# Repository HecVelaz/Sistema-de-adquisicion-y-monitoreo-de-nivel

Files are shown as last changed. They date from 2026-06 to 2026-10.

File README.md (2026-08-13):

````markdown
# Sistema de adquisición y monitoreo de nivel de agua

## Estación de medición de nivel — Arroyo Mburicao

---

## Descripción

Sistema de adquisición y monitoreo de nivel de agua desarrollado para medir el nivel de un arroyo mediante un sensor de nivel con comunicación RS485.

El sistema utiliza una PCB propia basada en ESP32-S3, almacenamiento local en tarjeta microSD, reloj de tiempo real DS3231M y transmisión de datos mediante un módem DTU GPRS hacia un servidor remoto.

Cada medición es registrada con un `timestamp` generado a partir del RTC y se guarda localmente en la tarjeta microSD. Luego, el dato es enviado al servidor con la trama:

```
d=timestamp,nivel
````

Además, el sistema implementa un mecanismo **Store and Forward**, que permite conservar los datos no enviados en caso de falla de comunicación y reenviarlos automáticamente cuando la conexión se restablece.

---
## Datos obtenidos con el sensor 
Seguimiento de los valores obtenidos por el prototipo durante aproximadamente 9 meses de seguido, datos obtenidos en la cuenca del arroyo mburicao Colegio San Ignacio de Loyolas.

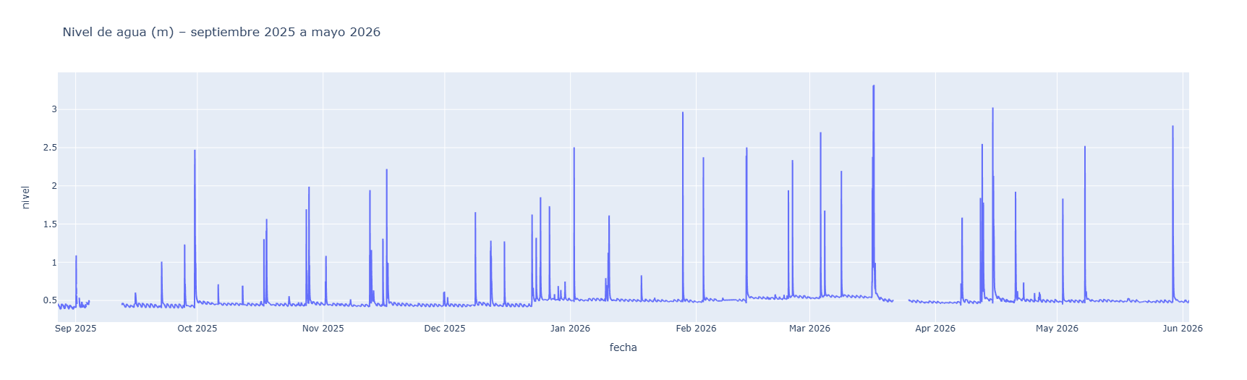
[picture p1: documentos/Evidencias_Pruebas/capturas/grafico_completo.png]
Imagen grafana

## Imágenes del hardware

| Render 3D / PCB | PCB diseñada | Placa montada |
| --- | --- | --- |
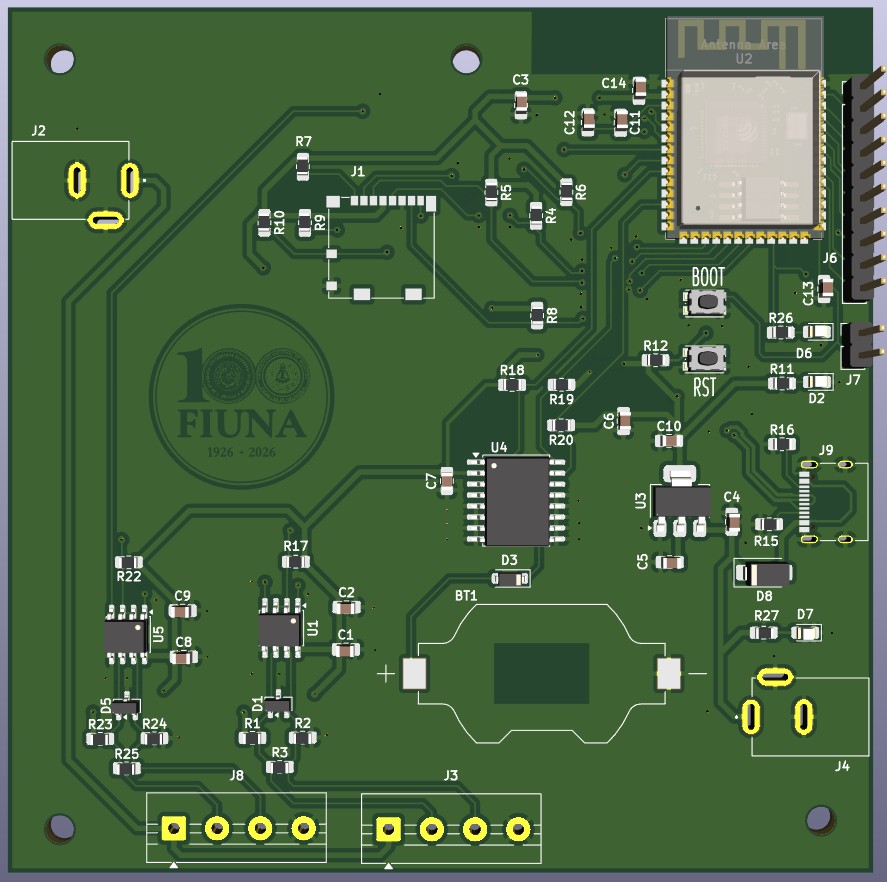
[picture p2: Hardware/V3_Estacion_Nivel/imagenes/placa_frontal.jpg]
Render 3D
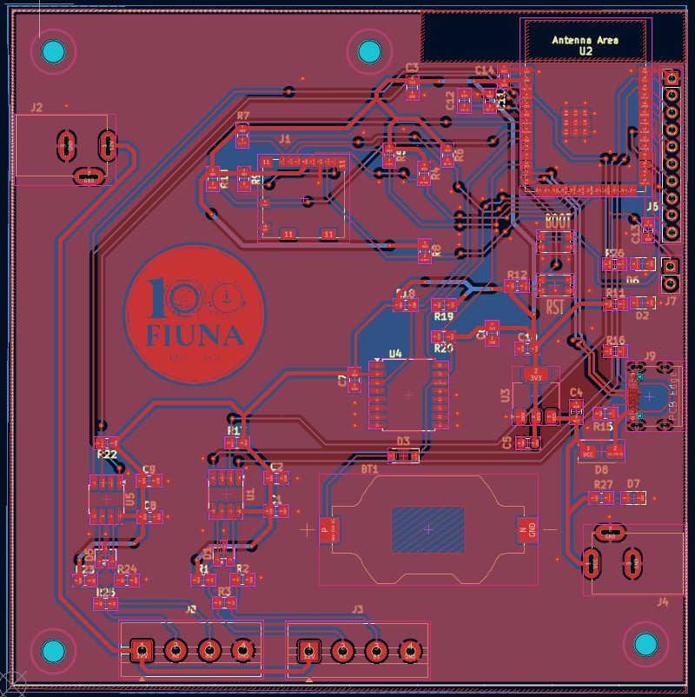
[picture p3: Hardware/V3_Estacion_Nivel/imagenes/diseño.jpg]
PCB diseñada
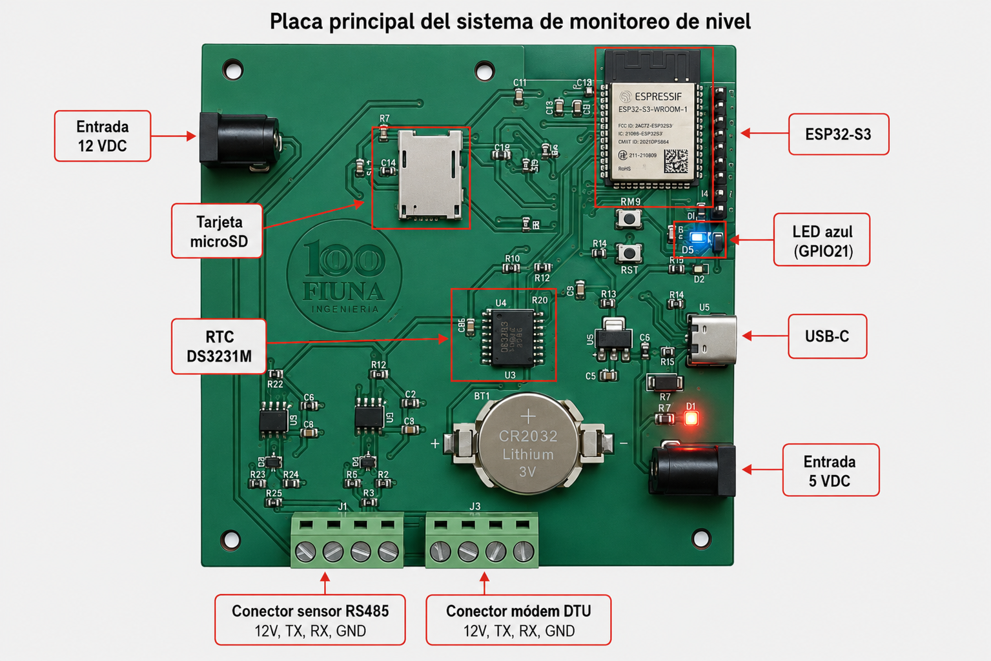
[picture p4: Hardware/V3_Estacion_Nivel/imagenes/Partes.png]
Placa montada
|  |  |  |

---

## Características principales

* Microcontrolador **ESP32-S3** con firmware desarrollado en **ESP-IDF**.
* Sensor de nivel de agua con comunicación **RS485 / Modbus RTU**.
* Transmisión de datos mediante **módem DTU GPRS RS485**.
* Almacenamiento local en tarjeta **microSD**.
* Registro histórico en archivo `datalog.csv`.
* Cola de datos pendientes en archivo `temp.csv`.
* Reloj de tiempo real **DS3231M** para generación de timestamps.
* Alimentación mediante **mini UPS**.
* Salida de **12 V** para sensor de nivel y módem DTU.
* Alimentación de **5 V** para el ESP32-S3.
* Regulación interna de **3.3 V** para periféricos.
* Indicadores LED de alimentación y funcionamiento.
* LED azul conectado al **GPIO21** como indicador de lectura válida.
* Mecanismo **Store and Forward** para evitar pérdida de datos.
* Reenvío automático de datos pendientes.
* Repositorio organizado en documentación, hardware, software y evidencias.

---

## Estructura del repositorio

```text
Sistema de adquisicion y monitoreo de nivel/
│
├── documentos/
│   │
│   ├── Evidencias_Pruebas/
│   │   │
│   │   ├── capturas/
│   │   │   ├── Placa.jpg
│   │   │   ├── Partes.png
│   │   │   ├── store_forward.png
│   │   │   ├── datalog_csv.png
│   │   │   └── ...
│   │   │
│   │   └── videos/
│   │       ├── prueba_sensor.mp4
│   │       ├── prueba_sdcard.mp4
│   │       ├── prueba_modem.mp4
│   │       ├── prueba_integrada.mp4
│   │       └── ...
│   │
│   └── reportes/
│       ├── informe_parcial/
│       ├── informe_final/
│       └── ...
│
├── Hardware/
│   │
│   ├── V3_Estacion_Nivel/
│   │   │
│   │   ├── imagenes/
│   │   │   ├── placa_frontal.jpg
│   │   │   ├── placa_posterior.jpg
│   │   │   ├── diseño.jpg
│   │   │   ├── Partes.png
│   │   │   └── ...
│   │   │
│   │   ├── planos/
│   │   ├── step/
│   │   ├── Librerias Kicad/
│   │   └── fabrication_files_G10/
│   │
│   └── Estacion_Nivel_V3.csv
│
├── Software/
│   │
│   ├── Firmware_Final/
│   │   │
│   │   ├── components/
│   │   │   │
│   │   │   ├── led/
│   │   │   │   ├── led_blink.c
│   │   │   │   └── led_blink.h
│   │   │   │
│   │   │   ├── modem_dtu/
│   │   │   │   ├── modem_dtu.c
│   │   │   │   └── modem_dtu.h
│   │   │   │
│   │   │   ├── reloj/
│   │   │   │   ├── reloj.c
│   │   │   │   └── reloj.h
│   │   │   │
│   │   │   ├── sdcard/
│   │   │   │   ├── sdcard.c
│   │   │   │   └── sdcard.h
│   │   │   │
│   │   │   └── sensor_rs485/
│   │   │       ├── sensor_rs485.c
│   │   │       └── sensor_rs485.h
│   │   │
│   │   ├── src/
│   │   │   └── main.c
│   │   │
│   │   ├── CMakeLists.txt
│   │   ├── platformio.ini
│   │   └── sdkconfig.freenove_esp32_s3_wroom
│   │
│   └── Firmware_Pruebas/
│       │
│       ├── components/
│       │   │
│       │   ├── led/
│       │   │   ├── led_blink.c
│       │   │   └── led_blink.h
│       │   │
│       │   ├── modem_dtu/
│       │   │   ├── dtu.c
│       │   │   └── dtu.h
│       │   │
│       │   ├── reloj/
│       │   │   ├── reloj.c
│       │   │   └── reloj.h
│       │   │
│       │   ├── sdcard/
│       │   │   ├── sdcard.c
│       │   │   └── include/
│       │   │       └── sdcard.h
│       │   │
│       │   └── sensor_rs485/
│       │       └── sensor_rs485.c
│       │
│       ├── src/
│       │   └── main.c
│       │
│       ├── CMakeLists.txt
│       ├── platformio.ini
│       └── sdkconfig.freenove_esp32_s3_wroom
│
├── .gitattributes
├── LICENSE
└── README.md
```

---

## Hardware

### Diagrama de bloques

```text
                    Mini UPS
             ┌────────┼────────┐
             │        │        │
            12 V     12 V      5 V
             │        │        │
             ▼        ▼        ▼
     Sensor de     Módem     ESP32-S3
     nivel RS485   DTU       Control principal
             │        │        │
             │        │        ├── RTC DS3231M   ── I2C
             │        │        ├── microSD       ── SPI
             │        │        ├── LED indicador ── GPIO21
             │        │        ├── Sensor nivel  ── RS485 / UART1
             │        │        └── Módem DTU     ── RS485 / UART2
             │        │
             │        └────── Internet / GPRS
             │                 │
             ▼                 ▼
        Medición de nivel   Servidor remoto
```

---

## Alimentación

| Módulo | Tensión | Descripción |
| --- | ---: | --- |
| Sensor de nivel RS485 | 12 V | Alimentación del sensor de medición de nivel |
| Módem DTU GPRS | 12 V | Alimentación del módulo de comunicación remota |
| ESP32-S3 | 5 V | Alimentación mediante jack o USB-C |
| RTC DS3231M | 3.3 V | Alimentación desde regulación interna |
| microSD | 3.3 V | Alimentación desde regulación interna |
| LED indicador | 3.3 V | Indicador visual de funcionamiento |

---

## Pinout principal

| Módulo | Señal | GPIO ESP32-S3 | Interfaz | Función |
| --- | --- | ---: | --- | --- |
| Sensor nivel RS485 | TX / DI | GPIO1 | UART1 TX | Envío de comando Modbus |
| Sensor nivel RS485 | RX / RO | GPIO2 | UART1 RX | Recepción de respuesta |
| Sensor nivel RS485 | DE/RE | GPIO4 | Control RS485 | Control de transmisión y recepción |
| Módem DTU | TX / DI | GPIO5 | UART2 TX | Envío de trama al módem |
| Módem DTU | RX / RO | GPIO6 | UART2 RX | Recepción de respuesta |
| Módem DTU | DE/RE / RTS | GPIO7 | Control RS485 | Control de dirección RS485 |
| RTC DS3231M | SDA | GPIO8 | I2C SDA | Datos del RTC |
| RTC DS3231M | SCL | GPIO9 | I2C SCL | Reloj del RTC |
| RTC DS3231M | SQW/INT | GPIO16 | Entrada digital | Señal reservada |
| microSD | CS | GPIO10 | SPI CS | Selección de tarjeta |
| microSD | MOSI | GPIO11 | SPI MOSI | Datos hacia microSD |
| microSD | CLK | GPIO12 | SPI CLK | Reloj SPI |
| microSD | MISO | GPIO13 | SPI MISO | Datos desde microSD |
| microSD | DET | GPIO15 | Entrada digital | Detección de tarjeta |
| LED indicador | LED Blink | GPIO21 | GPIO salida | Indicador de lectura válida |

---

## Software

El firmware del ESP32-S3 está desarrollado en lenguaje C utilizando **PlatformIO** con framework **ESP-IDF**.

### Módulos del firmware

| Módulo | Descripción |
| --- | --- |
| `main.c` | Flujo principal del sistema: inicialización, medición, guardado y envío |
| `reloj` | Manejo del RTC DS3231M y generación de timestamp |
| `sensor_rs485` | Lectura del sensor de nivel mediante RS485 |
| `sdcard` | Montaje de microSD, escritura en `datalog.csv` y manejo de `temp.csv` |
| `modem_dtu` | Envío de trama al servidor mediante módem DTU |
| `led` | Indicador visual de lectura válida o actividad del sistema |

---

## Ciclo de operación

El ciclo principal del sistema se resume en:

```text
Medir → Validar → Guardar → Enviar → Confirmar → Reenviar si falló
```

### Flujo general

```text
Inicio
  ↓
Inicializar RTC, SD, sensor RS485, módem DTU, LED y tarea de pendientes
  ↓
Leer hora actual del RTC
  ↓
Esperar próximo intervalo de medición
  ↓
Leer nivel con sensor RS485
  ↓
¿Lectura válida?
  ├── NO → Reintentar lectura
  │          ↓
  │      ¿Falló luego de los intentos?
  │          ├── SÍ → Registrar error y esperar próximo intervalo
  │          └── NO → Continuar
  │
  └── SÍ
       ↓
Generar timestamp
  ↓
Guardar dato en datalog.csv
  ↓
Generar trama d=timestamp,nivel
  ↓
Enviar trama mediante módem DTU
  ↓
¿Servidor responde OK?
  ├── SÍ → Ciclo finalizado y esperar próximo intervalo
  └── NO → Guardar dato en temp.csv
            ↓
         Queda pendiente para Store and Forward
            ↓
         Esperar próximo intervalo
```

---

## Formato de datos

### Registro local en microSD

Archivo:

```text
datalog.csv
```

Formato:

```text
timestamp,nivel
```

Ejemplo:

```text
1779617700,0.931
```

---

### Datos pendientes

Archivo:

```text
temp.csv
```

Formato:

```text
timestamp,nivel
```

Este archivo almacena temporalmente los datos que no pudieron ser enviados al servidor.

---

### Trama enviada al servidor

Formato:

```text
d=timestamp,nivel
```

Ejemplo:

```text
d=1779617700,0.931
```

Respuesta esperada del servidor:

```text
OK
```

---

## Store and Forward

El mecanismo **Store and Forward** permite evitar la pérdida de datos cuando ocurre una falla de comunicación.

Funcionamiento:

1. El sistema mide el nivel de agua.
2. El dato se guarda siempre en `datalog.csv`.
3. El sistema intenta enviarlo al servidor.
4. Si el servidor responde `OK`, el ciclo finaliza correctamente.
5. Si el servidor no responde o existe error de comunicación, el dato se guarda en `temp.csv`.
6. Una tarea en segundo plano revisa los datos pendientes.
7. Cuando la comunicación se restablece, los datos se reenvían automáticamente.
8. Al recibir `OK`, el dato pendiente se elimina de `temp.csv`.

---

## Pruebas realizadas

| Prueba | Descripción | Estado |
| --- | --- | --- |
| Sensor RS485 | Lectura de nivel mediante comunicación Modbus RTU | Correcto |
| RTC DS3231M | Lectura de fecha y hora mediante I2C | Correcto |
| microSD | Detección, montaje, escritura y lectura de archivos | Correcto |
| Módem DTU | Envío de trama `d=timestamp,nivel` al servidor | Correcto |
| Sistema integrado | Lectura, almacenamiento y transmisión completa | Correcto |
| Store and Forward | Guardado y reenvío de datos pendientes | Correcto |

---

## Resultados

Durante las pruebas finales se verificó que el sistema puede:

* Medir correctamente el nivel de agua.
* Generar un timestamp para cada medición.
* Guardar datos localmente en `datalog.csv`.
* Enviar datos al servidor remoto.
* Detectar fallas de comunicación.
* Guardar datos no enviados en `temp.csv`.
* Reenviar automáticamente datos pendientes.
* Mantener el timestamp original de cada medición reenviada.

---

## Evidencias

Las evidencias del funcionamiento del sistema se encuentran en:

```text
documentos/Evidencias_Pruebas/
```

Estructura recomendada:

```text
documentos/Evidencias_Pruebas/
│
├── capturas/
│   ├── Placa.jpg
│   ├── Partes.png
│   ├── datalog_csv.png
│   ├── store_forward.png
│   └── ...
│
└── videos/
    ├── prueba_sensor.mp4
    ├── prueba_sdcard.mp4
    ├── prueba_modem.mp4
    ├── prueba_integrada.mp4
    └── ...
```

Cada carpeta puede incluir capturas, logs y enlaces a videos de prueba.

---

## Costos

La lista de materiales y costos se encuentra en la carpeta de hardware del proyecto.

Ruta sugerida:

```text
Hardware/V3_Estacion_Nivel/
```

Archivo de costos o BOM:

```text
Estacion_Nivel_V3.csv
```

También pueden incluirse archivos adicionales dentro de:

```text
Hardware/V3_Estacion_Nivel/fabrication_files_G10/
```

---

## Requisitos de desarrollo

* Visual Studio Code
* PlatformIO
* ESP-IDF
* ESP32-S3
* Tarjeta microSD
* Sensor de nivel RS485
* Módem DTU GPRS RS485
* RTC DS3231M
* Mini UPS

---

## Compilación y carga

Desde PlatformIO:

```bash
pio run
pio run --target upload
pio device monitor
```

También puede utilizarse el entorno gráfico de PlatformIO en Visual Studio Code.

---

## Equipo

| Integrante | Contacto |
| --- | --- |
| Héctor Dejesús Velázquez Ojeda | [hvelazquez@fiuna.edu.py](mailto:hvelazquez@fiuna.edu.py) |
| Mathias Ramón Aguilar DelValle | [maguilar@fiuna.edu.py](mailto:maguilar@fiuna.edu.py) |
| Mauricio Iván Tullo Estigarribia | [mauritullo@fiuna.edu.py](mailto:mtullo@fiuna.edu.py) |

Institución: Universidad Nacional de Asunción — Facultad de Ingeniería
Carrera: Ingeniería Mecatrónica
Cátedra: Proyecto 3

---

## Licencia
* Firmware: MIT
* Documentación: MIT

---

## Estado del proyecto

El proyecto se encuentra en etapa funcional, con pruebas aisladas e integradas realizadas correctamente.

El sistema permite adquirir, almacenar y transmitir datos de nivel de agua, incorporando respaldo local y reenvío automático ante fallas de comunicación.

```
```

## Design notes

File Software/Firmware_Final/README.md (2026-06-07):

# Firmware Final

Esta carpeta contiene la versión final del firmware desarrollado para la estación de adquisición de nivel.

## Descripción

El firmware fue desarrollado utilizando **PlatformIO** y el framework **ESP-IDF** para el microcontrolador **ESP32-S3-WROOM-1**.

Las principales funciones implementadas son:

* Lectura del sensor ultrasónico de nivel mediante comunicación RS485.
* Obtención de fecha y hora mediante el RTC DS3231M.
* Almacenamiento local de mediciones en tarjeta microSD.
* Envío de datos al servidor remoto mediante módem DTU GPRS.
* Implementación del mecanismo **Store and Forward** para recuperación automática de datos pendientes.
* Ejecución de tareas en segundo plano mediante FreeRTOS.
* Protección de recursos compartidos mediante mutex.
* Indicadores visuales mediante LED de estado.

## Estructura principal

* `src/` : Código fuente principal.
* `components/` : Módulos desarrollados para sensor, RTC, SD, DTU y periféricos.
* `include/` : Archivos de cabecera.
* `platformio.ini` : Configuración del proyecto PlatformIO.

## Estado

Versión funcional validada mediante pruebas integradas de lectura, almacenamiento local, transmisión remota y recuperación de datos pendientes.
## Nota

A diferencia de la carpeta `Firmware_Pruebas`, el firmware contenido en esta carpeta corresponde a la versión final integrada del sistema y no requiere habilitar o deshabilitar módulos manualmente para su funcionamiento normal.

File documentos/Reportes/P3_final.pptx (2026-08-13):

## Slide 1

Sistema de adquisición y monitoreo de nivel de agua

Héctor Velázquez, Mathias Aguilar , Mauricio Tullo.

Facultad de Ingeniería , Universidad Nacional de Asunción.

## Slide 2

Esquema

Introducción y Contexto

Objetivo del proyecto

Sistema propuesto

Diseño Electrónico y PCB

Integración física y costos

Firmware

Pruebas y resultados

Conclusione y trabajos futuros

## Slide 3

Introducción y contexto del problema

Contexto

Monitoreo de cauces urbanos

Registro histórico del nivel

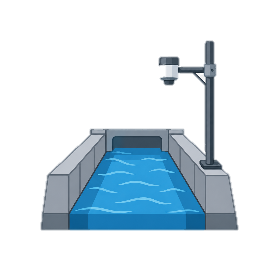
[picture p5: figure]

Problema

Aumento rápido del nivel

Riesgo de inundación

Necesidad

Datos periódicos y confiables

Base para alerta y predicción

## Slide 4

Objetivo del proyecto

Desarrollar una estación basada en ESP32-S3 capaz de medir, almacenar y transmitir datos de nivel de agua hacia un servidor remoto.

Con respaldo local ante fallas de comunicación.

Medir

Nivel de agua
mediante RS485

Almacenar

Registro local en microSD

Transmitir

Datos hacia servidor remoto

Respaldar

Datos ante fallas de comunicación

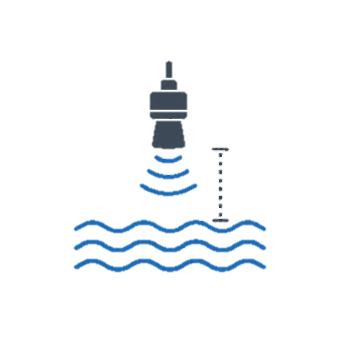
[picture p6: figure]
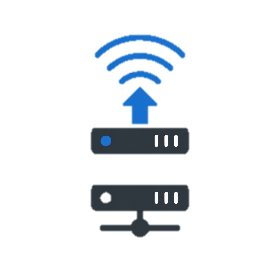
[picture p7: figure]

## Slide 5

Sistema propuesto

Arquitectura de adquisición, almacenamiento y transmisión.

Sensor de Nivel
Medición de nivel

RTC DS3231M
Fecha y hora

ESP32-S3
Unidad Central

MicroSD
Registro local

Módem DTU GPRS
Transmisión de datos

Servidor remoto
Recepción de datos

Mini UPS | Alimentación del sistema: 12 V / 5 V

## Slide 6

Esquemas electrónicos

Subsistemas implementados en la PCB.

Alimentación

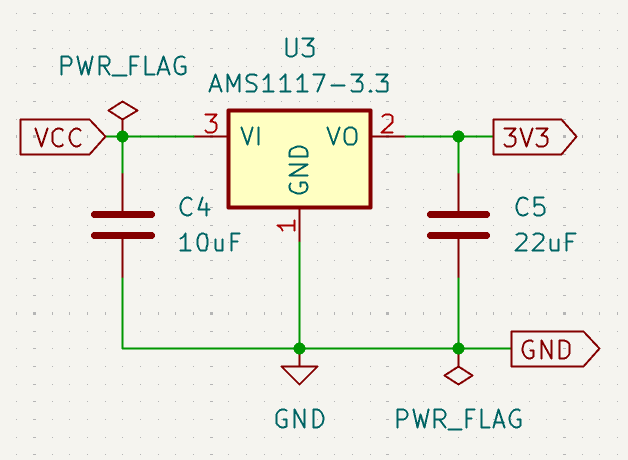
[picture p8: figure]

ESP32-S3

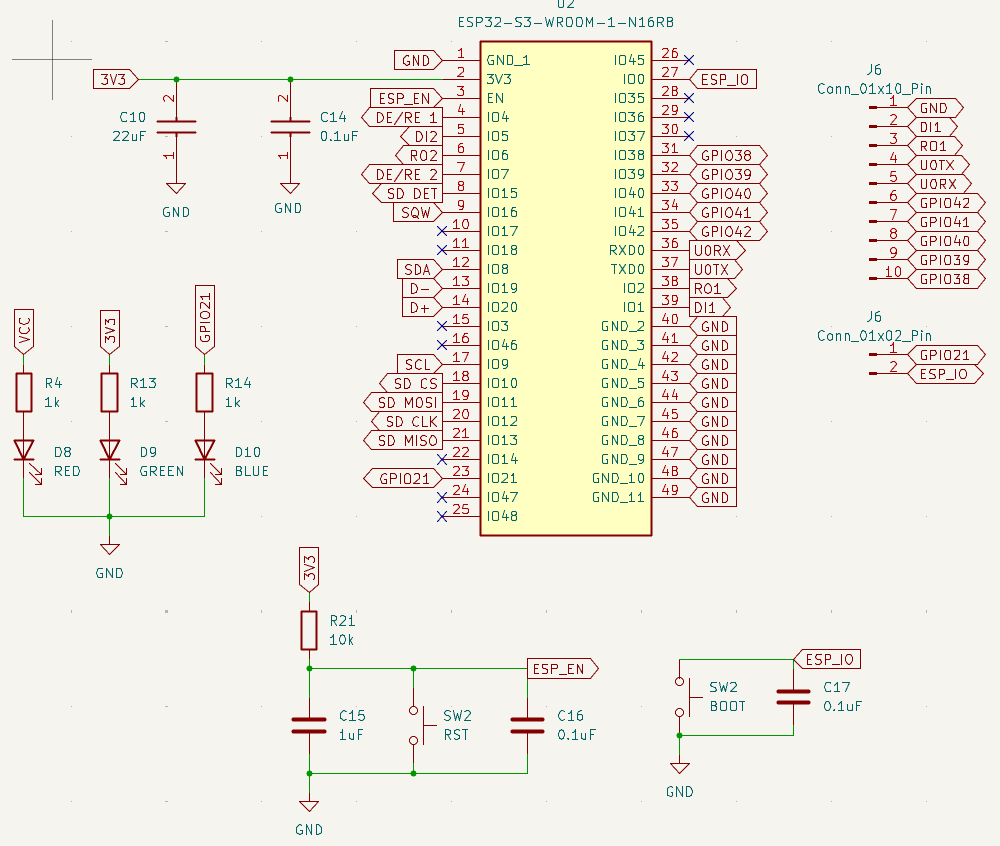
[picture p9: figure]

RTC DS3231M

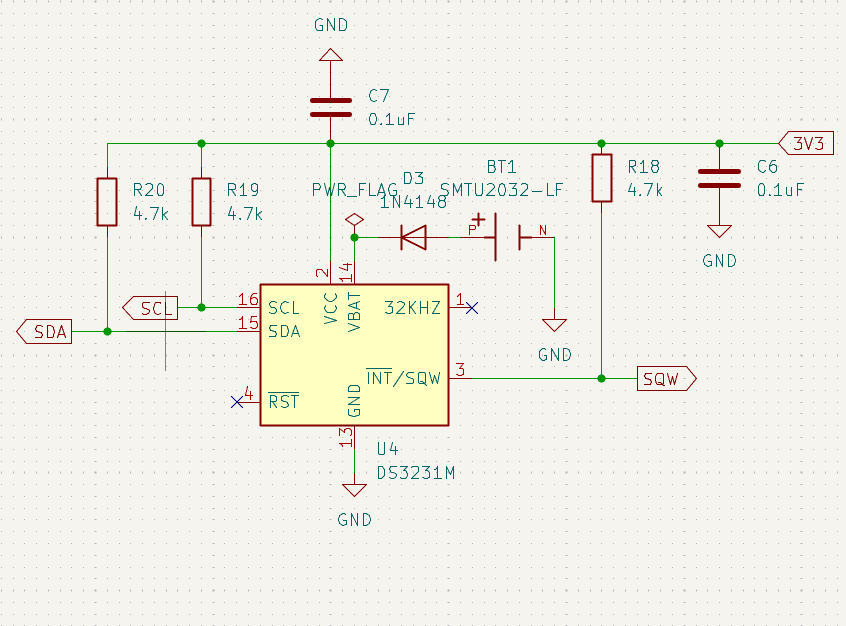
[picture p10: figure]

microSD

USB-C

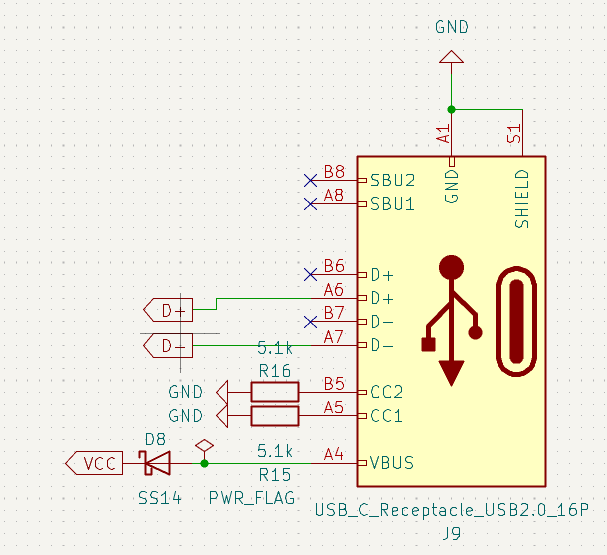
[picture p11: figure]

Transceptor TTL-RS485

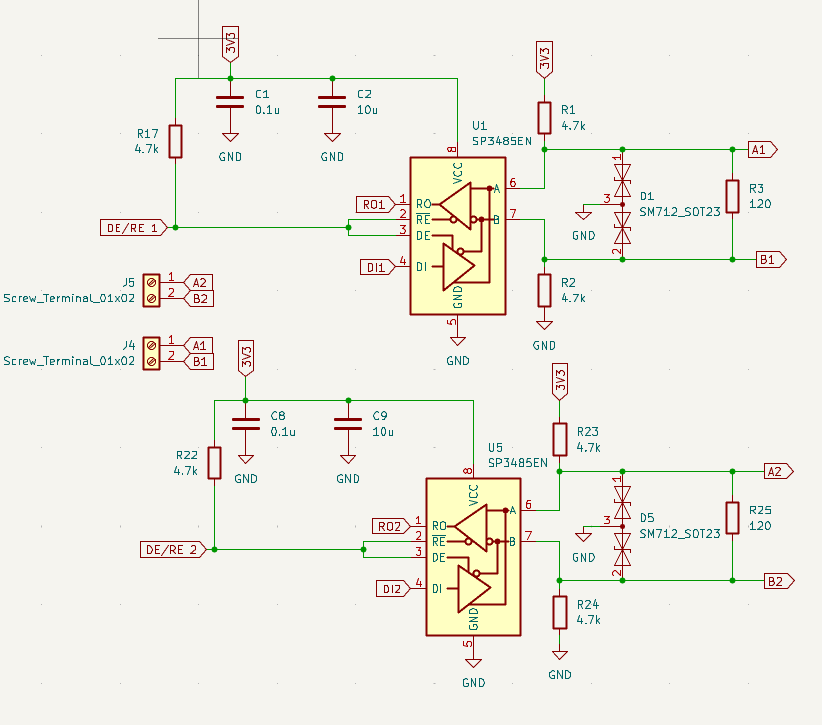
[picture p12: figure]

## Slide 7

Alimentación

Componentes utilizados
- AMS1117-3.3
- Capacitor 10 µF
- Capacitor 22 µF
- Entrada VCC
- Salida 3V3
- GND

Se utilizó el AMS1117-3.3 para generar una línea estable de 3.3 V a partir de VCC.
Esta tensión alimenta los periféricos de baja potencia del sistema, como RTC y microSD.
Los capacitores de entrada y salida permiten estabilizar la regulación y reducir variaciones de tensión.

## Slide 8

ESP32-S3

Componentes utilizados
• ESP32-S3-WROOM-1
• LED rojo
• LED verde
• LED azul
• Pulsador BOOT
• Pulsador RESET
• Resistencias limitadoras
• Capacitores de desacoplo

El ESP32-S3 funciona como unidad central del sistema, coordinando la lectura del sensor, el RTC, la microSD y el módem DTU.
Los LEDs permiten verificar visualmente estados de alimentación y operación, mientras que los pulsadores BOOT y RESET facilitan la carga y reinicio del firmware.

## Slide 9

RTC DS3231M

Componentes utilizados
• RTC DS3231M
• Batería CR2032
• Portapila SMTU2032
• Resistencias pull-up 4.7 kΩ
• Capacitores 0.1 µF
• Diodo 1N4148
• Línea I2C: SDA / SCL

Referencia funcional: módulo comercial RTC DS3231.
El diseño implementado integra únicamente el RTC DS3231M, la alimentación, las líneas I2C y el respaldo con batería.
No se incluyó la memoria EEPROM del módulo comercial, ya que no era necesaria para la función de timestamp del sistema.

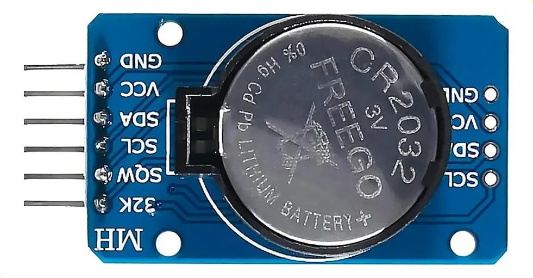
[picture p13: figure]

El bloque RTC se tomó como referencia funcional de módulos comerciales DS3231, adaptando solo las conexiones necesarias para la PCB: SDA, SCL, 3.3 V, GND y respaldo con batería.

Referencia funcional: módulo comercial RTC DS3231.

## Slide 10

microSD

Componentes utilizados
• Conector microSD
• Resistencias pull-up 10 kΩ
• Capacitor 0.1 µF
• Interfaz SPI: CS, MOSI, CLK, MISO
• Señal de detección SD_DET
• Alimentación 3.3 V

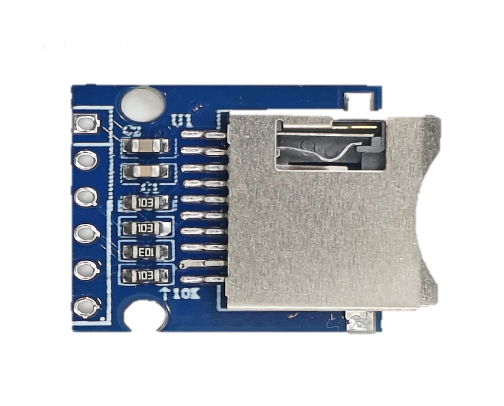
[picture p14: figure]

La microSD permite conservar localmente las mediciones del sistema en datalog.csv y los datos pendientes en temp.csv.
La interfaz SPI permite la lectura y escritura de archivos, mientras que SD_DET verifica si la tarjeta está insertada.

Referencia funcional: módulo comercial microSD SPI.

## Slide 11

USB-C

Componentes utilizados
• Conector USB-C
• VBUS / VCC
• D+ y D-
• Resistencias 5.1 kΩ
• Diodo SS14
• GND / SHIELD

El USB-C se utiliza como entrada de 5 V y conexión de comunicación.
Las resistencias de 5.1 kΩ en CC1/CC2 permiten la detección del dispositivo, mientras que el diodo SS14 protege la línea de alimentación.

Referencia funcional: conector USB-C USB 2.0.

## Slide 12

Transceptor TTL-RS485

Componentes utilizados
• Transceptores SP3485EN
• Borneras A/B para RS485
• Resistencias de 4.7 kΩ
• Resistencias de 120 Ω
• Capacitores 0.1 µF y 10 µF
• Diodos de protección SM712
• Señales DI, RO y DE/RE

El bloque TTL–RS485 adapta las señales UART del ESP32-S3 al bus diferencial RS485.
Se implementaron dos canales: uno para el sensor de nivel y otro para el módem DTU.
Las resistencias y diodos de protección ayudan a estabilizar y proteger la comunicación.

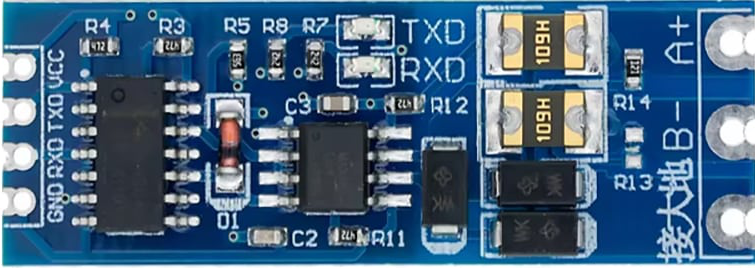
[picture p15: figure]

Referencia funcional: módulo comercial TTL–RS485 tipo MAX485.

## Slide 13

Diseño PCB

Validación del ruteo y disposición física antes del montaje.

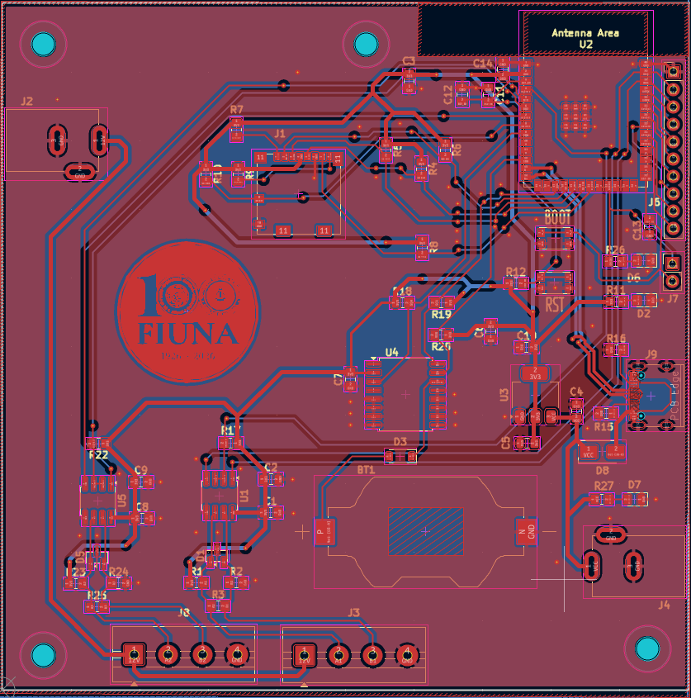
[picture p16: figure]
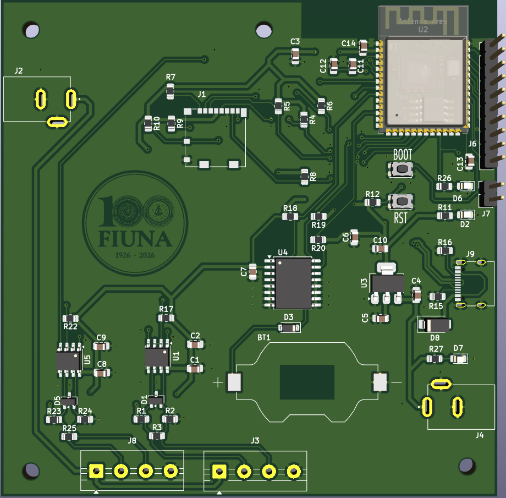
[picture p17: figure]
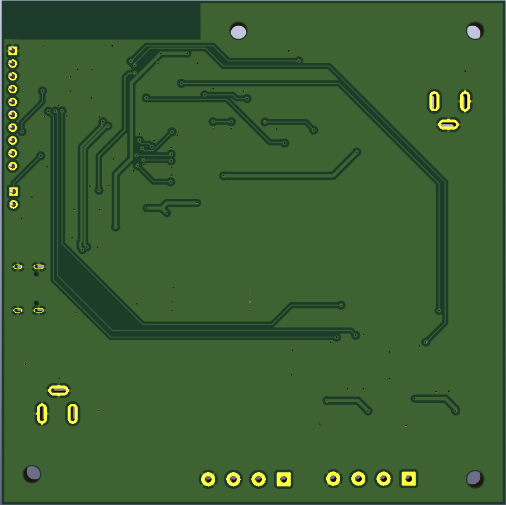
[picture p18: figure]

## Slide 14

Diseño electrónico

PCB principal integrada para conexión de módulos y alimentación.

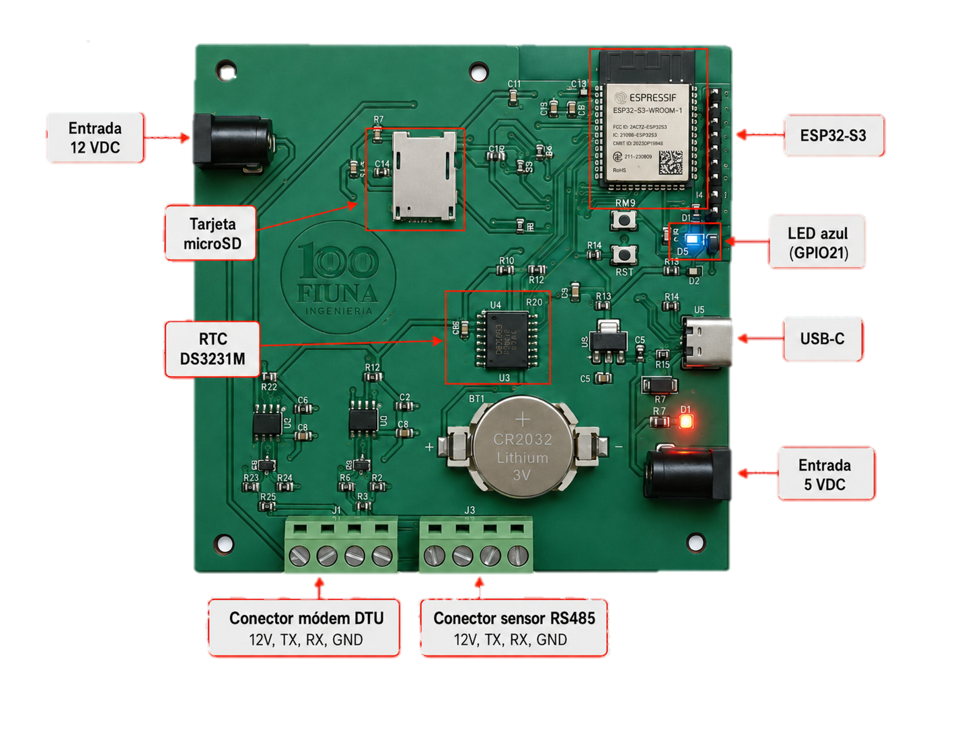
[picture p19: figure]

- ESP32-S3 como unidad central.
- RTC DS3231M y microSD incorporados.
- Conectores RS485 para sensor y módem.
- Entradas de alimentación 12 V y 5 V

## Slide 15

INTEGRACIÓN FÍSICA DEL SISTEMA

Integración física de los módulos principales del prototipo.

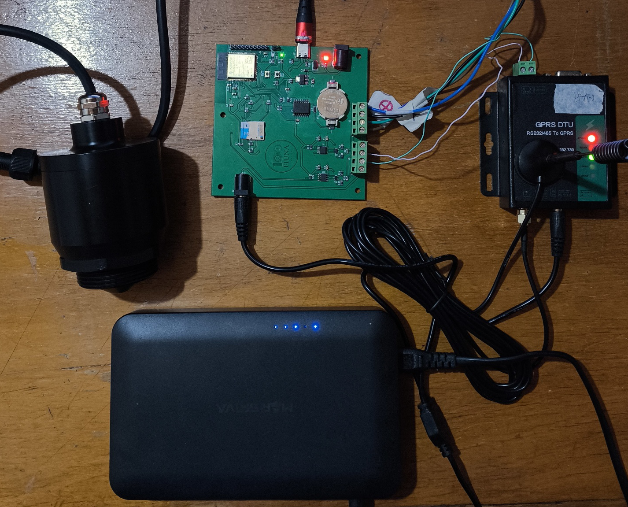
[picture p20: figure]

Componentes integrados

• Sensor de nivel RS485
• PCB principal del sistema
• Módem DTU GPRS
• Alimentación mediante Mini UPS

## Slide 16

Costo del proyecto

Estimación de materiales utilizados en el prototipo.

Ítem | Cantidad | Costo unitario | Costo total
PCB fabricada | 1 | 27,6 | 27,6
Microcontrolador ESP32-S3-WROOM-1 | 1 | 6,71 | 6,71
Transceptor RS485 (SP3485EN) | 2 | 0,8 | 1,6
Sensor de nivel RS485 (Laboratorio) | 1 | 196,33 | 196,33
Módem DTU GPRS RS485 (Laboratorio) | 1 | 21 | 21
Módulo RTC DS3231M | 1 | 13,6 | 13,6
Conector microSD | 1 | 2,55 | 2,55
Mini UPS (Laboratorio) | 1 | 46,63 | 46,63
Portapila y batería CR2032 (SMTU2032) | 1 | 2,36 | 2,36
Pulsadores SMD (RST y BOOT - B3U-1000P) | 2 | 0,8 | 1,6
Capacitores SMD (0,1 µF, 1 µF, 10 µF) | 11 | 0,34 | 3,81
Resistencias SMD varias | 16 | 0,98 | 15,68
Pasta de soldar (SN63/PB37 Tipo 4) | 1 | 12,27 | 12,27
Total comprado / incremental | 37 | 68,01 | 87,78
Total de materiales del laboratorio | 3 | 263,96 | 263,96
Total general estimado | 40 | 331,97 | 351,74

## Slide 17

Comunicaciones y alimentación

Interfaces utilizadas y niveles de tensión por módulo.

Módulo | Comunicación | Alimentación | Función
Sensor de nivel | RS485 / UART1 | 12 V | Medición de nivel
Módem DTU | RS485 / UART2 | 12 V | Envío de datos
RTC DS3231M | I2C | 3,3 V | Fecha y hora
microSD | SPI | 3,3 V | Almacenamiento
ESP32-S3 | UART / I2C / SPI / GPIO | 5 V / 3,3 V | Control central

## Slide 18

Ciclo operativo

Flujo principal de medición, almacenamiento y transmisión.

RTC
Genera timestamp

Sensor RS485
Lee el nivel de agua

microSD
Guarda datalog.csv

Módem DTU
d=timestamp,nivel

Si falla el envío

Servidor
Respuesta OK

Store and Forward
temp.csv
Reenvío automático

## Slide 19

Arquitectura del firmware

Firmware modular en ESP-IDF

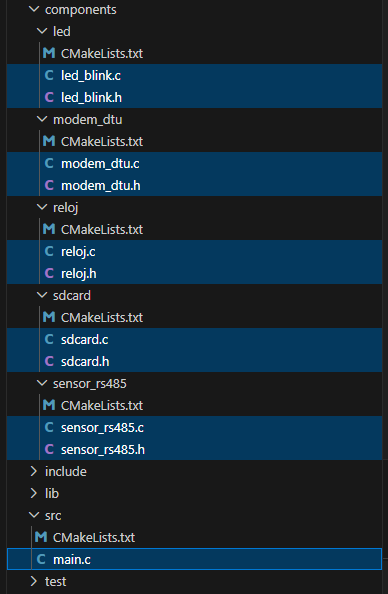
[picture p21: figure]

El firmware se dividió en componentes independientes para facilitar pruebas aisladas, mantenimiento e integración final.
Cada módulo encapsula una función específica y es llamado desde main.c.

- led_blink → señalización
- modem_dtu → envío al servidor
- reloj → fecha y hora
- sdcard → registro local
- sensor_rs485 → lectura de nivel

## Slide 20

Secuencia inicial

Secuencia inicial del firmware.

Inicio ESP32

Inicializar
Componentes
- RTC
- microSD
- Sensor
- Modem
- LED

Crear Mutex del DTU

Crear task_pendientes
Segundo plano

Loop principal
De medición

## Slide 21

Loop principal de medición

Medición, almacenamiento local y envío del dato actual.

Loop principal

Generar timestamp

Esperar s faltantes, volver al inicio

Leer hora del
RTC

Guardar en datalog.csv

Es momento del
Próximo Slot redondo ?

NO

Se envía al servidor
Con mutex

SI

Servidor respondió OK?

SI

Ciclo terminado

Leer sensor , hasta 3 intentos

NO

Lectura válida?

NO

nivel= -1.0

Guardar en temp.csv

Blink LED
Lectura válida

SI

Esperar 1 s y volver al inicio del loop

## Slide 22

Reenvío de pendientes y mutex

Store and forward ejecutado en segundo plano.

Task_pendientes BG

Esperar 5s , volver al inicio

Tomar mutex

Leer hora del
RTC

DTU libre?

NO

Se mantiene el pendiente en temp.csv
Esperar 5s y volver

Calcular tiempo hasta el próximo slot

Enviar pendiente

SI

Existe tiempo ?
Ej=mas de 35s

NO

Servidor respondió OK?

Existe dato en temp.csv?

SI

NO

Se mantiene el pendiente en temp.csv

Esperar 5s , volver al inicio

NO

Eliminar primer registro de temp.

SI

Leer primer pendiente de temp.csv

SI

Esperar 5 s y volver al inicio del loop

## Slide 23

Formato de datos

Estructura utilizada para almacenamiento local y transmisión al servidor.

Registro local

Archivo: datalog.csv

Formato: timestamp,nivel

Ejemplo: 1779617700,0.931

Envío al servidor

Trama: d=timestamp,nivel

Ejemplo: d=1779617700,0.931

timestamp = UNIX | nivel: metros

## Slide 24

Store and Forward

Mecanismo de respaldo ante fallas de comunicación.

Falla de envío

Servidor no responde o falla de comunicación

Respaldo local

Dato guardado en temp.csv

Reenvío
automático

Se transmite cuando vuelve la conexión

El timestamp original se conserva para evitar pérdida de trazabilidad

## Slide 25

Pruebas y validación

Validación por módulos y prueba del sistema completo.

Pruebas aisladas

• Sensor RS485: lectura de nivel
• RTC DS3231M: fecha y hora
• microSD: escritura y lectura
• Módem DTU: envío de trama
• LED: señalización

Prueba integrada

• Inicialización completa
• Lectura periódica de nivel
• Generación de timestamp
• Registro en datalog.csv
• Envío d=timestamp,nivel
• Respaldo en temp.csv
• Reenvío automático

Resultado: el sistema midió, almacenó, transmitió y recuperó datos pendientes correctamente.

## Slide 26

Resultados y evidencias

Validación práctica de lectura, almacenamiento y transmisión.

Registro local

Archivo: datalog.csv
Formato: timestamp,nivel
Dato registrado correctamente

Lectura sensor

ESP32-S3: 1.100 m
App sensor: 1.1 m

Envío al servidor

Trama: d=1781220000,1.100
Respuesta: OK
Dato recibido en base de datos

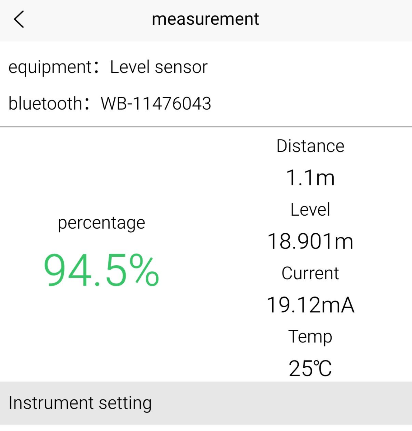
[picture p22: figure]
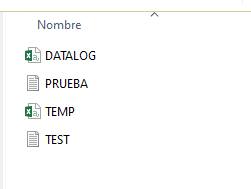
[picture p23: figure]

Resultado: lectura validada, registro local correcto y transmisión aceptada por el servidor.

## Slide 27

Conclusiones

Síntesis de los resultados obtenidos.

Sistema funcional

Se desarrolló una estación de monitoreo de nivel de agua basada en ESP32-S3.

Integración completa

Se integraron sensor RS485, RTC DS3231M, microSD, módem DTU GPRS y alimentación en una PCB propia.

Registro y transmisión

El sistema registra mediciones en microSD y transmite la trama d=timestamp,nivel al servidor remoto.

Respaldo ante fallas

El mecanismo Store and Forward permite conservar datos pendientes y reenviarlos automáticamente.

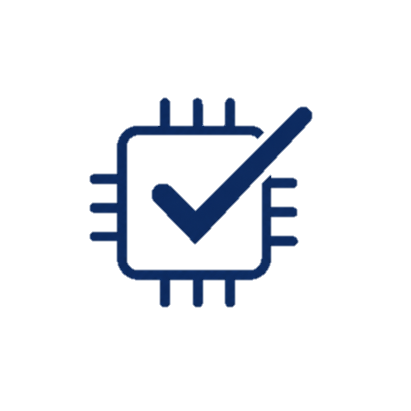
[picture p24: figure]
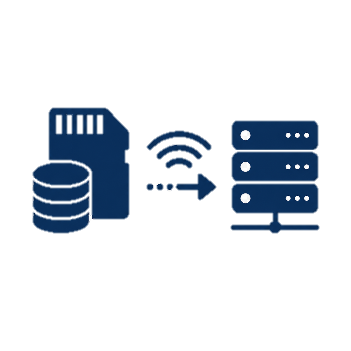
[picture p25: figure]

El prototipo validó la adquisición, almacenamiento y transmisión remota de datos de nivel.

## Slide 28

Trabajos futuros

Mejoras previstas para la evolución del sistema.

Pruebas en campo

Validar el sistema en condiciones reales de operación.

Carcasa de protección

Diseñar un gabinete resistente para instalación exterior.

Alimentación autónoma

Evaluar panel solar y batería para operación prolongada.

Visualización web

Desarrollar una interfaz para consulta y monitoreo de datos.

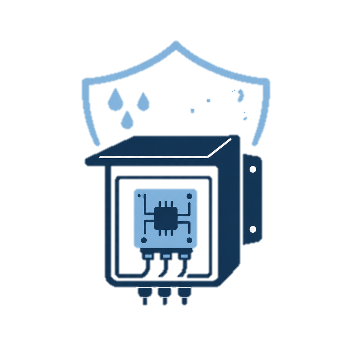
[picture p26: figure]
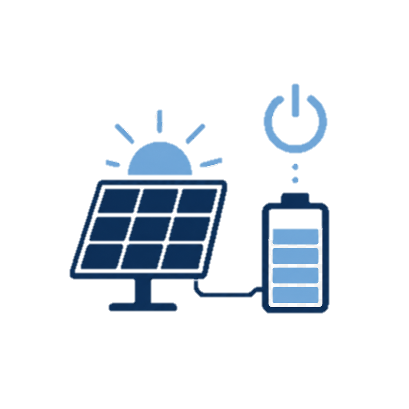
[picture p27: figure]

El sistema queda preparado para futuras pruebas de campo e integración con plataformas de monitoreo.

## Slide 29

Gracias por su atención!

Información de contacto

Mathias Aguilar
maguilar@fiuna.edu.py

Mauricio Tullo
mauritullo@fiuna.edu.py

Héctor Velázquez
hvelazquez@fiuna.edu.py

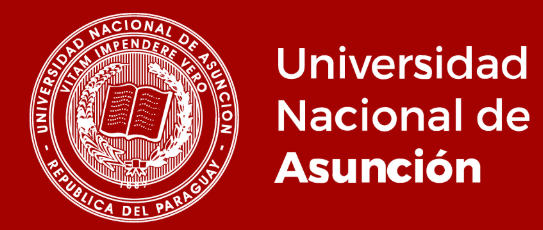
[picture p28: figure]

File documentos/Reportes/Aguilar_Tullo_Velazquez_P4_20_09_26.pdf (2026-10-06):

## Universidad Nacional de Asunción Facultad de Ingeniería

### Carrera de Ingeniería Mecatrónica

## Proyecto 4

### Primer Parcial

# Sistema de adquisición y monitoreo de nivel de agua

## Informe de proceso

### Profesores:

Prof. Ing. Federico Gaona, MSc.

### Prof. Ing. Esteban Fretes

### Alumnos:

Héctor Dejesús Velázquez Ojeda | 5.011.166
Mathias Ramón Aguilar DelValle | 4.970.804
Mauricio Iván Tullo Estigarribia | 3.782.101

### San Lorenzo, Paraguay

2026

## Índice

1. Resumen ejecutivo | 3
2. Abstract | 3
3. Estado del arte | 4
4. Descripción | 6
5. Objetivos | 6
6. Esquema general del proyecto | 7
7. Diseños | 14

8. Interfaz de visualización | 31
9. Costos | 33
10.Bibliografía | 34

## 1. Resumen ejecutivo

El presente informe de proceso corresponde a la primera entrega de Proyecto 4 y toma como base el sistema de adquisición y monitoreo de nivel de agua desarrollado previamente. El sistema utiliza un ESP32-S3 como unidad central e integra un sensor de nivel con comunicación RS485, un reloj de tiempo real DS3231M, una tarjeta microSD, un módem DTU GPRS y una fuente de alimentación mediante mini UPS.

La propuesta mantiene como funciones principales la medición periódica del nivel de agua, el registro de cada medición con fecha y hora, el almacenamiento local y la transmisión hacia un servidor remoto. Asimismo, se conserva el mecanismo Store and Forward, destinado a evitar la pérdida de información ante interrupciones temporales de comunicación.

Para Proyecto 4 se incorpora formalmente el desarrollo mecánico del prototipo. Esta etapa contempla la definición de la disposición física de los componentes, la envolvente o estructura de protección, los elementos de montaje y fijación, las uniones, los accesos para cableado y mantenimiento, así como la documentación mediante bocetos, vistas, renderizados y dibujos técnicos acotados.

En esta primera entrega se presentan los antecedentes, la arquitectura general, el diseño electrónico ya desarrollado, la estructura prevista para el diseño mecánico y la tabla de costos. Los espacios correspondientes a los modelos CAD, renderizados, vistas 2D y láminas técnicas quedan definidos en el documento para ser completados a medida que avance el diseño mecánico.

## 2. Abstract

This progress report corresponds to the first submission of Project 4 and is based on the previously developed water level acquisition and monitoring system. The system uses an ESP32-S3 as the main controller and integrates an RS485 water level sensor, a DS3231M real-time clock, a microSD card, a GPRS DTU modem, and a mini UPS power supply.

The main functions remain periodic water-level measurement, timestamp generation, local storage, and remote data transmission. The Store and Forward mechanism is also maintained to prevent data loss during temporary communication failures.

For Project 4, the mechanical development of the prototype is formally incorporated. This stage includes the definition of component layout, enclosure or protective structure, mounting and fastening elements, joints, cable access, maintenance considerations, and the preparation of sketches, rendered views, dimensioned 2D views, and technical drawings.

This first submission presents the background, general architecture, previously developed electronic design, the proposed structure for the mechanical design section, and the cost table. Reserved spaces are included for CAD models, renderings, 2D views, and technical drawings that will be added as the mechanical design progresses.

## 3. Estado del arte

En esta sección se presentan referencias relacionadas con sistemas de adquisición de datos, monitoreo remoto, sensores de nivel, microcontroladores, comunicación GPRS, almacenamiento local y visualización de información.

### 3.1. Sistemas de monitoreo de nivel de agua y predicción

El monitoreo de nivel de agua en cauces urbanos es importante para generar registros históricos, estudiar el comportamiento hidrológico y alimentar sistemas de alerta temprana. En trabajos previos relacionados con el arroyo Mburicao se abordó la predicción de niveles de agua mediante modelos de aprendizaje automático, demostrando la utilidad de contar con datos confiables y periódicos para el análisis de eventos de aumento de nivel [4].

A diferencia de un trabajo puramente orientado al modelado o predicción, el presente proyecto se enfoca en la etapa física de adquisición de datos, implementando una estación electrónica capaz de medir, almacenar y transmitir el nivel de agua de forma automática.

### 3.2. Uso del ESP32-S3 en sistemas embebidos

El microcontrolador ESP32-S3 es adecuado para aplicaciones embebidas de adquisición de datos debido a su capacidad de procesamiento, disponibilidad de interfaces UART, SPI, I2C y GPIO, y compatibilidad con entornos de desarrollo profesionales [1]. En este proyecto se utilizó como unidad central del sistema, coordinando la lectura del sensor RS485, la comunicación con el RTC, el almacenamiento en microSD, el manejo del módem DTU y el control del LED indicador.

El uso del framework ESP-IDF permite trabajar directamente con los periféricos del ESP32-S3 y organizar el programa mediante componentes, tareas y mecanismos de sincronización [2]. Además, PlatformIO facilita la compilación, carga, monitoreo serial y gestión de proyectos embebidos desde Visual Studio Code [3].

### 3.3. Sensores de nivel con comunicación RS485

Los sensores industriales con comunicación RS485 son utilizados cuando se requiere mayor robustez frente al ruido eléctrico y posibilidad de comunicación a mayor distancia que las interfaces digitales simples. En este proyecto se empleó un sensor de nivel con salida RS485, conectado al ESP32-S3 mediante una interfaz UART y control de dirección de transmisión y recepción [6].

La comunicación RS485 resulta conveniente para una estación de monitoreo, ya que el sensor puede estar separado físicamente de la electrónica principal y aun así mantener una comunicación estable.

### 3.4. Reloj de tiempo real DS3231M

Para que cada medición quede correctamente identificada, el sistema requiere una referencia confiable de fecha y hora. El DS3231M es un reloj de tiempo real de bajo costo y alta precisión con comunicación I2C [7]. En este proyecto, el RTC se utiliza para generar el timestamp asociado a cada medición de nivel.

El uso de un RTC evita depender únicamente del tiempo interno del microcontrolador, lo cual es importante en sistemas que deben registrar datos durante largos periodos o reiniciarse sin perder la referencia temporal.

### 3.5. Almacenamiento local mediante microSD

El almacenamiento local permite conservar los datos aun cuando exista una falla de comunicación. En este proyecto se utiliza una tarjeta microSD conectada mediante SPI, empleada para guardar el historial de mediciones en el archivo datalog.csv y los datos pendientes de envío en el archivo temp.csv. El conector microSD utilizado corresponde a un componente diseñado para este tipo de aplicaciones embebidas [8].

La estrategia de almacenamiento local es fundamental para mejorar la confiabilidad del sistema, ya que permite evitar la pérdida de datos ante interrupciones temporales de red o fallas del servidor.

### 3.6. Comunicación remota mediante módem DTU GPRS

Para la transmisión remota de datos se empleó un módem DTU GPRS con comunicación serial RS232/RS485 [5]. Este módulo permite enviar la trama generada por el ESP32-S3 hacia un servidor remoto. En este proyecto, la trama final utilizada fue:

d=timestamp,nivel

El uso del módem DTU permite separar la lógica de adquisición de datos de la conectividad celular, facilitando la transmisión hacia el servidor mediante una interfaz serial.

### 3.7. Sistema de alimentación mediante mini UPS

La alimentación del sistema se realiza mediante una mini UPS Marsriva, utilizada para entregar los niveles de tensión necesarios para los distintos módulos del proyecto [11]. La salida de 12 V se utiliza para alimentar el sensor de nivel y el módem DTU, mientras que la salida de 5 V alimenta el ESP32-S3. La regulación interna de la placa permite disponer de 3.3 V para los periféricos de baja potencia.

El uso de una UPS mejora la continuidad operativa del sistema ante interrupciones de energía, aspecto relevante para una estación de monitoreo remoto.

## 4. Descripción

El proyecto consiste en el desarrollo de una estación electrónica para adquisición y monitoreo de nivel de agua. La propuesta busca resolver la necesidad de contar con un sistema capaz de medir el nivel de agua de manera automática, almacenar los datos localmente y transmitirlos hacia un servidor remoto.

La motivación principal del proyecto surge de la importancia de monitorear niveles de agua en cauces urbanos, como arroyos o canales, donde el aumento rápido del nivel puede representar un riesgo de inundación. Contar con mediciones periódicas permite generar registros históricos, analizar el comportamiento del nivel y eventualmente alimentar sistemas de visualización, predicción o alerta. Este enfoque se relaciona con trabajos previos de análisis y predicción de nivel en el arroyo Mburicao [4].

El sistema desarrollado se enfoca en cuatro funciones principales:

Medir el nivel de agua mediante un sensor con comunicación RS485.

Registrar cada medición con fecha y hora mediante un RTC DS3231M.

Guardar los datos localmente en una tarjeta microSD.

Transmitir los datos hacia un servidor mediante un módem DTU GPRS.

Además, se implementó una lógica de respaldo para evitar la pérdida de datos cuando falla la comunicación con el servidor. Esta lógica se basa en el mecanismo Store and Forward, en el cual el dato se almacena temporalmente y luego se reenvía cuando la comunicación se restablece.

## 5. Objetivos

### 5.1. Objetivo general

Desarrollar un sistema de adquisición y monitoreo de nivel de agua basado en ESP32-S3, capaz de medir, almacenar y transmitir datos de nivel hacia un servidor remoto, incorporando respaldo local ante fallas de comunicación.

### 5.2. Objetivos específicos

1. Diseñar e implementar la integración electrónica de los módulos principales del sistema.
2. Realizar el montaje de los componentes electrónicos sobre la PCB diseñada.
3. Desarrollar el firmware modular del sistema utilizando PlatformIO y ESP-IDF.
4. Implementar la lectura del sensor de nivel mediante comunicación RS485.
5. Implementar la lectura de fecha y hora mediante el RTC DS3231M.

6. Registrar las mediciones en una tarjeta microSD en formato CSV.
7. Transmitir las mediciones hacia un servidor remoto mediante módem DTU GPRS.
8. Implementar un mecanismo Store and Forward para almacenar y reenviar datos pendientes.
9. Realizar pruebas aisladas de cada módulo del sistema.
10. Realizar pruebas integradas para validar el funcionamiento final del sistema.
11. Diseñar la estructura mecánica para el montaje y protección del sensor de nivel.
12. Diseñar la distribución interna de los componentes electrónicos dentro del gabinete IP65.
13. Definir los elementos de unión, fijación y soporte necesarios para la integración mecánica del sistema.
14. Elaborar los modelos CAD y dibujos técnicos acotados de las piezas mecánicas diseñadas.
15. Definir los materiales y métodos de fabricación requeridos para la construcción de las piezas mecánicas.

## 6. Esquema general del proyecto

El sistema está compuesto por una unidad central basada en ESP32-S3, encargada de coordinar la adquisición, procesamiento, almacenamiento y transmisión de los datos. La alimentación principal se realiza mediante una mini UPS, desde la cual se distribuyen los niveles de tensión necesarios para cada módulo [11].

### 6.1. Diagrama en bloques de interconexión

En la Figura 1 se presenta el diagrama en bloques de la arquitectura general del sistema. En este esquema se indican los módulos principales, los tipos de comunicación utilizados y los niveles de alimentación.


Figura 1: Diagrama en bloques de la arquitectura general del sistema.

### 6.2. Principio de medición del nivel

El sensor utilizado en el sistema no entrega directamente el nivel real del agua, sino la distancia entre el punto de instalación del sensor y la superficie reflectante del agua. Esta distancia medida se representa como d.

Para obtener el nivel real de agua, es necesario definir previamente una referencia fija H, correspondiente a la distancia total entre el sensor y el punto inferior de referencia, por ejemplo, el fondo del canal, tanque o estructura donde será instalado el sistema. A partir de esta referencia, el nivel real puede calcularse mediante la siguiente expresión:

N ivel real = H − d

Donde d representa la distancia medida por el sensor hasta la superficie del agua, y H representa la distancia total desde el sensor hasta el punto inferior de referencia.

Por lo tanto, el valor entregado por el sensor corresponde a una distancia relativa, mientras que el nivel real depende de la calibración o medición previa de la altura total H. Esta referencia puede variar según la geometría y las condiciones de instalación de cada estación, por lo que debe determinarse durante el montaje en campo.


Figura 2: Principio de medición del nivel de agua. El sensor mide la distancia d hasta la superficie reflectante, mientras que el nivel real se obtiene a partir de la referencia fija H.

### 6.3. Descripción de las partes

Cuadro 1: Descripción de los bloques principales del sistema.

Bloque | Descripción
Mini UPS | Fuente principal del sistema. Entrega 12 V para el sensor y el módem DTU, y 5 V para alimentar el ESP32-S3 [11].
ESP32-S3 | Microcontrolador principal. Ejecuta el firmware, coor-dina los periféricos y gestiona la lógica de adquisición, almacenamiento y transmisión [1].
Sensor de nivel RS485 | Sensor encargado de medir la distancia d entre el sensor y la superficie reflectante del agua. A partir de esta me-dición y de la referencia H, se obtiene el nivel real. Se comunica con el ESP32-S3 mediante UART con interfaz RS485 [6].
RTC DS3231M | Reloj de tiempo real utilizado para obtener fecha y hora confiables. Se comunica mediante I2C [7].
Tarjeta microSD | Medio de almacenamiento local. Se comunica mediante SPI y almacena los archivos datalog.csv y temp.csv [8].
Módem DTU GPRS | Módulo encargado de transmitir los datos hacia el ser-vidor remoto mediante red GPRS. La comunicación con el ESP32-S3 se realiza por RS485/UART [5].
Servidor remoto | Recibe y almacena los datos enviados por la estación. Permite verificar la recepción de las mediciones.

### 6.4. Comunicaciones y niveles de alimentación

Cuadro 2: Interfaces de comunicación y alimentación del sistema.

Módulo | Comunicación | Alimentación | Función
Sensor de nivel | RS485 / UART1 | 12 V | Medición de ni-vel
Módem DTU | RS485 / UART2 | 12 V | Envío de datos
RTC DS3231M | I2C | 3.3 V | Fecha y hora
microSD | SPI | 3.3 V | Almacenamiento
ESP32-S3 | GPIO, UART, I2C, SPI | 5 V / 3.3 V | Control central

### 6.5. Flujo conceptual del algoritmo final

El algoritmo final del sistema busca realizar la adquisición de datos de forma ordenada, procesar la información obtenida y ejecutar las acciones correspondientes, como almacenar los datos, transmitirlos al servidor o conservarlos temporalmente cuando existe una falla de comunicación.

El firmware fue organizado en tres partes principales: una secuencia inicial de arranque del sistema, un ciclo principal de medición y transmisión, y una tarea en segundo plano encargada del reenvío de datos pendientes mediante el mecanismo Store and Forward.

### 6.5.1. Descripción del flujo

A continuación, se presenta el diagrama de flujo que ilustra la secuencia inicial de ejecución del firmware en el ESP32-S3. En esta etapa se inicializan los componentes principales del sistema, se crea el mutex para controlar el acceso al módem DTU y se inicia la tarea en segundo plano para el manejo de datos pendientes.

INICIO ESP32; Inicializar componentes DS3231M SD Card Sensor RS485 DTU Modem LED Blink; Crear mutex del DTU; Crear task_pendientes en segundo plano; Entrar al loop principal de medición

Figura 3: Secuencia inicial de ejecución del firmware en el ESP32-S3.

Luego de la inicialización, el sistema entra al ciclo principal de medición. En este ciclo se lee la hora desde el RTC, se espera hasta el próximo intervalo de medición, se realiza la lectura del sensor de nivel mediante RS485, se genera el timestamp, se guarda el dato en la tarjeta SD y se intenta transmitir la medición al servidor mediante el módem DTU.

LOOP PRINCIPAL; Leer hora del RTC; ¿Es momento del próximo slot redondo?; Leer sensor RS485 de nivel hasta 3 intentos; ¿Lectura válida?; Blink LED GPIO21 si lectura fue válida; Generar timestamp timestamp RTC + 3 horas; Guardar SIEMPRE en SD; datalog.csv; Intentar enviar dato actual usando DTU con mutex; ¿Servidor respondió OK?; Guardar en temp.csv como pendiente; Esperar 1 s y volver al inicio del loop; Esperar segundos faltantes y volver al inicio del loop; nivel = -1.0; Ciclo terminado

Figura 4: Secuencia lógica del loop principal de medición, almacenamiento y envío de datos.

En caso de que el servidor no responda correctamente, el dato se conserva como pendiente en el archivo temp.csv. Para evitar que estos datos se pierdan, el firmware ejecuta una tarea en segundo plano encargada de revisar la existencia de pendientes, tomar el mutex del módem DTU, reenviar el dato y eliminarlo de temp.csv solamente si el servidor confirma la recepción mediante una respuesta OK.

TASK PENDIENTES BG; Leer hora actual del RTC; Calcular tiempo hasta próximo slot; ¿Hay margen? > 35 s; ¿Hay datos en temp.csv?; Leer primer pendiente FIFO de temp.csv; Tomar mutex DTU; ¿DTU libre?; Enviar pendiente; d=timestamp,nivel; ¿Servidor OK?; Eliminar primer registro de temp.csv; Esperar 5 s y repetir; Esperar 5 s y volver; Mantener pendiente; Mantener en; temp.csv

Figura 5: Flujo compacto de la tarea en segundo plano para el reenvío de datos pendientes.

### 6.6. Product Breakdown Structure

La estructura de desglose del producto permite identificar los subsistemas principales que componen el proyecto.

Cuadro 3: Product Breakdown Structure del sistema.

Nivel principal | Componentes o entregables
Sistema de adquisi-ción y monitoreo de nivel | Prototipo completo de medición, almacenamiento y transmisión de nivel de agua.
Hardware electrónico | PCB, ESP32-S3, RTC DS3231M, microSD, conectores, LED indicador, interfaz RS485.
Sensado | Sensor de nivel RS485, cableado y alimentación de 12 V.
Comunicación remota | Módem DTU GPRS, configuración mediante comandos AT, transmisión hacia servidor.
Almacenamiento | Archivo datalog.csv para historial y temp.csv para datos pendientes.
Firmware | Programa principal, módulo RTC, módulo SD, módulo sensor RS485, módulo DTU y módulo LED.
Alimentación | Mini UPS, salida de 12 V, salida de 5 V y regulación a 3.3 V en la placa.
Integración mecánica | Envolvente o estructura de protección, soportes inter-nos, fijaciones, accesos de cableado, montaje del sensor y documentación CAD/técnica.
Documentación y evi-dencias | Informe técnico, repositorio GitHub, capturas, videos y logs de pruebas.

## 7. Diseños

### 7.1. Diseño electrónico

El diseño electrónico del sistema fue dividido en subsistemas funcionales con el objetivo de facilitar el desarrollo, la verificación y la integración de la PCB final. Cada subsistema cumple una función específica dentro de la estación de adquisición y monitoreo de nivel, permitiendo organizar de manera clara la alimentación, el procesamiento, la medición de tiempo, el almacenamiento local y las comunicaciones.

Los principales subsistemas implementados en la PCB son: alimentación, ESP32-S3, RTC DS3231M, tarjeta microSD, conector USB-C y transceptores TTL-RS485. A continuación, se describe brevemente la función de cada uno de ellos.

### 7.1.1. Subsistema de alimentación

El subsistema de alimentación se encarga de distribuir los niveles de tensión requeridos por los distintos módulos del sistema. La placa recibe alimentación de entrada y utiliza regulación interna para obtener 3.3 V, tensión necesaria para el ESP32-S3, el RTC DS3231M, la tarjeta microSD y otros periféricos de baja potencia. Además, se consideran líneas de alimentación de 5 V y 12 V para los módulos externos según sus requerimientos eléctricos.

Figura 6: Esquema electrónico del subsistema de alimentación.

### 7.1.2. Subsistema ESP32-S3

El ESP32-S3 constituye la unidad principal de control del sistema. Este subsistema incluye las conexiones necesarias para el funcionamiento del microcontrolador, sus pines de comunicación, señales de programación, botones de arranque y reinicio, y las conexiones hacia los demás módulos de la placa. Desde este bloque se coordinan la lectura del sensor, el acceso a la microSD, la lectura del RTC, el control del LED indicador y el envío de datos mediante el módem DTU.


Figura 7: Esquema electrónico del subsistema ESP32-S3.

### 7.1.3. Subsistema RTC DS3231M

El subsistema RTC DS3231M permite disponer de una referencia de fecha y hora para cada medición realizada por la estación. Este módulo se comunica con el ESP32-S3 mediante el bus I2C, utilizando las líneas SDA y SCL. La información obtenida desde el RTC se emplea para generar el timestamp asociado a cada registro de nivel.


Figura 8: Esquema electrónico del subsistema RTC DS3231M.

### 7.1.4. Subsistema microSD

El subsistema microSD permite el almacenamiento local de las mediciones. La tarjeta se comunica con el ESP32-S3 mediante SPI y se utiliza para guardar el historial de datos en el archivo datalog.csv. Además, en caso de fallas de comunicación, los datos pendientes de envío se almacenan temporalmente en el archivo temp.csv, permitiendo implementar el mecanismo Store and Forward.


Figura 9: Esquema electrónico del subsistema microSD.

### 7.1.5. Subsistema USB-C

El conector USB-C permite alimentar y/o programar la placa durante las etapas de desarrollo y prueba. Este subsistema facilita la conexión del ESP32-S3 con la computadora para la carga del firmware, monitoreo serial y depuración del sistema desde el entorno PlatformIO.


Figura 10: Esquema electrónico del subsistema USB-C.

### 7.1.6. Subsistema transceptor TTL-RS485

El subsistema TTL-RS485 permite adaptar las señales UART del ESP32-S3 al estándar RS485. En la placa se implementan transceptores para la comunicación con el sensor de nivel y con el módem DTU. Esta interfaz permite una comunicación más robusta y adecuada para módulos externos, especialmente cuando se requiere mayor inmunidad al ruido y conexión mediante bornes.


Figura 11: Esquema electrónico del subsistema transceptor TTL-RS485.

### 7.2. Implementación de la PCB

En la Tabla 4 se resume la función principal de cada subsistema electrónico implementado en la PCB.

Cuadro 4: Resumen de subsistemas electrónicos implementados en la PCB.

Subsistema | Función principal
Alimentación | Regula y distribuye los niveles de tensión necesarios para el funcionamiento de la placa y módulos exter-nos.
ESP32-S3 | Controla el sistema, ejecuta el firmware y coordina las comunicaciones con sensores, memoria, RTC y mó-dem.
RTC DS3231M | Proporciona fecha y hora para generar el timestamp de cada medición.
microSD | Permite el almacenamiento local de mediciones y da-tos pendientes de envío.
USB-C | Permite alimentación, programación y monitoreo se-rial durante el desarrollo y pruebas.
TTL-RS485 | Adapta las señales UART del ESP32-S3 al estándar RS485 para comunicarse con el sensor de nivel y el módem DTU.

### 7.2.1. Placa electrónica

La placa electrónica fue diseñada para integrar los módulos principales del sistema en una única PCB, reduciendo el cableado externo y ordenando las conexiones entre el ESP32-S3, el sensor de nivel RS485, el módem DTU, el RTC DS3231M, la tarjeta microSD, los indicadores LED y el sistema de alimentación.

Durante el desarrollo del proyecto se realizó una modificación importante en el diseño de la PCB. En la etapa inicial, correspondiente al primer parcial, la placa fue planteada con una estructura de cuatro capas. Sin embargo, luego de revisar los requerimientos reales del sistema, la complejidad de fabricación y la necesidad de facilitar el montaje, se decidió rediseñar la placa utilizando una estructura de dos capas.

Este cambio permitió simplificar el proceso de fabricación, reducir costos, facilitar la inspección visual de las pistas y mantener una distribución adecuada de los componentes principales. El diseño final conserva la funcionalidad requerida para el sistema, integrando las interfaces de comunicación, alimentación, almacenamiento y control en una PCB más simple y adecuada para el prototipo desarrollado.

En la Figura 12 se muestra la comparación entre el diseño inicial de cuatro capas y el diseño final de dos capas. Esta comparación permite observar la evolución del ruteo y la reorganización de los componentes principales del sistema.


(a) Diseño inicial de PCB en 4 capas. | (b) Diseño final de PCB en 2 capas.

Figura 12: Comparación entre el diseño inicial de cuatro capas y el diseño final de dos capas de la PCB.

Además del diseño 2D, se generaron vistas tridimensionales de la placa para verificar la disposición física de los componentes, conectores y módulos antes del montaje. Estas vistas permitieron comprobar la ubicación del ESP32-S3, el portapila del RTC, los conectores de alimentación, los bornes RS485, la tarjeta microSD y el conector USB-C.

En la Figura 13 se presenta la comparación entre la vista 3D frontal del diseño inicial y la vista 3D frontal del diseño final. Esta vista permite evaluar la distribución de los componentes en la cara superior de la placa.


(a) Vista 3D frontal del diseño inicial. | (b) Vista 3D frontal del diseño final.

Figura 13: Comparación de la vista 3D frontal entre el diseño inicial y el diseño final de la PCB.

En la Figura 14 se presenta la comparación entre la vista 3D posterior del diseño inicial y la vista 3D posterior del diseño final. Esta comparación permite verificar la distribución de la cara inferior de la placa y analizar posibles interferencias mecánicas o problemas de montaje.


(a) Vista 3D posterior del diseño inicial. | (b) Vista 3D posterior del diseño final.

Figura 14: Comparación de la vista 3D posterior entre el diseño inicial y el diseño final de la PCB.

Finalmente, el diseño final de dos capas fue el utilizado para la fabricación y montaje del prototipo. Esta versión permitió integrar correctamente los módulos necesarios del sistema


y facilitó las pruebas eléctricas, la inspección de soldaduras y la validación funcional de la placa.

### 7.2.2. Montaje de PCB

El montaje de los componentes se realizó mediante aplicación de pasta de soldar, colocación de componentes y soldadura por reflow. Luego del proceso se realizó inspección visual y corrección manual de puentes de soldadura en los casos necesarios.

Figura 15: PCB montada luego del proceso de soldadura e inspección.

Figura 16: PCB montada y partes principales.

### 7.2.3. Mapeo de pines

Cuadro 5: Asignación de pines utilizados en el sistema.

Módulo | Señal | GPIO ESP32-S3 | Función
Sensor RS485 | TX / DI | GPIO1 | Envío de comando Modbus hacia el sensor.
Sensor RS485 | RX / RO | GPIO2 | Recepción de respuesta del sensor.
Sensor RS485 | DE/RE | GPIO4 | Control de dirección del bus RS485.
Módem DTU | TX / DI | GPIO5 | Envío de trama hacia el mó-dem.
Módem DTU | RX / RO | GPIO6 | Recepción de respuesta del módem o servidor.
Módem DTU | DE/RE / RTS | GPIO7 | Control de dirección RS485 del módem.
RTC DS3231M | SDA | GPIO8 | Línea de datos I2C.
RTC DS3231M | SCL | GPIO9 | Línea de reloj I2C.
RTC DS3231M | SQW/INT | GPIO16 | Señal reservada para inte-rrupción o pulso del RTC.
microSD | CS | GPIO10 | Selección de tarjeta SD.
microSD | MOSI | GPIO11 | Datos desde ESP32 hacia mi-croSD.
microSD | CLK | GPIO12 | Reloj SPI.
microSD | MISO | GPIO13 | Datos desde microSD hacia ESP32.
microSD | DET | GPIO15 | Detección de presencia de tarjeta.
LED indicador | LED Blink | GPIO21 | Indicador visual de lectura válida.

### 7.2.4. Sistema de control

El proyecto no implementa un sistema de control automático en lazo cerrado, ya que no actúa sobre una variable física para modificar el nivel de agua. El sistema desarrollado corresponde principalmente a un sistema de adquisición, almacenamiento y transmisión de datos. Sin embargo, sí se implementa una lógica de control de flujo del programa, temporización de mediciones, validación de datos, reintentos de lectura y manejo de fallas de comunicación. Para evitar conflictos en el uso del módem DTU, se utilizó un mutex dentro del firmware desarrollado con ESP-IDF [2].

### 7.3. Diseño mecánico

En esta sección se documentará el desarrollo mecánico del prototipo: boceto general, piezas, uniones, articulaciones si corresponden, accionamientos si corresponden, rodamientos si corresponden, elementos de fijación y la documentación técnica individual de las piezas. En esta primera entrega todavía no se dispone del diseño mecánico definitivo, por lo que se dejan definidos los apartados y espacios que deberán completarse posteriormente.

### 7.3.1. Requerimientos mecánicos y criterios de diseño

El diseño mecánico debe proteger los componentes electrónicos y permitir un montaje y mantenimiento sencillo de la estación.

Material principal de la estructura: acero.

Método de fabricación: corte, plegado y perforado de chapa.

Fijación: tornillería para elementos desmontables y soldadura en uniones estructurales permanentes.

Protección ambiental: gabinete IP65.

Mantenimiento: acceso mediante tapa desmontable a la electrónica, alimentación y conexiones.

Soporte del sensor: estructura rígida que mantenga su posición y orientación durante la medición.

### 7.3.2. Boceto y arquitectura mecánica general


Figura 17: Modelo diseñado en solidwork del sensor con sus soportes.

### 7.3.3. Distribución interna de componentes

Figura 18: Vista CAD de la distribución interna de los componentes.

### 7.3.4. Piezas y elementos mecánicos

En este apartado se describirá cada pieza independiente del conjunto mecánico. La tabla podrá completarse cuando el diseño CAD quede definido.

Cuadro 6: Elementos mecánicos considerados en el prototipo.

N.º | Elemento | Función | Tipo / material
1 | Gabinete de componen-tes electrónicos | Proteger y alojar la PCB, módem, sistema de alimen-tación y conexiones. | Gabinete comercial IP65
2 | Soporte del sensor | Mantener el sensor fijo y orientado hacia la superficie de medición. | Acero, diseño pro-pio
3 | Placa inferior del so-porte | Permitir el montaje y expo-sición de la zona activa del sensor. | Acero, diseño pro-pio
4 | Brazo estructural | Posicionar el sensor a la dis-tancia requerida respecto al punto de fijación. | Acero
5 | Sensor de nivel | Realizar la medición de ni-vel. Se integra al soporte conservando su protección original. | Componente co-mercial
6 | Elementos de fijación | Unión desmontable de las distintas piezas y compo-nentes. | Tornillos, tuercas y elementos auxilia-res

### 7.3.5. Uniones y fijaciones

El soporte del sensor está constituido por piezas metálicas unidas mediante tornillería, permitiendo el desmontaje de las tapas y el acceso al sensor para tareas de instalación o mantenimiento.

El sensor se fija en la parte inferior del soporte, manteniendo libre su zona de medición. La unión definitiva entre el soporte y el brazo estructural se definirá durante la etapa de fabricación.


Figura 19: Detalle de las uniones y fijaciones del soporte del sensor.


Figura 20: Detalle de las uniones y fijaciones de la caja.

### 7.3.6. Accesos, cableado y mantenimiento

El gabinete IP65 dispone de una tapa desmontable que permite acceder a los componentes internos para tareas de conexión y mantenimiento. En su interior se alojan la placa electrónica, el módem GPRS y el sistema de alimentación.

El cableado se distribuye principalmente por el perímetro del gabinete, manteniendo despejada la zona central y facilitando el acceso a los componentes. Las conexiones hacia el exterior, correspondientes a la alimentación y al sensor, deberán realizarse mediante entradas selladas para conservar el grado de protección IP65 del gabinete.


Figura 21: Distribución interna de componentes y recorrido del cableado dentro del gabinete.

### 7.3.7. Renderizado del conjunto

Para la evaluación del diseño mecánico se incorporarán vistas renderizadas que permitan apreciar la forma final del prototipo y la disposición general del conjunto.


Figura 22: Vista frontal del subconjunto mecánico del sensor y su unión con el brazo estructural

Figura 23: Vista inferior del sensor.

7.3.8. Vistas 2D acotadas; R VERDADERO4,50; ACABADO:; REBARBAR Y; ROMPER ARISTAS VIVAS; NO CAMBIE LA ESCALA; REVISIÓN; ESCALA:1:2; HOJA 1 DE 1; PESO:

SI NO SE INDICA LO CONTRARIO:
LAS COTAS SE EXPRESAN EN MM
ACABADO SUPERFICIAL:
TOLERANCIAS:
LINEAL:
ANGULAR:

DIBUJ.
VERIF.
APROB.
FABR.
CALID. | | | | MATERIAL: | N.º DE DIBUJO Sensor | A3

NOMBRE | FIRMA | FECHA | | | | TÍTULO:

Figura 24: Dibujo técnico del soporte del sensor.

ACABADO:; REBARBAR Y; ROMPER ARISTAS VIVAS; NO CAMBIE LA ESCALA; REVISIÓN; ESCALA:1:2; HOJA 1 DE 1; PESO:; ESCALA:1:5

SI NO SE INDICA LO CONTRARIO:
LAS COTAS SE EXPRESAN EN MM
ACABADO SUPERFICIAL:
TOLERANCIAS:
LINEAL:
ANGULAR:

DIBUJ.
VERIF.
APROB.
FABR.
CALID. | | | | MATERIAL: | N.º DE DIBUJO Soporte | A3

NOMBRE | FIRMA | FECHA | | | | TÍTULO:

Figura 25: Dibujo técnico del soporte del sensor.

CALID. | | | | MATERIAL: | N.º DE DIBUJO Caja | A3

Figura 26: Vistas 2D acotadas del gabinete.

## 8. Interfaz de visualización

Para facilitar la consulta de la información generada por el sistema de monitoreo, se implementaron distintas alternativas de visualización. En una primera etapa se utilizó Grafana como herramienta para la supervisión de las variables adquiridas por las estaciones. Ahora, se está desarrollando una interfaz web, publicada mediante GitHub Pages en conjunto con el equipo de trabajo, con el objetivo de disponer de una plataforma más orientada al acceso público y a la presentación general del proyecto.

### 8.1. Interfaz inicial mediante Grafana

Durante las primeras etapas de implementación se utilizó Grafana para construir un panel de monitoreo de los datos provenientes de la estación instalada en la cuenca del arroyo Mburicaó. Esta alternativa permitió disponer rápidamente de una interfaz funcional para verificar la recepción, almacenamiento y representación de las mediciones.

La interfaz desarrollada incluye la visualización conjunta del nivel del cauce y la precipitación registrada, permitiendo analizar temporalmente la relación entre ambas variables. Para el nivel se incorporaron además zonas y límites visuales que facilitan la identificación de incrementos importantes en la altura del agua.

Asimismo, el panel presenta un indicador del estado de actualización de los datos y un mapa con la ubicación de la estación de monitoreo. De esta manera, Grafana permitió integrar en un mismo entorno la información temporal y geográfica asociada al sistema.

La Figura 27 muestra el panel implementado.


Figura 27: Interfaz inicial de monitoreo implementada mediante Grafana.

El empleo de Grafana resultó especialmente útil durante el desarrollo y las pruebas del sistema, debido a que permitió comprobar de forma visual el comportamiento de las variables medidas sin necesidad de desarrollar inicialmente una aplicación gráfica específica.

### 8.2. Interfaz web mediante GitHub Pages

Como evolución de la interfaz inicial, se está desarrollando una página web para el proyecto de monitoreo del arroyo Mburicaó. La misma fue publicada mediante GitHub Pages, permitiendo disponer de una interfaz accesible directamente desde un navegador web y con un diseño orientado a usuarios externos al sistema. La plataforma puede consultarse mediante el siguiente enlace: MburicaoCastAI – Monitoreo en tiempo real. (https://mburicaocastai.github.io/v1/es/monitoreo-tiempo-real/)

A diferencia del panel técnico utilizado durante las pruebas, esta interfaz organiza la información del proyecto mediante distintas secciones de navegación, entre las que se encuentran el inicio, el monitoreo en tiempo real, la visualización de la cámara, la galería, las publicaciones y la información general del proyecto.

La página principal presenta además accesos directos a las principales funcionalidades del sistema, incluyendo el monitoreo en tiempo real, las predicciones mediante inteligencia artificial y las actividades relacionadas con ciencia ciudadana. También se incorporó información gráfica de la cuenca del arroyo y la visualización de imágenes provenientes de las cámaras instaladas en los puntos de monitoreo.

Actualmente, la plataforma ya incorpora un modelo preliminar de inteligencia artificial destinado a la predicción de posibles crecidas del cauce. Esta implementación constituye una primera integración de los modelos predictivos desarrollados en el proyecto dentro de una plataforma accesible al usuario, permitiendo visualizar de forma directa información relacionada con la evolución esperada del nivel del arroyo.

La Figura 28 presenta la página principal desarrollada.


Figura 28: Interfaz web del sistema de monitoreo publicada mediante GitHub Pages.

El desarrollo de esta segunda interfaz permitió separar la herramienta utilizada para la supervisión técnica de los datos de la plataforma destinada a la consulta y difusión de la información. De esta forma, mientras Grafana facilitó el desarrollo, las pruebas y el seguimiento de las variables adquiridas, la página web permitió presentar el sistema mediante una interfaz más sencilla, organizada y accesible para el usuario final.

## 9. Costos

### 9.1. Materiales y herramientas compradas o incrementales

Cuadro 7: Presupuesto de materiales, componentes electrónicos y herramientas.

Ítem | Cantidad | Costo unita-rio (usd) | Costo total (usd)
PCB fabricada | 1 | 27,6 | 27,6
Microcontrolador ESP32-S3-WROOM-1 | 1 | 6,71 | 6,71
Transceptor RS485 (SP3485EN) | 2 | 0,8 | 1,6
Sensor de nivel RS485 (Laboratorio) | 1 | 689.49 | 689.49
Módem DTU GPRS RS485 (Laboratorio) | 1 | 21 | 21
Módulo RTC DS3231M | 1 | 13,6 | 13,6
Conector microSD | 1 | 2,55 | 2,55
Mini UPS (Laboratorio) | 1 | 46,63 | 46,63
Portapila y batería CR2032 (SMTU2032) | 1 | 2,36 | 2,36
Pulsadores SMD (RST y BOOT - B3U-1000P) | 2 | 0,8 | 1,6
Capacitores SMD (0.1uF, 1uF, 10uF) | 11 | 0,34 | 3,81
Resistencias SMD varias | 16 | 0,98 | 15,68
Pasta de soldar (SN63/PB37 Tipo 4) | 1 | 12,27 | 12,27
Total comprado / incremental | 37 | 68,01 | 87,78
Total de materiales del laboratorio | 3 | 757,12 | 757,12
Total general estimado | 40 | 825,13 | 844,9

Nota: Los elementos marcados como laboratorio corresponden a materiales prestados o disponibles previamente, por lo que no forman parte del costo incremental asumido por el equipo, aunque sí se incluyen en el costo general estimado del sistema.

## 10. Bibliografía

## Referencias

[1] Espressif Systems, “ESP32-S3-WROOM-1 and ESP32-S3-WROOM-1U Datasheet,” versión 1.8. [En línea]. Disponible en: https://www.mouser.es/datasheet/3/1574/1/esp32-s3-wroom-1_wroom-1u_datasheet_en.pdf (https://www.mouser.es/datasheet/3/1574/1/esp32-s3-wroom-1_wroom-1u_datasheet_en.pdf)
[2] Espressif Systems, “ESP-IDF Programming Guide: Get Started,” Espressif Documentation. [En línea]. Disponible en: https://docs.espressif.com/projects/esp-idf/en/latest/ (https://docs.espressif.com/projects/esp-idf/en/latest/)
[3] PlatformIO, “PlatformIO IDE for Visual Studio Code,” PlatformIO Documentation. [En línea]. Disponible en: https://docs.platformio.org/en/latest/integration/ide/vscode.html (https://docs.platformio.org/en/latest/integration/ide/vscode.html)
[4] M. Aguilar et al., “Machine Learning Models for Water Level Prediction in Rapid Urban Streams: Case of Mburicao, Asunción, Paraguay,” IEEE Xplore, 2025. [En línea]. Disponible en: https://ieeexplore.ieee.org/document/11420547
[5] USR IOT, “GSM GPRS Modem, Serial RS232/RS485 to GSM DTU Modem.” [En línea]. Disponible en: https://en.usr.cn/GSM-Modem-Serial-RS232-RS485-GPRS. html (https://en.usr.cn/GSM-Modem-Serial-RS232-RS485-GPRS.html)
[6] AliExpress, “Sensor de nivel ultrasónico con comunicación RS485. Ficha comercial del producto.” [En línea]. Disponible en: https://es.aliexpress.com/item/1005008225897752.html (https://es.aliexpress.com/item/1005008225897752.html)
[7] Analog Devices, “DS3231M Low-Cost, Extremely Accurate, I2C Real-Time Clock Datasheet.” [En línea]. Disponible en: https://www.analog.com/media/en/technical-documentation/data-sheets/DS3231M.pdf (https://www.analog.com/media/en/technical-documentation/data-sheets/DS3231M.pdf)
[8] Molex, “MicroSD Memory Card Connector, Part Number 1040310811 Datasheet.” [En línea]. Disponible en: https://www.molex.com/en-us/products/part-detail/1040310811 (https://www.molex.com/en-us/products/part-detail/1040310811)
[9] GCT, “USB4930-00-A USB Type-C 2.0 Connector Datasheet.” [En línea]. Disponible en: https://www.mouser.sk/datasheet/3/1507/1/usb4930.pdf
[10] Shandong Puhui Electric Technology Co., Ltd., “INFRARED IC HEATER User Manual, Model T962/T962A/T962C.” [En línea]. Disponible en: https://en.tech168.cn/php/download-detail.php?id=5 (https://en.tech168.cn/php/download-detail.php?id=5)
[11] Marsriva, “Mini UPS Power Supply System.” [En línea]. Disponible en: https://www.marsriva.com/Products_item_2/157.html

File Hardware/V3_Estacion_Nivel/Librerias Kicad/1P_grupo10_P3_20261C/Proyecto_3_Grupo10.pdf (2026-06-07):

Universidad Nacional de Asuncion´

Facultad de Ingeniería

# Sistema de adquisición y monitoreo de nivel de agua

## Profesores: Prof. Ing. Federico Gaona (MSc.) Prof. Ing. Adolfo Monje

## Alumnos:

## Héctor Dejesús Velázquez Ojeda 5.011.166 Mathias Ramon Aguilar DelValle 4.970.804 Mauricio Ivan Tullo Estigarribia 3.782.101

2026

## Índice

1. Estado del arte | 3
2. Descripción | 3
3. Objetivos | 4
4. Esquema general del proyecto | 4
5. Diseños | 5
6. Lista de componentes | 6
7. Resultados parciales y finales | 7
8. Conclusiones y recomendaciones finales | 8
9. Bibliografía | 8
10.Anexos | 9

Resumen ejecutivo

Este informe detalla el diseño, implementación y evaluación de un sistema de telemetría para el monitoreo hidrológico en tiempo real del arroyo Mburicaó, ubicado en Asunción. El proyecto nace de la necesidad de registrar datos continuos sobre el nivel del cauce hídrico para nutrir modelos de predicción de crecidas rápidas en entornos urbanos. El núcleo del sistema está basado en un microcontrolador ESP32, encargado de adquirir datos a través de un sensor industrial de nivel con protocolo Modbus RS-485. La estación cuenta con un módulo RTC DS3231 para sincronización temporal, respaldo en memoria microSD y un módem GPRS para transmisión al servidor, permitiendo la visualización en la plataforma Grafana. La estación fue ensamblada en una caja hermética IP65 e instalada sobre un pilar de hormigón en la margen del arroyo (punto San Ignacio de Loyola). Los resultados muestran un sistema autónomo y robusto capaz de realizar mediciones cada cinco minutos, superando desafíos de interferencias, comunicación Modbus y conflictos de hardware. El desarrollo representa un aporte sustancial a las líneas de investigación en gestión del riesgo hídrico urbano de la Facultad de Ingeniería.

Abstract

This report details the design, implementation, and evaluation of a telemetry system for real-time hydrological monitoring of the Mburicaó stream, located in Asunción. The project arises from the need to record continuous data on the stream’s water level to feed prediction models for flash floods in urban environments. The core of the system is based on an ESP32 microcontroller, responsible for acquiring data through an industrial level sensor using the Modbus RS-485 protocol. The station features a DS3231 RTC module for time synchronization, microSD memory backup, and a GPRS modem for transmission to the server, allowing visualization on the Grafana platform. The station was assembled in an IP65 waterproof enclosure and installed on a concrete pillar on the bank of the stream (San Ignacio de Loyola point). The results show an autonomous and robust system capable of taking measurements every five minutes, overcoming challenges such as interference, Modbus communication issues, and hardware conflicts. The development represents a substantial contribution to the research lines in urban flood risk management at the Faculty of Engineering.

## 1. Estado del arte

El desarrollo de sistemas de monitoreo hidrológico basados en Internet de las Cosas (IoT) ha cobrado gran relevancia en los últimos años, especialmente para mitigar riesgos en zonas urbanas propensas a inundaciones. A continuación, se describen cuatro trabajos de investigación afines a este proyecto:
En primer lugar, la investigación de S. Rahman et al. [1] presenta un sistema de monitoreo del nivel de ríos basado en IoT utilizando microcontroladores de bajo costo. Al igual que el sistema del arroyo Mburicaó, este proyecto resalta la viabilidad económica y la eficiencia energética de plataformas como el ESP32 para adquirir datos remotos y transmitirlos a plataformas en la nube, demostrando alta fiabilidad en entornos hostiles.
Por otro lado, el trabajo de M. L. Chen y J. Wang [2] aborda el diseño de un sistema de adquisición de datos hidrológicos basado en el protocolo Modbus y redes de sensores inalámbricas. Este documento valida la elección de sensores industriales RS-485 para mediciones de nivel, destacando que el protocolo Modbus ofrece una inmunidad al ruido superior frente a interfaces analógicas tradicionales, un factor clave considerado en nuestra implementación.
Asimismo, A. Silva y C. Gómez [3] exponen un sistema de telemetría de bajo costo para alertas tempranas de inundaciones urbanas empleando transmisión GPRS. Los autores implementaron un mecanismo de retención de datos en caso de pérdida de conexión (similar a la estrategia Store & Forward aplicada en este proyecto), garantizando que no existan huecos en las bases de datos durante condiciones climáticas adversas, cuando las redes de telecomunicaciones suelen fallar. Finalmente, la investigación de J. Pérez et al. [4] detalla la construcción de una estación hidrometeorológica autónoma. El estudio enfatiza la importancia de la sincronización temporal precisa mediante módulos RTC (como el DS3231 utilizado en nuestro desarrollo) y rutinas de mantenimiento automático, tales como reinicios programados, para evitar el desbordamiento de memoria y asegurar la operatividad ininterrumpida de sistemas embebidos en el campo.

## 2. Descripción

La estación de monitoreo hidrológico instalada en el arroyo Mburicaó, específicamente en el San Ignacio de Loyola School, fue implementada con el objetivo de registrar el nivel del agua en tiempo real para el estudio y la predicción de crecidas rápidas en entornos urbanos. El sistema fue diseñado para operar de manera continua, autónoma y robusta, integrando tecnologías de sensado industrial y comunicación remota.
Este proyecto se desarrolló en el marco de las actividades del Laboratorio de Mecánica y Energía (LME) de la FIUNA, en el Departamento de Ciencias Computacionales e Ingeniería Aplicada. El foco del trabajo es resolver una problemática latente en la ciudad de Asunción: la falta de datos hidrológicos estructurados para el análisis de inundaciones urbanas repentinas.
El sistema combina conocimientos de electrónica, programación embebida y análisis de datos ambientales. Mediante la integración de herramientas de sensado industrial, comunicación por red celular y visualización en Grafana, se genera una base de datos continua que alimenta modelos predictivos de crecidas, fortaleciendo el análisis hidrológico y la toma de decisiones en el contexto urbano.

## 3. Objetivos

### 3.1. General

Diseñar e implementar un sistema de telemetría para el monitoreo en tiempo real del nivel del arroyo Mburicaó, integrando adquisición de datos, almacenamiento local, transmisión mediante red celular y visualización en una plataforma web, como aporte al proyecto de investigación sobre predicción del nivel del agua en corrientes urbanas rápidas.

### 3.2. Específicos

Diseñar el hardware del sistema de monitoreo basado en ESP32, sensor RS-485 y módulo GPRS.

Instalar y evaluar el desempeño del sistema en campo, verificando su funcionamiento continuo y la calidad de los datos enviados al servidor.

Estructurar y revisar los datos recolectados para asegurar su compatibilidad y utilidad en modelos de predicción.

## 4. Esquema general del proyecto

El sistema de adquisición y transmisión utiliza un microcontrolador ESP32 como unidad principal de procesamiento. A este microcontrolador se integran los siguientes módulos:

Sensor de nivel: Sensor industrial con comunicación bajo el protocolo Modbus RS-485.

Módulo de comunicación: Módem GPRS para el envío de datos periódicos al servidor web.

Módulo de tiempo: Reloj en tiempo real RTC DS3231 para el correcto sellado de tiempo de cada medición.

Almacenamiento: Tarjeta microSD como sistema de respaldo en caso de interrupción de red.

### 4.1. Flujo Operativo del Sistema

El ciclo de trabajo del sistema se rige por el siguiente diagrama de flujo secuencial:

1. Inicialización (Setup): Reset del ESP32 → Inicialización de periféricos (Serial Debug a 115200 bps, RTC DS3231, Módem y Sensor Modbus) → Montaje de la tarjeta SD y creación del log maestro.

2. Adquisición de Datos: Si transcurrieron 5 minutos → Leer sensor Modbus → Validar lectura (rango 0-10m y fecha) → Guardar en Log Maestro SD → Añadir al Buffer de envío.
3. Comunicación (Store & Forward): Cada 10 segundos → Verificar si hay datos en el Buffer → Transmitir por módem → Esperar confirmación del servidor. Si hay éxito, eliminar del buffer; si falla, mantener para reintento.
4. Mantenimiento: Si son las 02:02 AM → Guardar log de reinicio → Ejecutar reinicio seguro (ESP.restart).

## 5. Diseños

### 5.1. Electrónico

El diseño electrónico integró el microcontrolador ESP32 junto con múltiples buses de comunicación (UART para el GPRS, RS-485 para el sensor vía el transceptor SP3485EN, SPI para la microSD e I2C para el RTC).
Se realizaron las siguientes optimizaciones sobre el diseño original de la placa:

Se eliminó la resistencia R4 de la microSD y no se conectó resistencia en la línea de reloj (CLK).

Se consideraron picos de corriente del regulador AMS1117 de 3.3V.

Se contempló la posibilidad de eliminar el diodo D3.

Se agregó una resistencia pull-up de 10kΩ desde el pin IO0 del ESP hacia 3.3V.

Se cambió el valor de la resistencia R26 de 1kΩ a 330Ω para visualizar el LED D6.

### 5.2. Lógica de Software y Control (Firmware)

El firmware del ESP32 fue estructurado en fases críticas para garantizar autonomía y tolerancia a fallos:

Inicialización (Setup): Configura los pines para el sensor Modbus usando un pin de control SENSOR DE RE PIN para manejar el transceptor RS485. Verifica si la tarjeta SD está presente; si no lo está, activa automáticamente un Buffer en memoria RAM (usando std::vector), evitando la pérdida de datos por fallos de hardware.

Lógica de Adquisición: Se dispara cada 5 minutos (MINUTOS INTERVALO). El dato crudo se divide por 1000 para obtener el valor real en metros. Al timestamp del RTC se le suman 10,800 segundos (3 horas) para ajustar la zona horaria antes de enviar o guardar los datos.

Estrategia Store & Forward: Es el corazón del sistema. El dispositivo no intenta enviar el dato .en vivo”directamente, sino que lo apila en una cola (buffer.csv). Cada 10 segundos, intenta despachar la primera línea del buffer. Solo si el servidor responde afirmativamente (con la cadena ”NI-VEL REGISTRADO”), el dato se borra de la memoria. Si hay fallo de internet, los datos se acumulan cronológicamente para enviarse al recuperar la conexión.

Mantenimiento Automático: Se implementó un reinicio programado a las 2:02 AM. Esta es una excelente práctica en sistemas embebidos IoT, diseñada para liberar posibles fugas de memoria o bloqueos del stack de red/módem tras largas jornadas de operación continua.

## 6. Lista de componentes

### 6.1. Materiales y componentes electrónicos

A continuación, se detalla la lista de materiales empleados en el montaje de la placa electrónica.

Descripción / Tipo | Ref. | Cant. | Número de Parte (Mou-ser)
Batería / Portapila SMTU2032-LF | BT1 | 1 | 1060TR
Capacitor 0.1uF | C1,3,6-8,12-14 | 8 | GCM188R71C104KA37D
Capacitor 1uF | C11 | 1 | GRM188R61A105KA61D
Capacitor 10uF | C2, C4, C9 | 3 | GRM21BR61A106KE19
Capacitor 22uF | C5, C10 | 2 | GRM21BR60J226ME39
Diodo TVS SM712 | D1, D5 | 2 | SM712-02HTG
LED Verde | D2 | 1 | LTST-C190KGKT
Diodo 1N4148 | D3 | 1 | 1N4148W-7-F
LED Azul | D6 | 1 | LTST-C190TBKT
LED Rojo | D7 | 1 | LTST-C190KRKT
Diodo Schottky SS14 | D8 | 1 | SS14
Conector Micro SD | J1 | 1 | 503398-1892
Borneras Tornillo 2 pi-nes | J3, J4, J5 | 3 | 1751248
Conector Header 10 Pin | J6 | 1 | M20-9991045
Conector Header 2 Pin | J7 | 1 | M20-9990245
Conector Jack 12V | J8 | 1 | RASM722PTR13X
Receptáculo USB-C 16P | J9 | 1 | USB4085-GF-A
Resistor 4.7kΩ | R1,2,17-20,22-24 | 9 | RC0603FR-074K7L
Resistor 120Ω | R3, R25 | 2 | RC0603FR-07120RL
Resistor 10kΩ | R4-10, R12 | 8 | RC0603FR-0710KL
Resistor 1kΩ | R11, R26, R27 | 3 | RC0603FR-071KL
Resistor 5.1kΩ | R15, R16 | 2 | RC0603FR-075K1L
Resistor 330Ω | R26 (Mod) | 1 | RC0603FR-07330RL

Descripción / Tipo | Ref. | Cant. | Número de Parte (Mou-ser)
Pulsador RST / BOOT | SW1, SW2 | 2 | B3U-1000P
IC Transceptor RS485 | U1, U5 | 2 | SP3485EN-L/TR
Módulo ESP32 | U2 | 1 | ESP32-S3-WROOM-1-N16R8
Regulador 3.3V | U3 | 1 | LM1117MPX-3.3/NOPB
Módulo RTC | U4 | 1 | DS3231MZ+
Cuadro 1: Materiales y componentes electrónicos.

## 7. Resultados parciales y finales

La instalación en campo en el arroyo Mburicaó consistió en fijar la caja estanca en un pilar de hormigón y realizar el tendido de cables hacia el sensor RS-485 sumergido en un punto del cauce sin turbulencias.


Figura 1: Diagrama de conexion

Se realizaron pruebas funcionales que incluyeron:

Lectura directa del sensor Modbus, superando problemas de polaridad y respuestas incompletas.

Verificación del correcto sellado temporal y guardado en la memoria microSD.

Pruebas de envío GPRS tras ajustar velocidades del puerto serial y solucionar problemas con los comandos AT.

El sistema quedó programado para medir el nivel del agua cada cinco minutos de forma ininterrumpida. La revisión de los datos recolectados permitió observar el comportamiento del nivel del arroyo ante diferentes eventos de lluvia. Estos registros, al ser filtrados de inconsistencias y exportados en formato CSV, comprobaron que el sistema cumple cabalmente con los objetivos de adquisición de datos para el modelo del proyecto CLEI 2025.

## 8. Conclusiones y recomendaciones finales

### 8.1. Conclusiones

El desarrollo del proyecto fortaleció competencias clave en instrumentación, comunicación IoT, bases de datos y análisis hidrológico. Entre los desafíos principales superados, destaca la integración del hardware en el ESP32, donde la convivencia de buses requirió un mapeo exhaustivo de pines para evitar interferencias. La implementación de la lógica Store & Forward resolvió exitosamente las dificultades de transmisión de red, logrando un sistema tolerante a la variabilidad de la señal celular.

### 8.2. Recomendaciones y Mejoras Futuras

Manejo de la Memoria SD: El proceso actual de borrado y renombrado de archivos (temp.csv a buffer.csv) en cada envío exitoso puede generar desgaste en la SD a largo plazo. Si el volumen de datos aumenta en el futuro, se sugiere implementar lectura mediante punteros para optimizar los ciclos de escritura.

Tiempo de espera (Timeout): En la función enviarDatoAlServidor, se determinó que un timeout de 5 segundos es adecuado para la mayoría de los módems GSM/LTE, logrando un balance entre espera de respuesta y agilidad del sistema. Se recomienda mantener o ajustar este parámetro según las latencias de la red elegida.

Expansión y Comunicaciones: Migrar a tecnologías LTE 4G o NB-IoT para mayor velocidad, e incorporar paneles solares para independencia eléctrica.

## 9. Bibliografía

## Referencias

[1] S. Rahman, A. Karim y M. S. Hossain, “IoT-Based Real-Time River Water Level Monitoring System”, IEEE Access, vol. 8, pp. 12345-12355, 2020.
[2] M. L. Chen y J. Wang, “Design of a Hydrological Data Acquisition System Based on Modbus Protocol and Wireless Sensor Networks”, IEEE Sensors Journal, vol. 19, no. 12, pp. 4500-4508, 2019.
[3] A. Silva y C. Gómez, “Low-Cost Telemetry System for Urban Flood Early Warning using ESP32 and GPRS”, IEEE Internet of Things Journal, vol. 7, no. 5, pp. 3456-3465, 2021.
[4] J. Pérez, R. González y T. Lee, “Development of an Autonomous Hydrometeorological Station for Flash Flood Prediction”, IEEE Transactions on Instrumentation and Measurement, vol. 71, pp. 1-10, 2022.
[5] Laboratorio de Mecánica y Energía (LME). Facultad de Ingeniería, Universidad Nacional de Asunción.

[6] Proyecto de investigación sobre predicción de crecidas. Modelo Predictivo CLEI 2025.

## 10. Anexos

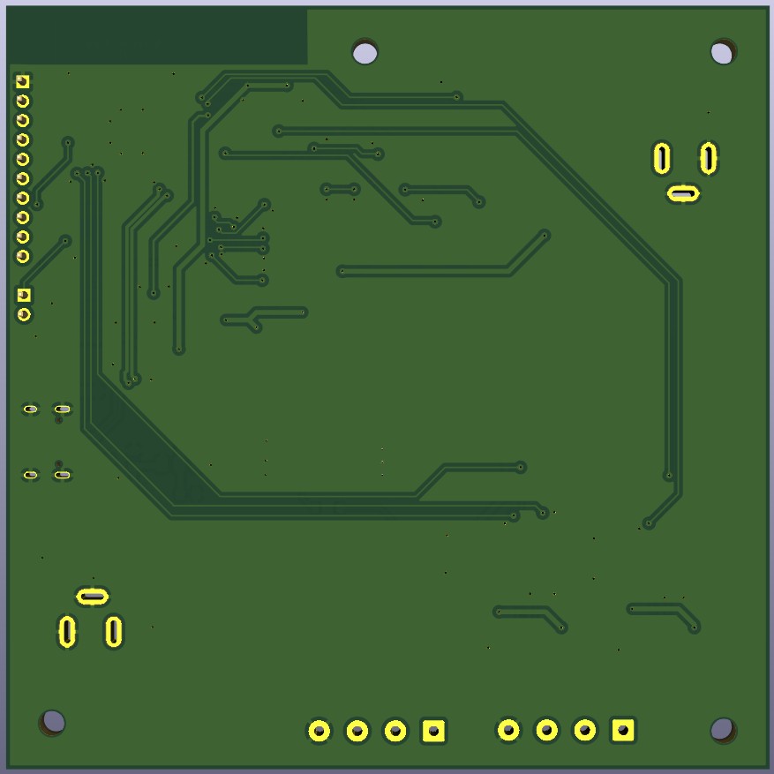
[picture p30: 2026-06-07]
Hardware/V3_Estacion_Nivel/imagenes/placa_posterior.jpg

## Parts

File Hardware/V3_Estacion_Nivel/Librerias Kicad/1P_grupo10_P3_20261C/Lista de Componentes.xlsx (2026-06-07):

Tipo de componente | Referencia | Cantidad | Valor | Mfr Part Number | Enlace(mouser)
Batería / Portapila | BT1 | 1 | SMTU2032-LF | 1060TR | https://www.mouser.com/ProductDetail/Keystone-Electronics/1060TR?qs=ygfPscbNso3AlRe4cBnpxg%3D%3D
Capacitor | C1,C8,C3,C6,C7,C12,C13,C14 | 8 | 0.1uF | GCM188R71C104KA37D | https://www.mouser.com/ProductDetail/Murata-Electronics/GCM188R71C104KA37D?qs=aEuGZpxfbxWKAxwYn%252BeTMg%3D%3D
 | C11 | 1 | 1uF | GRM188R61A105KA61D | https://www.mouser.com/ProductDetail/Murata-Electronics/GRM188R61A105KA61D?qs=LlFn95tWfDgsujID1PD8Jw%3D%3D
 | C2,C9 | 2 | 10uF | 81-GRT21BR61A106KE1L | https://www.mouser.com/ProductDetail/Murata-Electronics/GRT21BR61A106KE01L?qs=drgMNd%252BkGPO0b8cjxpkx5Q%3D%3D
 | C10 | 1 | 22uF | GRM21BR60J226ME39L | https://www.mouser.com/ProductDetail/Murata-Electronics/GRM21BR60J226ME39L?qs=DJY02EClX9n4vY1%2FNV53Qw%3D%3D
 | C4 | 1 | 10uf | 12063C106KAT2A | https://www.mouser.com/ProductDetail/KYOCERA-AVX/12063C106KAT2A?qs=lBCXFVCh2mU%2FEu8zFiPNsQ%3D%3D
 | C5 | 1 | 22uf | T495C226K025AHE300 | https://www.mouser.com/ProductDetail/KEMET/T495C226K025AHE300?qs=cV2l%2FExQ1wG335WlPl6I2g%3D%3D
Diodo TVS / Protección | D1,D5 | 2 | SM712_SOT23 | SM712-02HTG | https://www.mouser.com/ProductDetail/Littelfuse/SM712-02HTG?qs=aGgfWYEhH7lQgBVBPCUDkw%3D%3D
Diodo | D3 | 1 | 1N4148 | 1N4148W-7-F | https://www.mouser.com/ProductDetail/Diodes-Incorporated/1N4148W-7-F?qs=LHX0FizJzg7Ae9ZM8LTAWw%3D%3D
Diodo Schottky | D8 | 1 | SS14 | SS14 | https://www.mouser.com/ProductDetail/onsemi/SS14?qs=mVVXn4M53U%252BvrBaFv5vr4w%3D%3D
LED | D2 | 1 | GREEN | LTST-C190KGKT | https://www.mouser.com/ProductDetail/LITEON/LTST-C190KGKT?qs=205qCy6M2Q%252BAdcgwUZktqw%3D%3D
 | D6 | 1 | BLUE | LTST-C190TBKT | https://www.mouser.com/ProductDetail/LITEON/LTST-C190TBKT?qs=RX3h6vwoF9jNAGfkgrwfMA%3D%3D
 | D7 | 1 | RED | LTST-C190KRKT | https://www.mouser.com/ProductDetail/LITEON/LTST-C190KRKT?qs=kAD5fFa1n5VY3YYNWPC1Fg%3D%3D
Conector | J1 | 1 | Micro_SD_Card_Det1 | 503398-1892 | https://www.mouser.com/ProductDetail/Molex/503398-1892?qs=b0v8CoHHvSMxV%252BW12iKaSg%3D%3D
 | J2,J3,J4,J5 | 4 | Screw_Terminal_01x02 | 1751248 | https://www.mouser.com/ProductDetail/Phoenix-Contact/1751248?qs=bOnNDoERoR01kuhsqWf5xQ%3D%3D
 | J6 | 1 | Conn_01x10_Pin | M20-9991045 | https://www.mouser.com/ProductDetail/Harwin/M20-9991045?qs=%252Bk6%2F5FB6qrlmqe3AuAEP4g%3D%3D
 | J7 | 1 | Conn_01x02_Pin | M20-9990245 | https://www.mouser.com/ProductDetail/Harwin/M20-9990245?qs=Jph8NoUxIfUDXEB%252Bi9kJRA%3D%3D
 | J8 | 1 | Conn_Jack_12V | RASM722PTR13X | https://www.mouser.com/ProductDetail/Switchcraft/RASM722PTR13X?qs=NW1tGwZwExFzXYAsdXkb2Q%3D%3D
 | J9 | 1 | USB_C_Receptacle_USB2.0_16P | USB4085-GF-A | https://www.mouser.com/ProductDetail/GCT/USB4085-GF-A?qs=KUoIvG%2F9Ilba1bQOahfWjw%3D%3D | simbolo snapmagic
R | R1,R2,R17,R18,R19,R20,R22,R23,R24 | 9 | 4.7k | RC0603FR-074K7L | https://www.mouser.com/ProductDetail/YAGEO/RC0603FR-074K7L?qs=gt6vzsuosg37y0l7Vt36bQ%3D%3D
 | R3,R25 | 2 | 120 | RC0603FR-07120RL | https://www.mouser.com/ProductDetail/YAGEO/RC0603FR-07120RL?qs=uM1JSSdPjOCKJQFXEGGb5w%3D%3D
 | R4,R5,R6,R7,R8,R9,R10,R12 | 8 | 10k | RC0603FR-0710KL | https://www.mouser.com/ProductDetail/YAGEO/RC0603FR-0710KL?qs=grNVn54RoB%252B3GtjbJj3wJQ%3D%3D
 | R11,R26,R27 | 3 | 1k | RC0603FR-071KL | https://www.mouser.com/ProductDetail/YAGEO/RC0603FR-071KL?qs=VU8sRB4EgwApHsk4rF%2F3zg%3D%3D
 | R26 | 1 | 330 | RC0603FR-07330RL | https://www.mouser.com/ProductDetail/YAGEO/RC0603FR-07330RL?qs=diQw95jMAeN1335dAOzMfg%3D%3D
 | R15,R16 | 2 | 5.1k | RC0603FR-075K1L | https://www.mouser.com/ProductDetail/YAGEO/RC0603FR-075K1L?qs=gt6vzsuosg2jUUwxnI2PJQ%3D%3D
Pulsador / Switch | SW1 | 1 | RST | B3U-1000P | https://www.mouser.com/ProductDetail/Omron-Electronics/B3U-1000P?qs=AO7BQMcsEu4ip80xyf2FwA%3D%3D
 | SW2 | 1 | BOOT | B3U-1000P | https://www.mouser.com/ProductDetail/Omron-Electronics/B3U-1000P?qs=AO7BQMcsEu4ip80xyf2FwA%3D%3D
Circuito integrado | U1,U5 | 2 | SP3485EN | SP3485EN-L/TR | https://www.mouser.com/ProductDetail/MaxLinear/SP3485EN-L-TR?qs=3EMgrMjM0fbQ17liGrle%2Fg%3D%3D
Módulo / Microcontrolador | U2 | 1 | ESP32-S3-WROOM-1 | ESP32-S3-WROOM-1-N16R8 | https://www.mouser.com/ProductDetail/Espressif-Systems/ESP32-S3-WROOM-1-N16R8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
Regulador de voltaje | U3 | 1 | AMS1117-3.3 | LM1117MPX-3.3/NOPB | https://www.mouser.com/ProductDetail/Texas-Instruments/LM1117MPX-3.3-NOPB?qs=X1J7HmVL2ZHRbBIxXi4utg%3D%3D
RTC / Reloj en tiempo real | U4 | 1 | DS3231M | DS3231MZ+ | https://www.mouser.com/ProductDetail/Analog-Devices-Maxim-Integrated/DS3231MZ%2b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
OBSERVACIONES |  |  |  |  | PCB 4 capas
 | quitamos R4 de la sdcard |  | en la línea de clk no se conecta ninguna resistencia |  | capa 2 de GND
 | Regulador LM1117 Observación picos de corriente |  | se podria cambiar por un convertidor Buck |  | capa3 de 3v3
 | posibilidad de eliminar el diodo D3
 | Agrega una resistencia de 10k desde ESP_IO0 hacia 3V3.
 | Cambiar R26 de 1k a 330 ohms (para que se vea el LED D6).

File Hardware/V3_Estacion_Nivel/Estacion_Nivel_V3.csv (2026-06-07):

Id | Identificador | Huella | Cantidad | Identificación | Suministrador y ref
1 | R10,R9,R8,R7,R6,R5,R4,R12 | R_0805_2012Metric_Pad1.20x1.40mm_HandSolder | 8 | 10k
2 | R20,R19,R18,R24,R23,R22,R17,R2,R1 | R_0805_2012Metric_Pad1.20x1.40mm_HandSolder | 9 | 4.7k
3 | R25,R3 | R_0805_2012Metric_Pad1.20x1.40mm_HandSolder | 2 | 120
4 | R27,R26,R11 | R_0805_2012Metric_Pad1.20x1.40mm_HandSolder | 3 | 1k
5 | R16,R15 | R_0805_2012Metric_Pad1.20x1.40mm_HandSolder | 2 | 5.1k
6 | C7,C6,C3,C13,C12,C14 | C_0805_2012Metric_Pad1.18x1.45mm_HandSolder | 6 | 0.1uF
7 | C9,C2 | C_0805_2012Metric_Pad1.18x1.45mm_HandSolder | 2 | 10u
8 | C5,C10 | C_0805_2012Metric_Pad1.18x1.45mm_HandSolder | 2 | 22uF
9 | C4 | C_0805_2012Metric_Pad1.18x1.45mm_HandSolder | 1 | 10uF
10 | C11 | C_0805_2012Metric_Pad1.18x1.45mm_HandSolder | 1 | 1uF
11 | C1,C8 | C_0805_2012Metric_Pad1.18x1.45mm_HandSolder | 2 | 0.1u
12 | D7 | LED_0805_2012Metric_Pad1.15x1.40mm_HandSolder | 1 | RED
13 | D2 | LED_0805_2012Metric_Pad1.15x1.40mm_HandSolder | 1 | GREEN
14 | D6 | LED_0805_2012Metric_Pad1.15x1.40mm_HandSolder | 1 | BLUE
15 | J7 | PinHeader_1x02_P2.54mm_Vertical | 1 | Conn_01x02_Pin
16 | J6 | PinHeader_1x10_P2.54mm_Vertical | 1 | Conn_01x10_Pin
17 | U2 | ESP32-S3-WROOM-1 | 1 | ESP32-S3-WROOM-1
18 | J3,J4,J5 | TerminalBlock_MaiXu_MX126-5.0-02P_1x02_P5.00mm | 3 | Screw_Terminal_01x02
19 | U1,U5 | SOIC-8_3.9x4.9mm_P1.27mm | 2 | SP3485EN
20 | D1,D5 | SOT-23 | 2 | SM712_SOT23
21 | J8 | TerminalBlock_MaiXu_MX126-5.0-04P_1x04_P5.00mm | 1 | Screw_Terminal_01x04
22 | SW2 | SW_Push_1P1T_NO_CK_KMR2 | 1 | BOOT
23 | J9 | USB_C_Receptacle_Palconn_UTC16-G | 1 | USB_C_Receptacle_USB2.0_16P
24 | D8 | D_SMA | 1 | SS14
25 | J1 | microSD_HC_Molex_104031-0811 | 1 | Micro_SD_Card_Det1
26 | BT1 | BAT_SMTU2032-LF | 1 | SMTU2032-LF
27 | D3 | D_SOD-123 | 1 | 1N4148
28 | U4 | SOIC-16W_7.5x10.3mm_P1.27mm | 1 | DS3231M
29 | U3 | SOT-223-3_TabPin2 | 1 | AMS1117-3.3
30 | SW1 | SW_Push_1P1T_NO_CK_KMR2 | 1 | RST

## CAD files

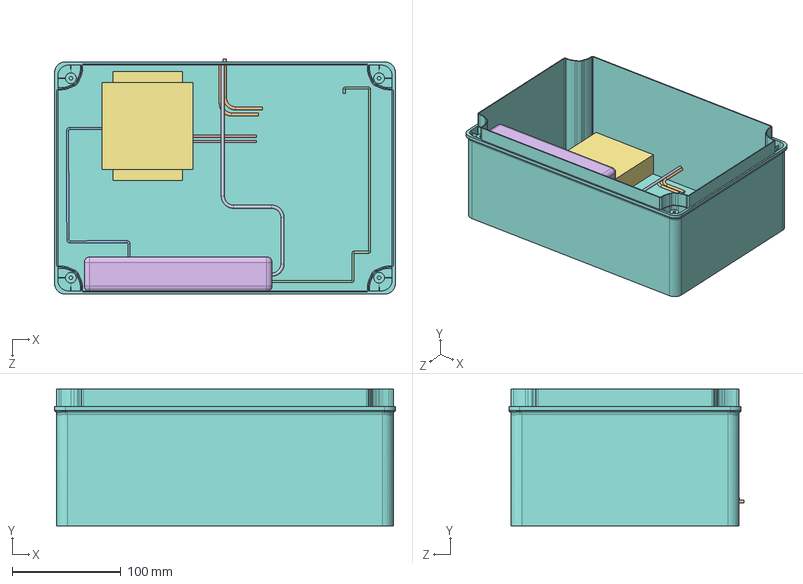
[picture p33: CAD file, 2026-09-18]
documentos/Diseño Mecánico/Caja/Ensamblaje.SLDASM
314.0 x 126.0 x 216.8 mm
Caja
moden
Ups
cable x 2
cable2
cable3
cable4 x 2
cable5

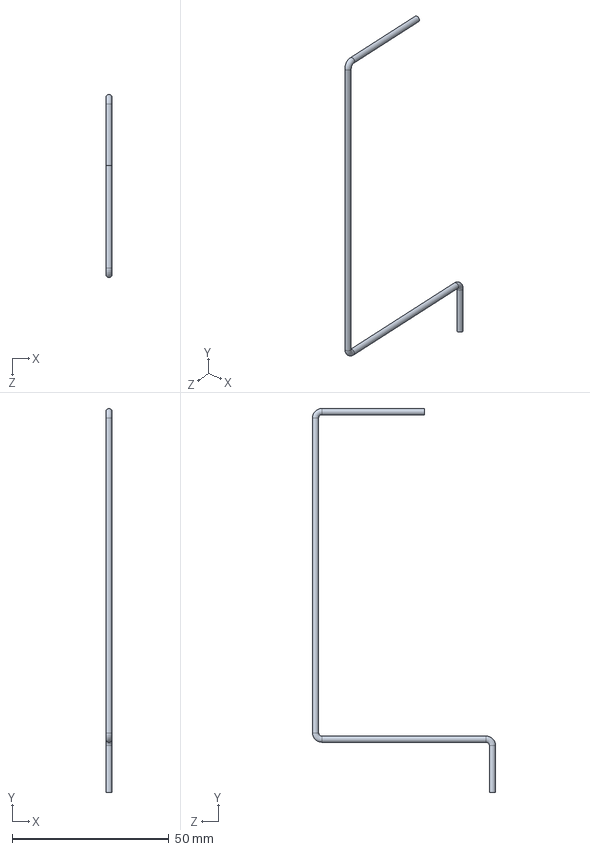
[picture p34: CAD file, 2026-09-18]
documentos/Diseño Mecánico/Caja/cable3.SLDPRT
2.00 x 122.4 x 58.3 mm

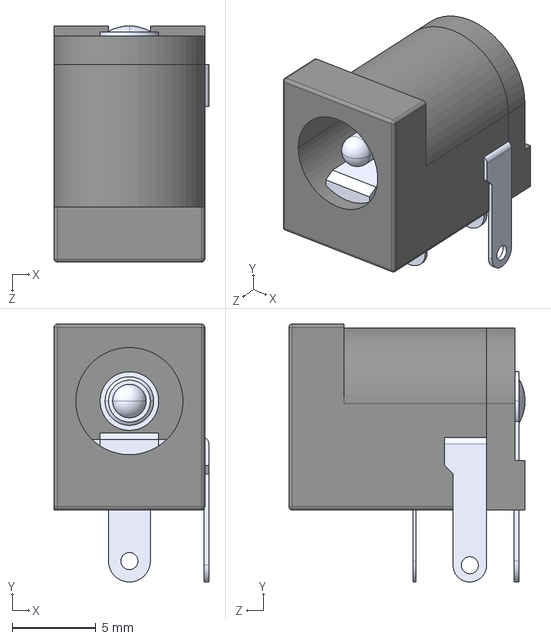
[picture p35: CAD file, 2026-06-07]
Hardware/V3_Estacion_Nivel/Librerias Kicad/CON-SOCJ-2155/CON-SOCJ-2155.step
9.25 x 15.4 x 14.1 mm

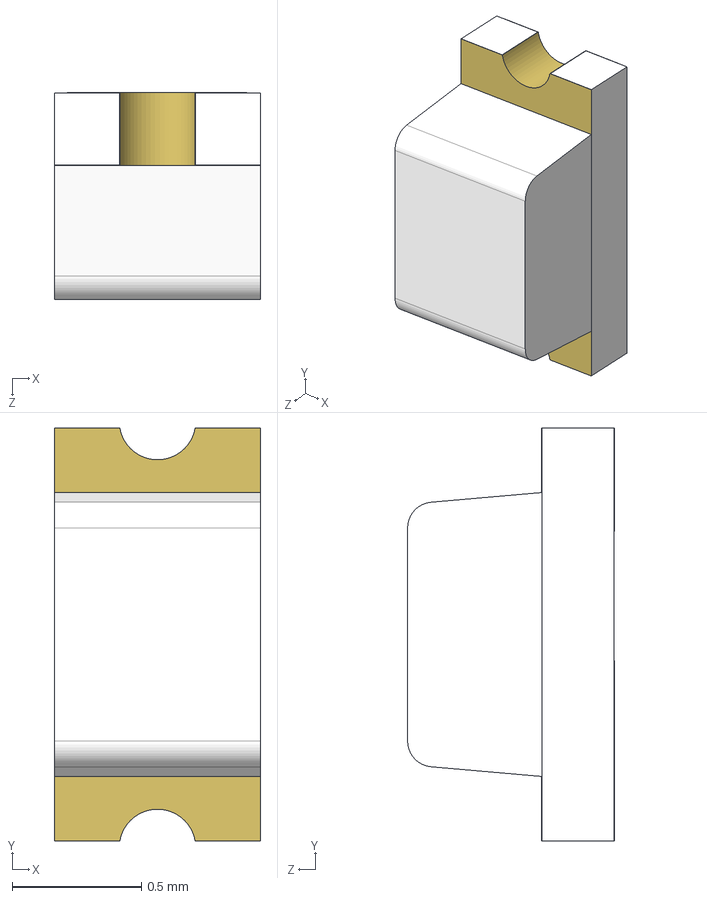
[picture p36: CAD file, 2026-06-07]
Hardware/V3_Estacion_Nivel/Librerias Kicad/green/LTST-C190KGKT/3D/LTST-C190KGKT.stp
0.8 x 1.60 x 0.801 mm

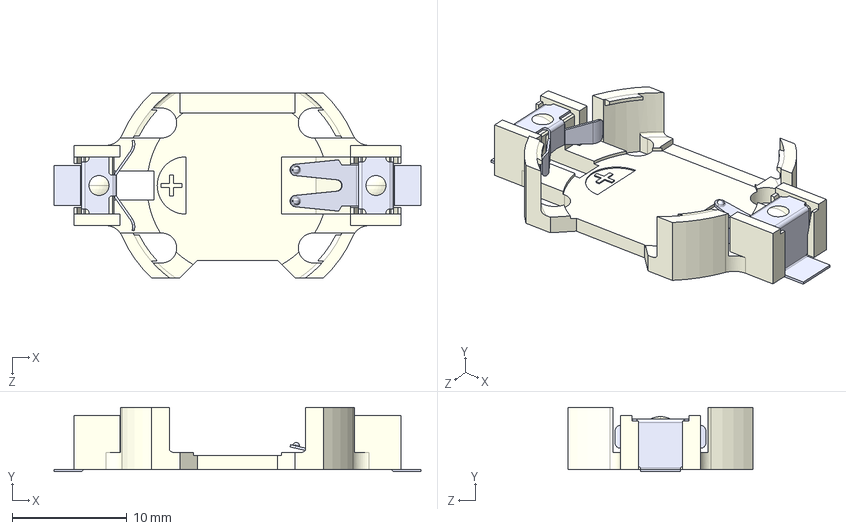
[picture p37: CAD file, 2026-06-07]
Hardware/V3_Estacion_Nivel/Librerias Kicad/SMTU2032-LF/SMTU2032-LF.step
32.0 x 5.60 x 16.1 mm

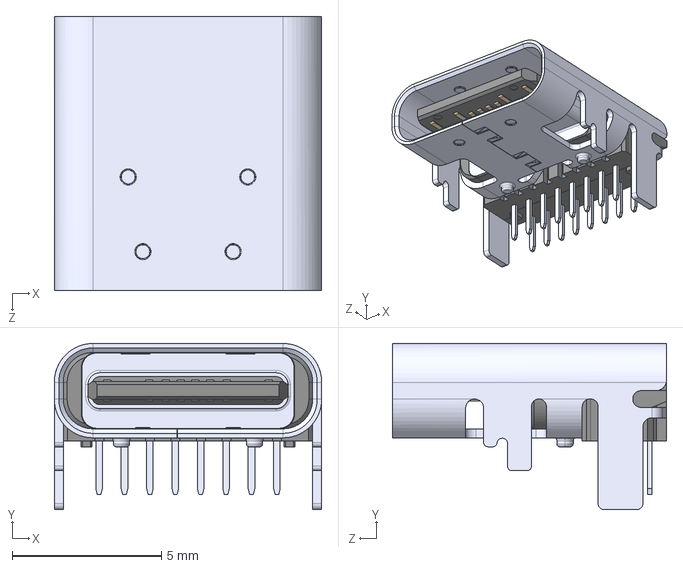
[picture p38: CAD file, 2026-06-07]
Hardware/V3_Estacion_Nivel/Librerias Kicad/USB4085-GF-A_REVA4/USB4085-GF-A_REVA4.step
8.95 x 5.56 x 9.17 mm

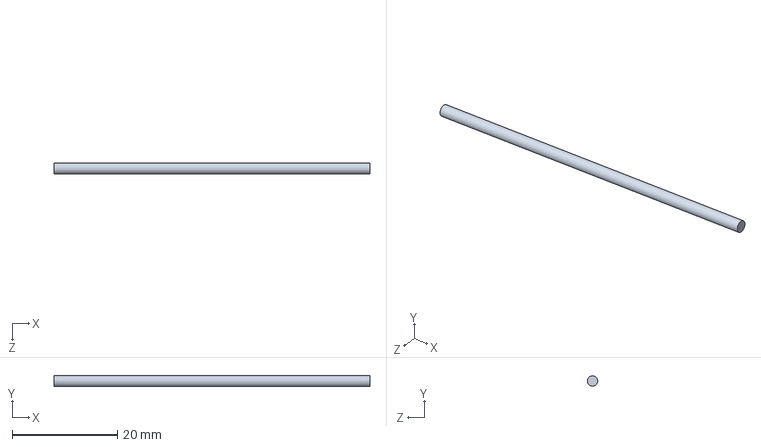
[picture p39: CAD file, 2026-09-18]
documentos/Diseño Mecánico/Caja/cable.SLDPRT
60.0 x 2.00 x 2.00 mm

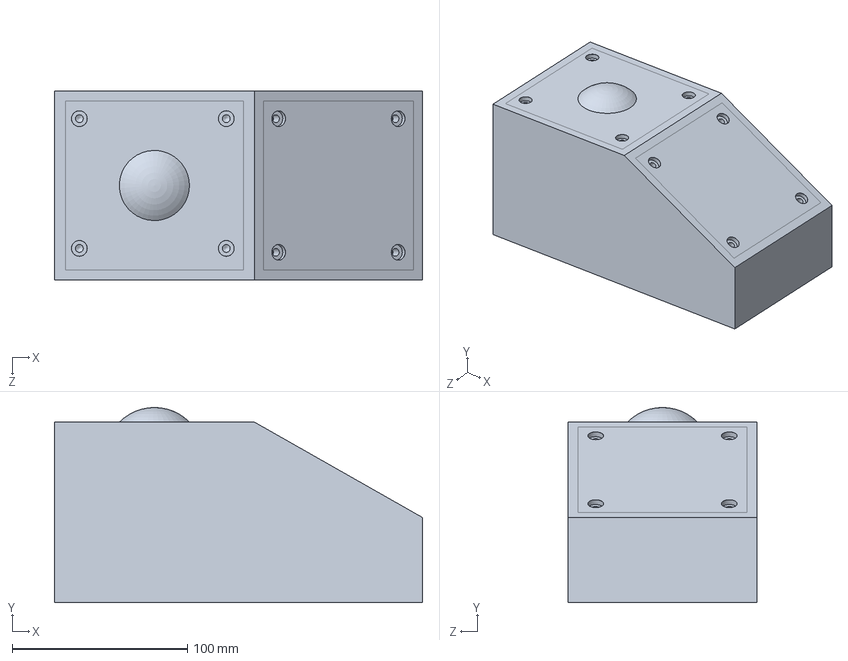
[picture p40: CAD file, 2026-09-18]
documentos/Diseño Mecánico/sensor/Sensor.SLDPRT
210.0 x 111.3 x 108.0 mm

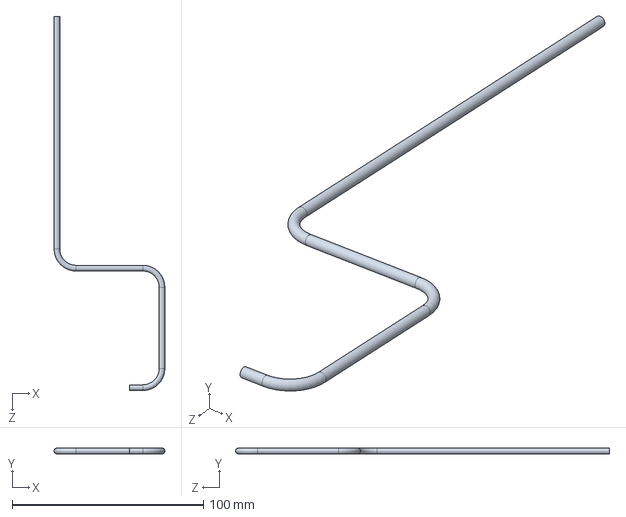
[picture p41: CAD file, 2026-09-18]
documentos/Diseño Mecánico/Caja/cable5.SLDPRT
58.0 x 3.00 x 195.8 mm

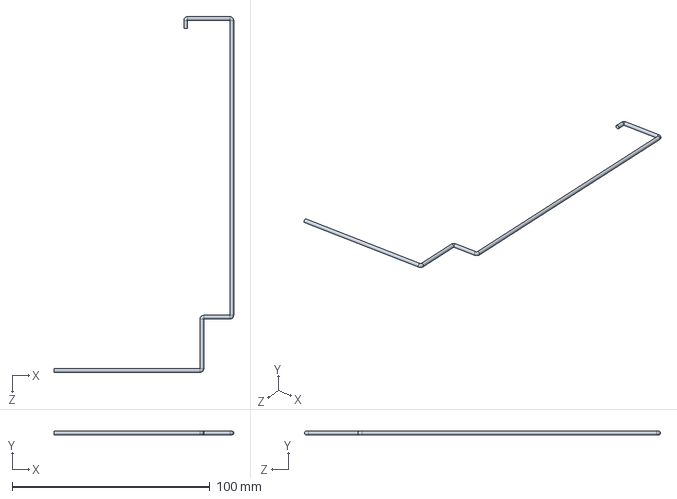
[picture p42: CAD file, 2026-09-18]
documentos/Diseño Mecánico/Caja/cable2.SLDPRT
90.9 x 2.00 x 180.2 mm

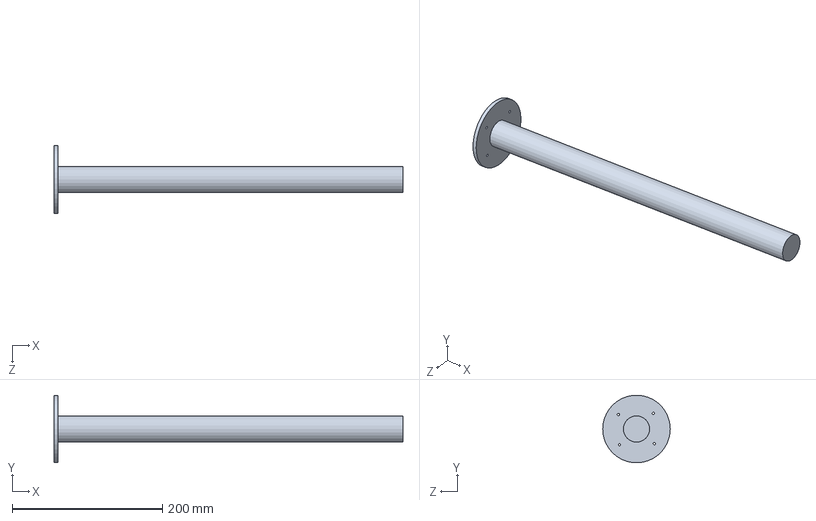
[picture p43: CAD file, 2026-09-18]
documentos/Diseño Mecánico/sensor/Soporte2.SLDPRT
465.0 x 89.9 x 90.0 mm

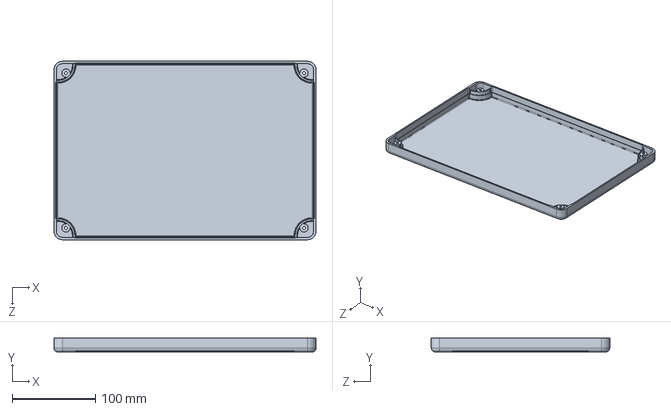
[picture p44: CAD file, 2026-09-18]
documentos/Diseño Mecánico/Caja/Tapa.SLDPRT
314.0 x 17.0 x 214.0 mm

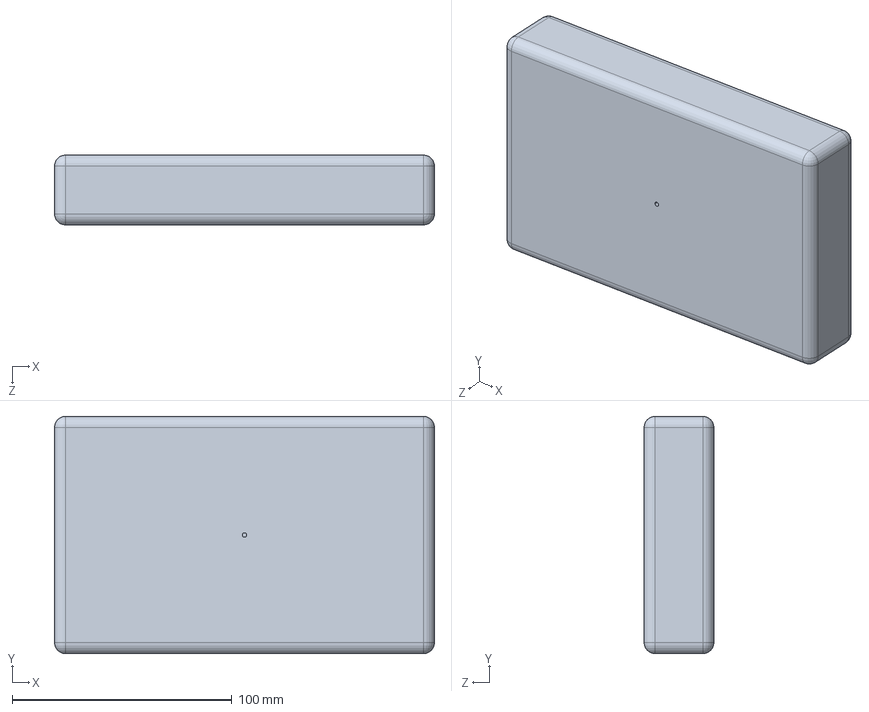
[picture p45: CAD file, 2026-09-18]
documentos/Diseño Mecánico/Caja/Ups.SLDPRT
173.0 x 108.0 x 31.8 mm

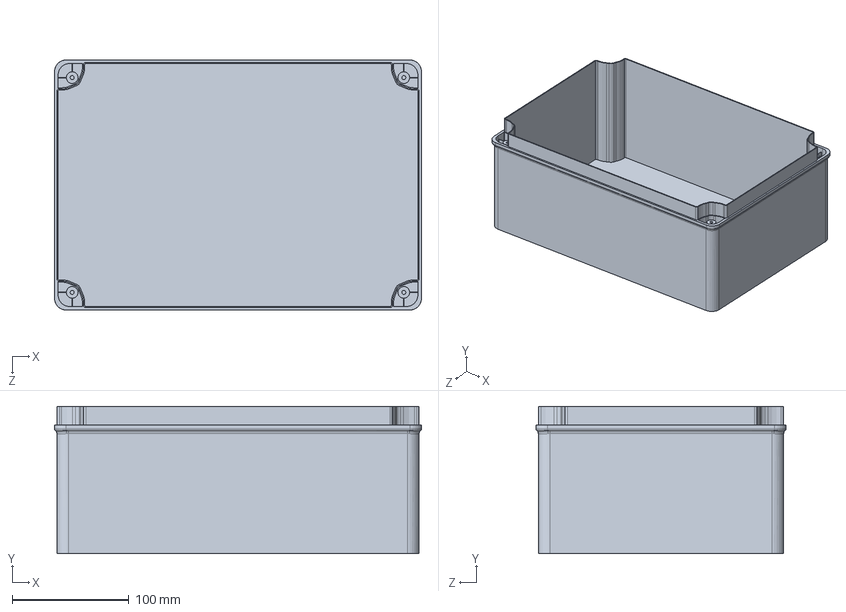
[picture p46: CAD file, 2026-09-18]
documentos/Diseño Mecánico/Caja/Caja.SLDPRT
314.0 x 126.0 x 214.0 mm

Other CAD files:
documentos/Diseño Mecánico/sensor/Ensamblaje_sensor.SLDASM
documentos/Diseño Mecánico/sensor/Soporte.SLDPRT
documentos/Diseño Mecánico/Caja/cable4.SLDPRT
documentos/Diseño Mecánico/Caja/moden.SLDPRT
Hardware/V3_Estacion_Nivel/Librerias Kicad/LIB_M20-9990245/M20-9990245/3D/M20-9990245.stp
Hardware/V3_Estacion_Nivel/Librerias Kicad/LIB_M20-9990245/M20-9990245/Allegro/hdrv2w64p0x254_1x2_508x254x864p.psm
Hardware/V3_Estacion_Nivel/Librerias Kicad/LIB_M20-9990245/M20-9990245/DEHDL/m20_9990245/chips/chips.prt
Hardware/V3_Estacion_Nivel/Librerias Kicad/green/LTST-C190KGKT/Allegro/ledc1608x80n.psm
Hardware/V3_Estacion_Nivel/Librerias Kicad/green/LTST-C190KGKT/DEHDL/ltst_c190kgkt/chips/chips.prt
documentos/Diseño Mecánico/Caja/Caja.SLDDRW
documentos/Diseño Mecánico/sensor/M3x10 Philips Screw.SLDPRT
documentos/Diseño Mecánico/sensor/Screw_DIN_912_M4x10F_A2.SLDPRT
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

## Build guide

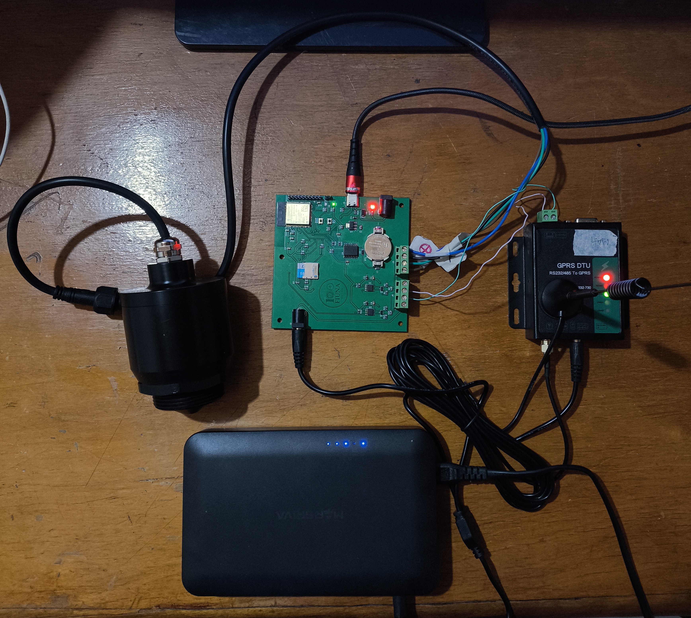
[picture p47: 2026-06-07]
documentos/Evidencias_Pruebas/capturas/Montaje_sistema.jpg

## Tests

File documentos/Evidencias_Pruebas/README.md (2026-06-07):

# Evidencias de pruebas del sistema

En esta carpeta se presentan evidencias del funcionamiento del sistema de adquisición de nivel desarrollado. Las pruebas incluyen la verificación del LED indicador, detección de tarjeta microSD, lectura del RTC DS3231, funcionamiento integrado del sistema y recuperación de datos pendientes mediante el mecanismo **Store and Forward**.

Los videos se encuentran alojados en Google Drive para evitar aumentar el tamaño del repositorio.

## Videos de pruebas

| N.º | Prueba | Descripción | Enlace |
| --- | --- | --- | --- |
| 1 | Prueba del LED azul | Se realiza una prueba simple del LED azul utilizado como indicador visual. Este LED permite verificar que el sistema detectó correctamente una lectura válida del sensor ultrasónico de nivel. | [Ver video](https://drive.google.com/file/d/1yZTbWLAMQBHtrM2hwZs7zqRO-RH48-HB/view?usp=drive_link) |
| 2 | Prueba de tarjeta microSD | Se verifica la detección de la tarjeta microSD insertada en el sistema. Esta prueba permite comprobar el funcionamiento del conector microSD y la capacidad del firmware para reconocer la presencia de la tarjeta. | [Ver video](https://drive.google.com/file/d/19R5aCAA-6pBu098gMMyVXceTk3J7X_a-/view?usp=drive_link) |
| 3 | Prueba del RTC DS3231 | Se muestra la configuración de la hora en el módulo RTC DS3231 y la lectura correcta de la fecha y hora mediante comunicación I2C. Esta prueba permite validar que el sistema puede generar marcas de tiempo para cada medición. | [Ver video](https://drive.google.com/file/d/1AH5-atD6chmUB5mobT-IkS_jdaVtZ49u/view?usp=drive_link) |
| 4 | Prueba del sistema integrado | Se observa el funcionamiento conjunto del sensor de nivel RS485, RTC DS3231, tarjeta microSD, módem DTU, LED indicador y firmware principal. Esta prueba demuestra la lectura del nivel, el almacenamiento local y el envío de datos al servidor. | [Ver video](https://drive.google.com/file/d/1fyCeK_l0-00xuTfR_rccq4oqjixhjDV9/view?usp=drive_link) |
| 5 | Prueba Store and Forward | Se evidencia el funcionamiento del mecanismo **Store and Forward**. Cuando ocurre una falla de comunicación, el dato se almacena temporalmente como pendiente y posteriormente es reenviado al servidor cuando la comunicación se restablece. | [Ver video](https://drive.google.com/file/d/12kTLneO2Io2DWGPuWARCHy4YUeFoKbM6/view?usp=drive_link) |

## Observación

Estas evidencias complementan las pruebas documentadas en el informe técnico del proyecto. Los videos permiten verificar visualmente el comportamiento de los módulos principales y del sistema completo durante las etapas de prueba e integración.

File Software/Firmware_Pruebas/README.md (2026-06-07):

# Firmware de Pruebas

Esta carpeta contiene los programas desarrollados durante la etapa de validación de hardware y software del proyecto.

## Objetivo

Cada proyecto incluido en esta carpeta fue utilizado para verificar individualmente el correcto funcionamiento de los distintos módulos antes de su integración en el firmware final.

## Pruebas realizadas

### RTC DS3231M

* Configuración de fecha y hora.
* Lectura de fecha y hora.
* Verificación de persistencia temporal.

### Tarjeta microSD

* Inicialización del módulo SD.
* Detección de inserción de tarjeta.
* Creación y lectura de archivos.
* Verificación del sistema de almacenamiento.

### Sensor de nivel RS485

* Comunicación RS485.
* Recepción y validación de tramas.
* Lectura de nivel en metros.

### Módem DTU GPRS

* Configuración mediante comandos AT.
* Verificación de conectividad.
* Envío de datos al servidor.

### Indicadores LED

* Verificación de funcionamiento de LEDs de estado.

## Importante

Estos códigos corresponden a pruebas aisladas realizadas durante el desarrollo y no representan la versión final utilizada en la estación de adquisición de nivel.

La versión definitiva del sistema se encuentra en la carpeta `Firmware_Final`.
## Modo de uso

Los distintos programas de prueba fueron integrados dentro del mismo proyecto y se ejecutan desde el archivo principal `main.c`.

Para ejecutar una prueba específica es necesario habilitar (descomentar) las líneas correspondientes dentro de la función principal y deshabilitar aquellas asociadas a otras pruebas.

Ejemplo:

```c
// Inicialización RTC
rtc_init();

// Inicialización microSD
sdcard_init();

// Prueba del sensor RS485
sensor_rs485_init();
```

Dependiendo de la prueba que se desee realizar, algunas llamadas a funciones deben comentarse o descomentarse manualmente antes de compilar y cargar el firmware en el ESP32-S3.

Esta metodología fue utilizada durante el desarrollo para validar individualmente cada módulo de hardware antes de integrarlo en el firmware final.

```
```

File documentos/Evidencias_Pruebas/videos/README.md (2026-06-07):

# Videos de pruebas

Los videos de prueba se encuentran alojados externamente en Google Drive para evitar aumentar el tamaño del repositorio. En esta carpeta se listan los enlaces a las evidencias audiovisuales utilizadas para verificar el funcionamiento de los módulos y del sistema integrado.

## Lista de videos

| N.º | Prueba | Descripción | Enlace |
| --- | --- | --- | --- |
| 1 | Prueba del LED azul | Verificación del LED indicador utilizado para señalar una lectura válida del sensor de nivel. | [Ver video](https://drive.google.com/file/d/1yZTbWLAMQBHtrM2hwZs7zqRO-RH48-HB/view?usp=drive_link) |
| 2 | Prueba de tarjeta microSD | Verificación de la detección de la tarjeta microSD y del funcionamiento del conector utilizado en la placa. | [Ver video](https://drive.google.com/file/d/19R5aCAA-6pBu098gMMyVXceTk3J7X_a-/view?usp=drive_link) |
| 3 | Prueba del RTC DS3231 | Configuración y lectura correcta de la fecha y hora desde el RTC DS3231 mediante comunicación I2C. | [Ver video](https://drive.google.com/file/d/1AH5-atD6chmUB5mobT-IkS_jdaVtZ49u/view?usp=drive_link) |
| 4 | Prueba del sistema integrado | Funcionamiento conjunto del sensor de nivel RS485, RTC DS3231, tarjeta microSD, módem DTU, LED indicador y firmware principal. | [Ver video](https://drive.google.com/file/d/1fyCeK_l0-00xuTfR_rccq4oqjixhjDV9/view?usp=drive_link) |
| 5 | Prueba Store and Forward | Prueba del mecanismo de almacenamiento y reenvío de datos pendientes cuando ocurre una falla temporal de comunicación. | [Ver video](https://drive.google.com/file/d/12kTLneO2Io2DWGPuWARCHy4YUeFoKbM6/view?usp=drive_link) |

## Observación

Los videos complementan las capturas y resultados presentados en el informe técnico. Su objetivo es evidenciar visualmente el funcionamiento de los módulos principales y del sistema completo durante las pruebas de validación.

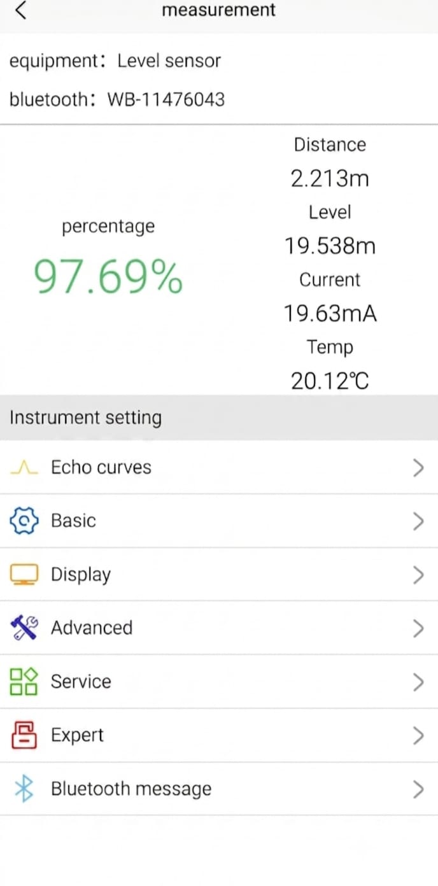
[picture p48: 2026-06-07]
documentos/Evidencias_Pruebas/capturas/apk_sensor.jpeg

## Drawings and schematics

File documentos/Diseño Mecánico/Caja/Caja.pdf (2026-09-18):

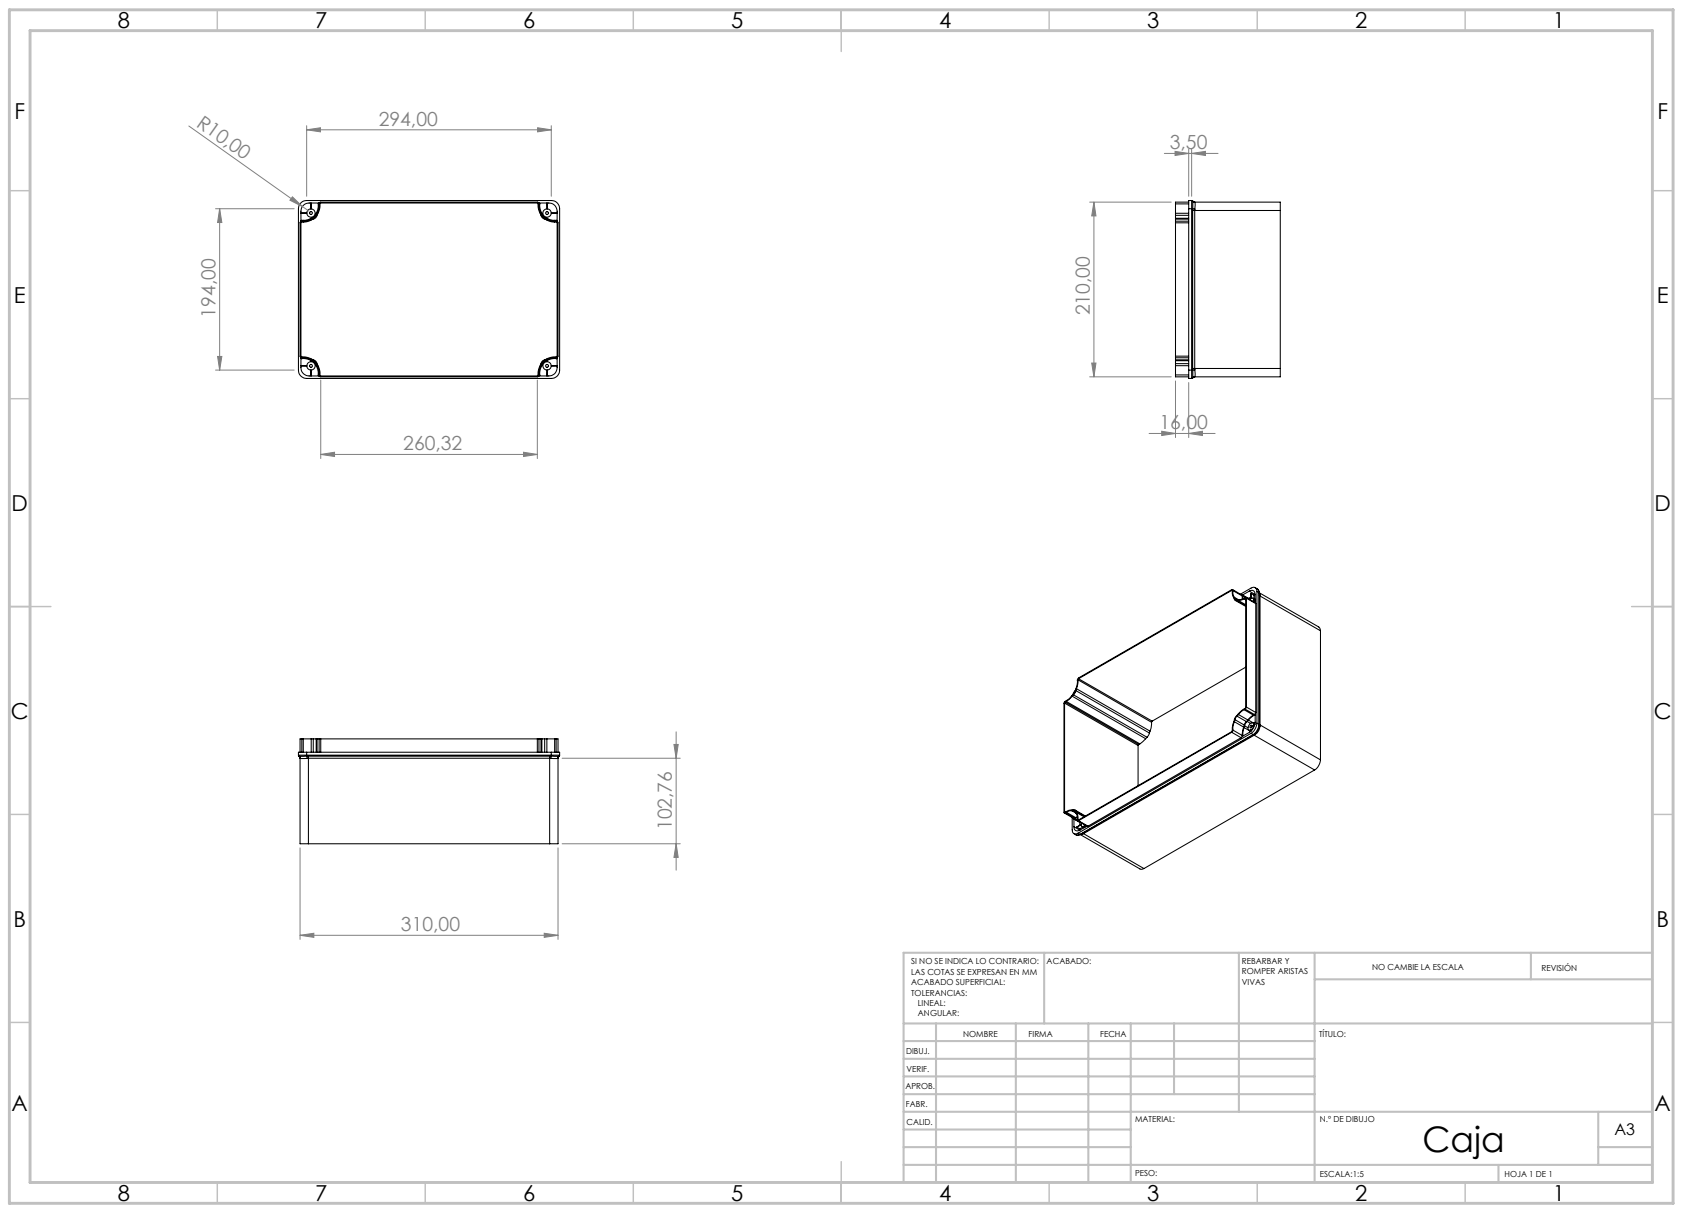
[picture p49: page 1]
ACABADO:; REBARBAR Y; ROMPER ARISTAS; NO CAMBIE LA ESCALA; REVISIÓN; ESCALA:1:5; HOJA 1 DE 1

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

NOMBRE | FIRMA | FECHA | | | | TÍTULO:

DIBUJ.
VERIF.
APROB.
FABR.
CALID. | | | | MATERIAL: | N.º DE DIBUJO Caja | A3

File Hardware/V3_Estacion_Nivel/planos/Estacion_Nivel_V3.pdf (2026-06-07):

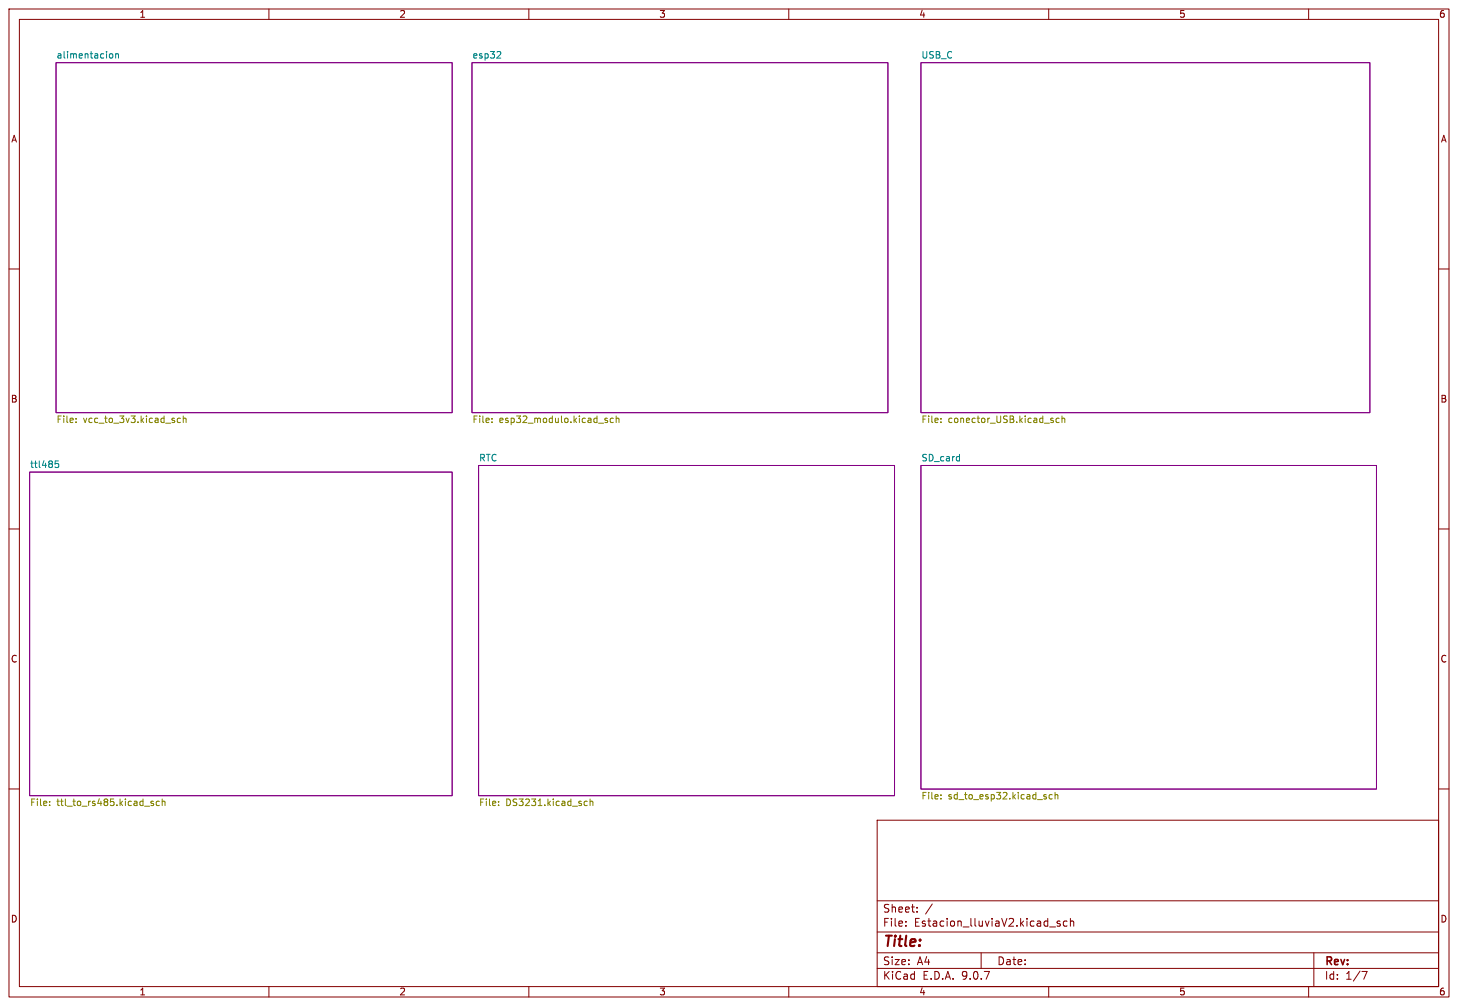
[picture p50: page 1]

Id: 1/7 Title: File: Estacion_lluviaV2.kicad_sch Sheet: /

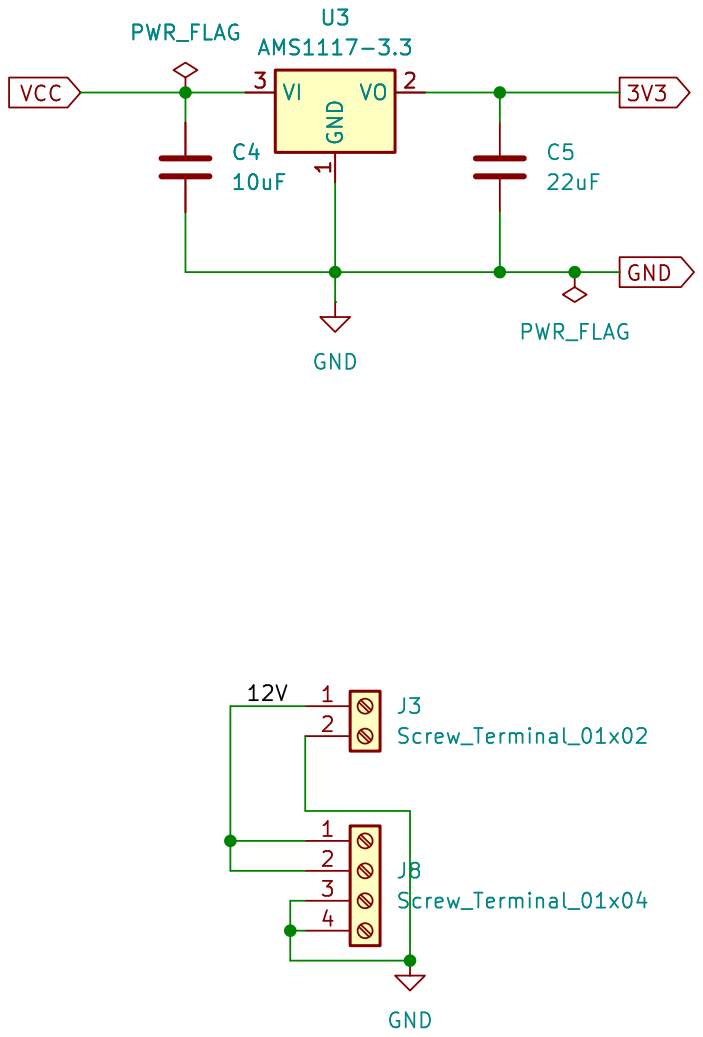
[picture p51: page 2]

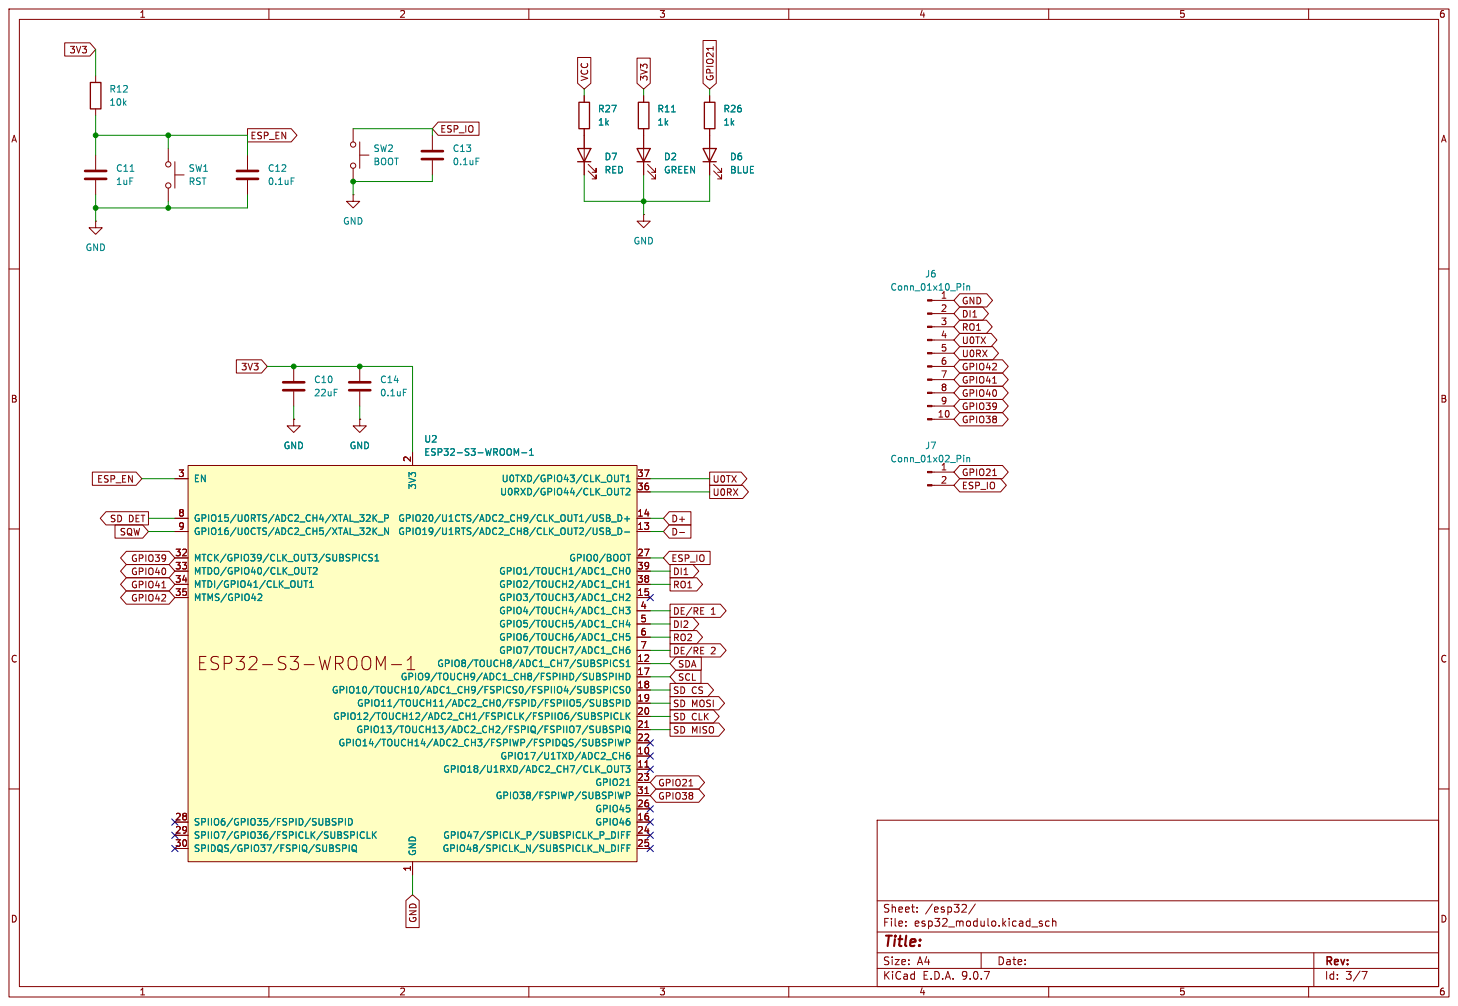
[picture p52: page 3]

RO2 SDA
SD MOSI SCL DE/RE 2 SD CS

Id: 3/7 Title: File: esp32_modulo.kicad_sch Sheet: /esp32/

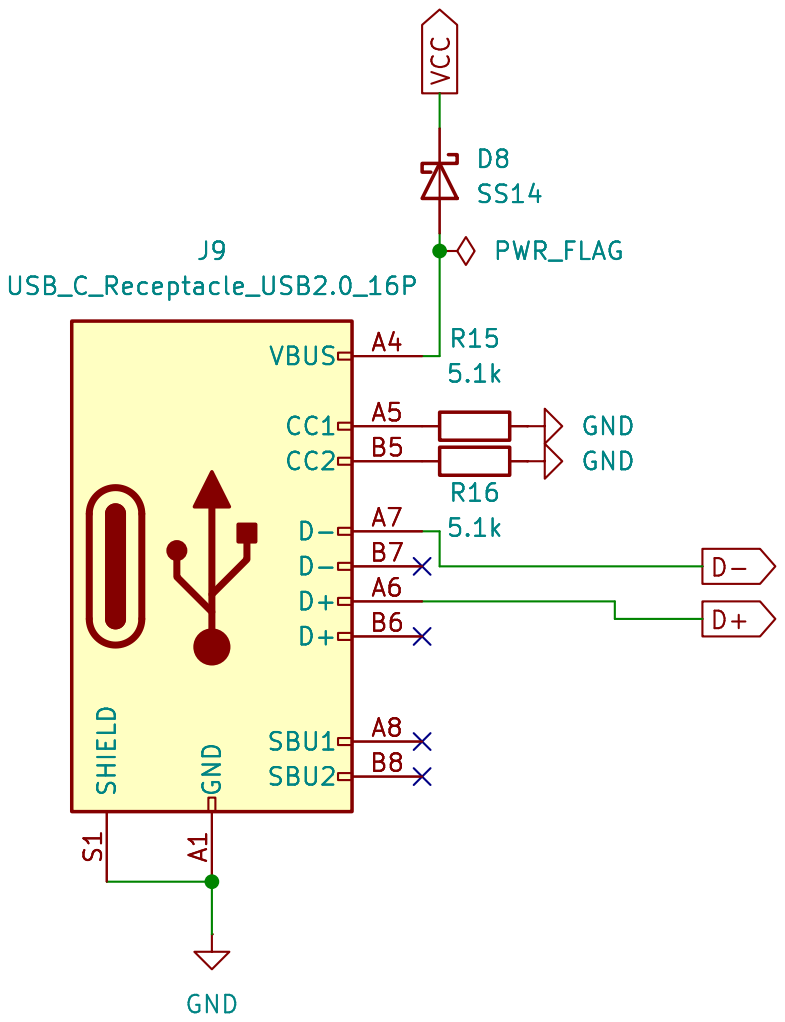
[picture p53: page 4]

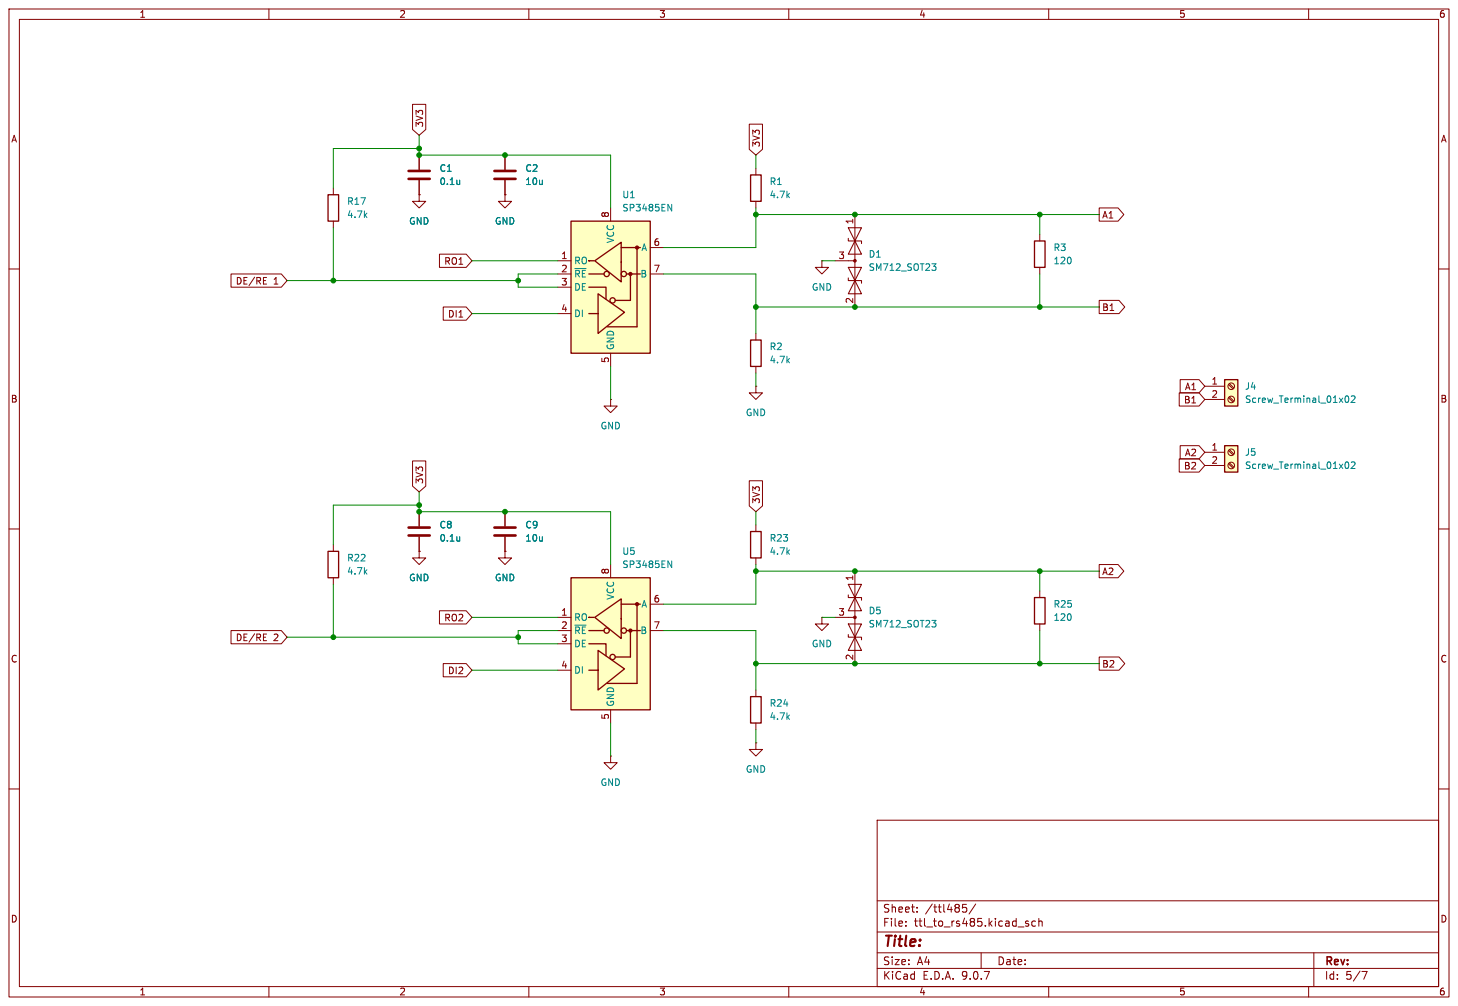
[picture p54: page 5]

Id: 5/7 Title: File: ttl_to_rs485.kicad_sch Sheet: /ttl485/ GND

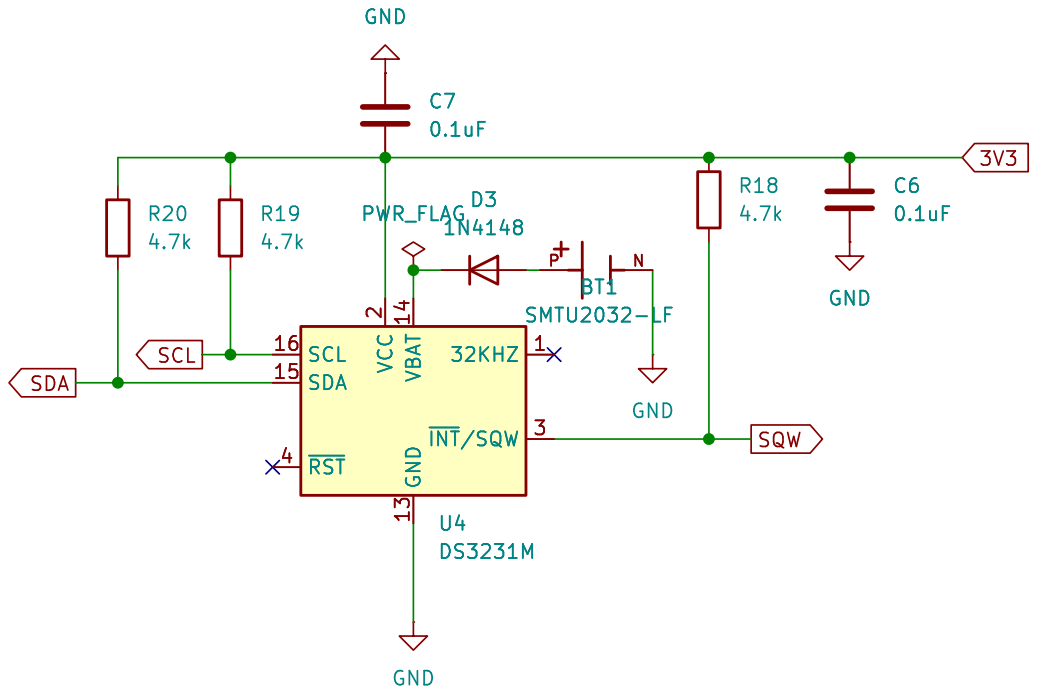
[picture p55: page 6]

Id: 6/7 Title: File: DS3231.kicad_sch Sheet: /RTC/

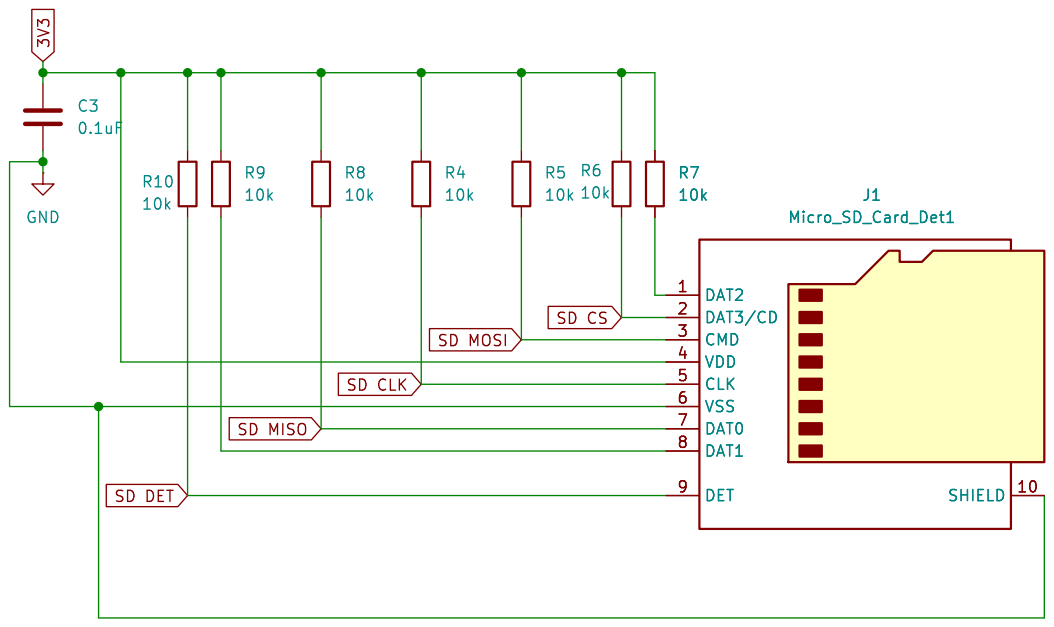
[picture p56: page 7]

Id: 7/7 Title: File: sd_to_esp32.kicad_sch Sheet: /SD_card/

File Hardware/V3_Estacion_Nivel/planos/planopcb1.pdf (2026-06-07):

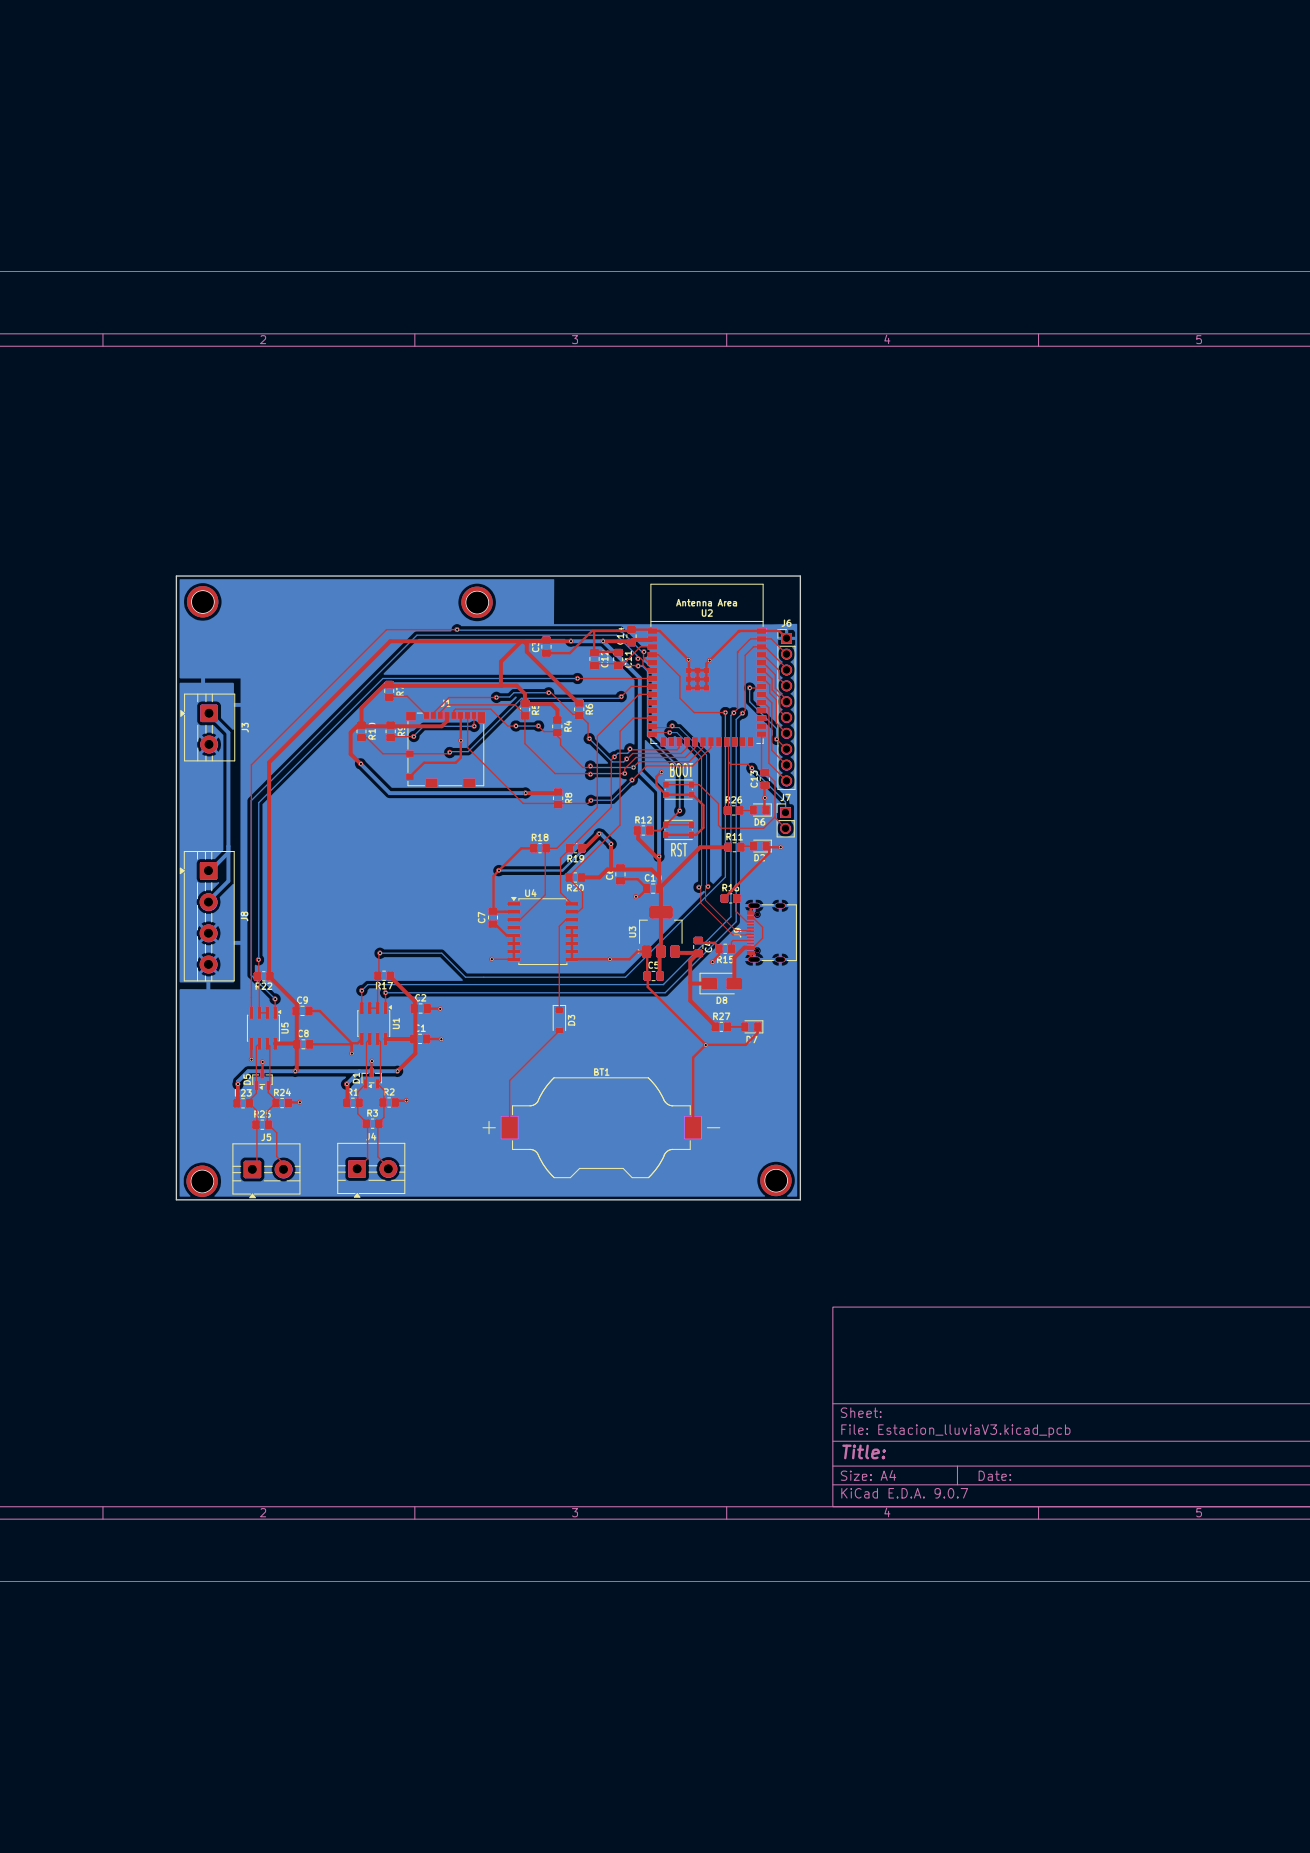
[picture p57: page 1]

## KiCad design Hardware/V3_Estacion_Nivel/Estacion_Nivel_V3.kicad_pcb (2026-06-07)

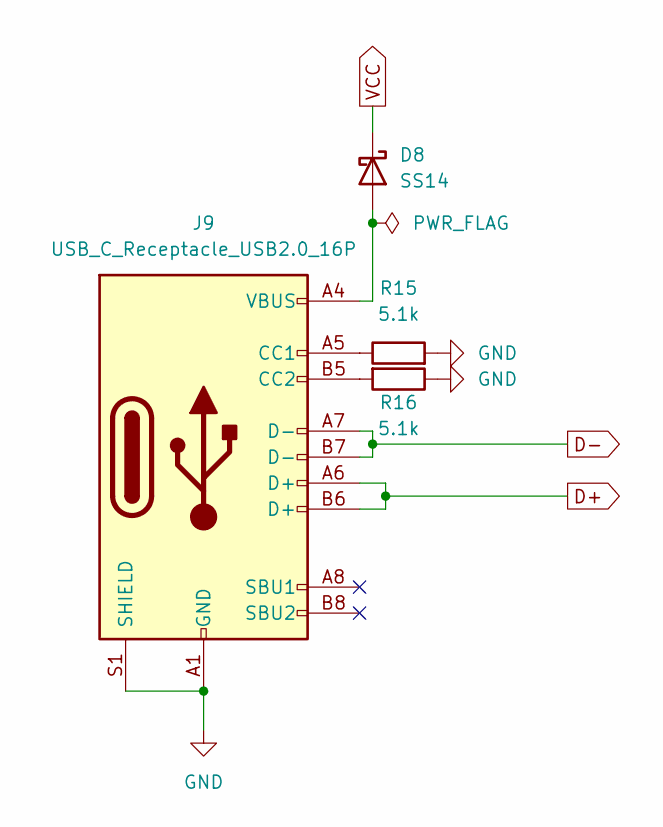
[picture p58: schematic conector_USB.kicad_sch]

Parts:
D8: SS14; D_SMA
J9: USB_C_Receptacle_USB2.0_16P; USB_C_Receptacle_Palconn_UTC16-G
R15, R16: 5.1k; R_0805_2012Metric_Pad1.20x1.40mm_HandSolder

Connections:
D+: J9.A6 (D+), J9.B6 (D+); also elsewhere on the board
D-: J9.A7 (D-), J9.B7 (D-); also elsewhere on the board
GND: J9.A1 (GND), J9.A12 (GND), J9.B1 (GND), J9.B12 (GND), J9.S1 (SHIELD), R15.2, R16.1; also elsewhere on the board
unnamed: D8.2 (A), J9.A4 (VBUS), J9.A9 (VBUS), J9.B4 (VBUS), J9.B9 (VBUS)
unnamed: J9.A5 (CC1), R15.1
unnamed: J9.B5 (CC2), R16.2
VCC: D8.1 (K); also elsewhere on the board

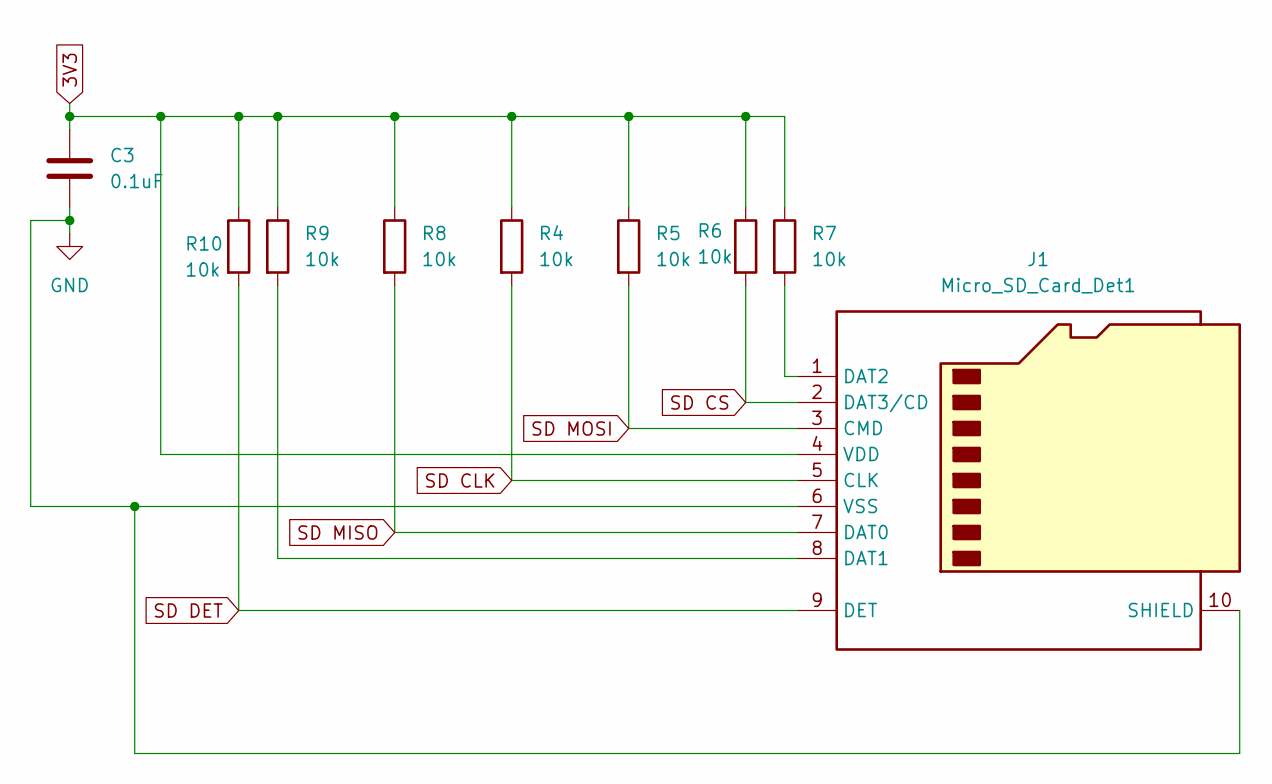
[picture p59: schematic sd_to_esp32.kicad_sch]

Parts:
C3: 0.1uF; C_0805_2012Metric_Pad1.18x1.45mm_HandSolder
J1: Micro_SD_Card_Det1; microSD_HC_Molex_104031-0811
R4, R5, R6, R7, R8, R9, R10: 10k; R_0805_2012Metric_Pad1.20x1.40mm_HandSolder

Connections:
3V3: C3.2, J1.4 (VDD), R4.1, R5.1, R6.1, R7.1, R8.1, R9.1, R10.1; also elsewhere on the board
GND: C3.1, J1.6 (VSS), J1.10 (SHIELD); also elsewhere on the board
unnamed: J1.8 (DAT1), R9.2
unnamed: J1.1 (DAT2), R7.2
SD CLK: J1.5 (CLK), R4.2; also elsewhere on the board
SD CS: J1.2 (DAT3/CD), R6.2; also elsewhere on the board
SD DET: J1.9 (DET), R10.2; also elsewhere on the board
SD MISO: J1.7 (DAT0), R8.2; also elsewhere on the board
SD MOSI: J1.3 (CMD), R5.2; also elsewhere on the board

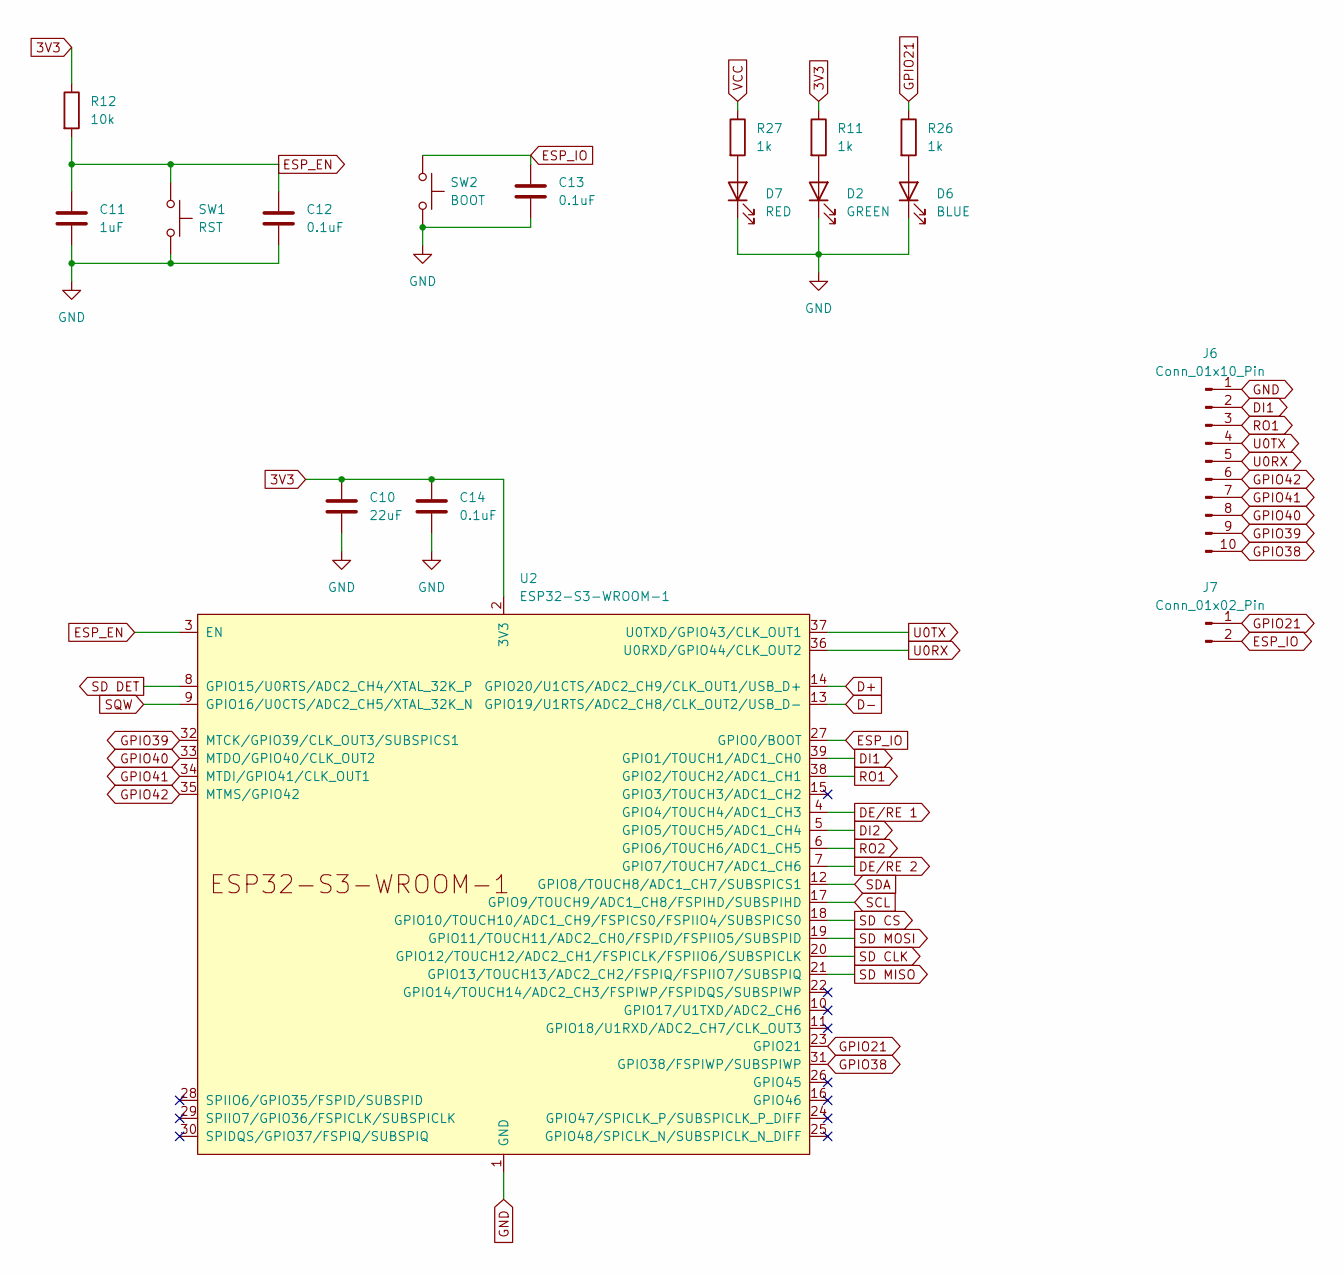
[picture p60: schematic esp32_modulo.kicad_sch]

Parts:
C10: 22uF; C_0805_2012Metric_Pad1.18x1.45mm_HandSolder
C11: 1uF; C_0805_2012Metric_Pad1.18x1.45mm_HandSolder
C12, C13, C14: 0.1uF; C_0805_2012Metric_Pad1.18x1.45mm_HandSolder
D2: GREEN; LED_0805_2012Metric_Pad1.15x1.40mm_HandSolder
D6: BLUE; LED_0805_2012Metric_Pad1.15x1.40mm_HandSolder
D7: RED; LED_0805_2012Metric_Pad1.15x1.40mm_HandSolder
J6: Conn_01x10_Pin; PinHeader_1x10_P2.54mm_Vertical
J7: Conn_01x02_Pin; PinHeader_1x02_P2.54mm_Vertical
R11, R26, R27: 1k; R_0805_2012Metric_Pad1.20x1.40mm_HandSolder
R12: 10k; R_0805_2012Metric_Pad1.20x1.40mm_HandSolder
SW1: RST; SW_Push_1P1T_NO_CK_KMR2
SW2: BOOT; SW_Push_1P1T_NO_CK_KMR2
U2: ESP32-S3-WROOM-1

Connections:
3V3: C10.2, C14.2, R11.1, R12.1, U2.2 (3V3); also elsewhere on the board
D+: U2.14 (GPIO20/U1CTS/ADC2_CH9/CLK_OUT1/USB_D+); also elsewhere on the board
D-: U2.13 (GPIO19/U1RTS/ADC2_CH8/CLK_OUT2/USB_D-); also elsewhere on the board
DE/RE 1: U2.4 (GPIO4/TOUCH4/ADC1_CH3); also elsewhere on the board
DE/RE 2: U2.7 (GPIO7/TOUCH7/ADC1_CH6); also elsewhere on the board
DI1: J6.2, U2.39 (GPIO1/TOUCH1/ADC1_CH0); also elsewhere on the board
DI2: U2.5 (GPIO5/TOUCH5/ADC1_CH4); also elsewhere on the board
ESP_EN: C11.2, C12.2, R12.2, SW1.1, U2.3 (EN)
ESP_IO: C13.2, J7.2, SW2.1, U2.27 (GPIO0/BOOT)
GND: C10.1, C11.1, C12.1, C13.1, C14.1, D2.1 (K), D6.1 (K), D7.1 (K), J6.1, SW1.2, SW2.2, U2.1 (GND), U2.40 (GND), U2.41 (GND); also elsewhere on the board
GPIO21: J7.1, R26.1, U2.23 (GPIO21)
GPIO38: J6.10, U2.31 (GPIO38/FSPIWP/SUBSPIWP)
GPIO39: J6.9, U2.32 (MTCK/GPIO39/CLK_OUT3/SUBSPICS1)
GPIO40: J6.8, U2.33 (MTDO/GPIO40/CLK_OUT2)
GPIO41: J6.7, U2.34 (MTDI/GPIO41/CLK_OUT1)
GPIO42: J6.6, U2.35 (MTMS/GPIO42)
unnamed: D2.2 (A), R11.2
unnamed: D6.2 (A), R26.2
unnamed: D7.2 (A), R27.2
RO1: J6.3, U2.38 (GPIO2/TOUCH2/ADC1_CH1); also elsewhere on the board
RO2: U2.6 (GPIO6/TOUCH6/ADC1_CH5); also elsewhere on the board
SCL: U2.17 (GPIO9/TOUCH9/ADC1_CH8/FSPIHD/SUBSPIHD); also elsewhere on the board
SD CLK: U2.20 (GPIO12/TOUCH12/ADC2_CH1/FSPICLK/FSPIIO6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); also elsewhere on the board
SD CS: U2.18 (GPIO10/TOUCH10/ADC1_CH9/FSPICS0/FSPIIO4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); also elsewhere on the board
SD DET: U2.8 (GPIO15/U0RTS/ADC2_CH4/XTAL_32K_P); also elsewhere on the board
SD MISO: U2.21 (GPIO13/TOUCH13/ADC2_CH2/FSPIQ/FSPIIO7/S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); also elsewhere on the board
SD MOSI: U2.19 (GPIO11/TOUCH11/ADC2_CH0/FSPID/FSPIIO5/S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); also elsewhere on the board
SDA: U2.12 (GPIO8/TOUCH8/ADC1_CH7/SUBSPICS1); also elsewhere on the board
SQW: U2.9 (GPIO16/U0CTS/ADC2_CH5/XTAL_32K_N); also elsewhere on the board
U0RX: J6.5, U2.36 (U0RXD/GPIO44/CLK_OUT2)
U0TX: J6.4, U2.37 (U0TXD/GPIO43/CLK_OUT1)
VCC: R27.1; also elsewhere on the board

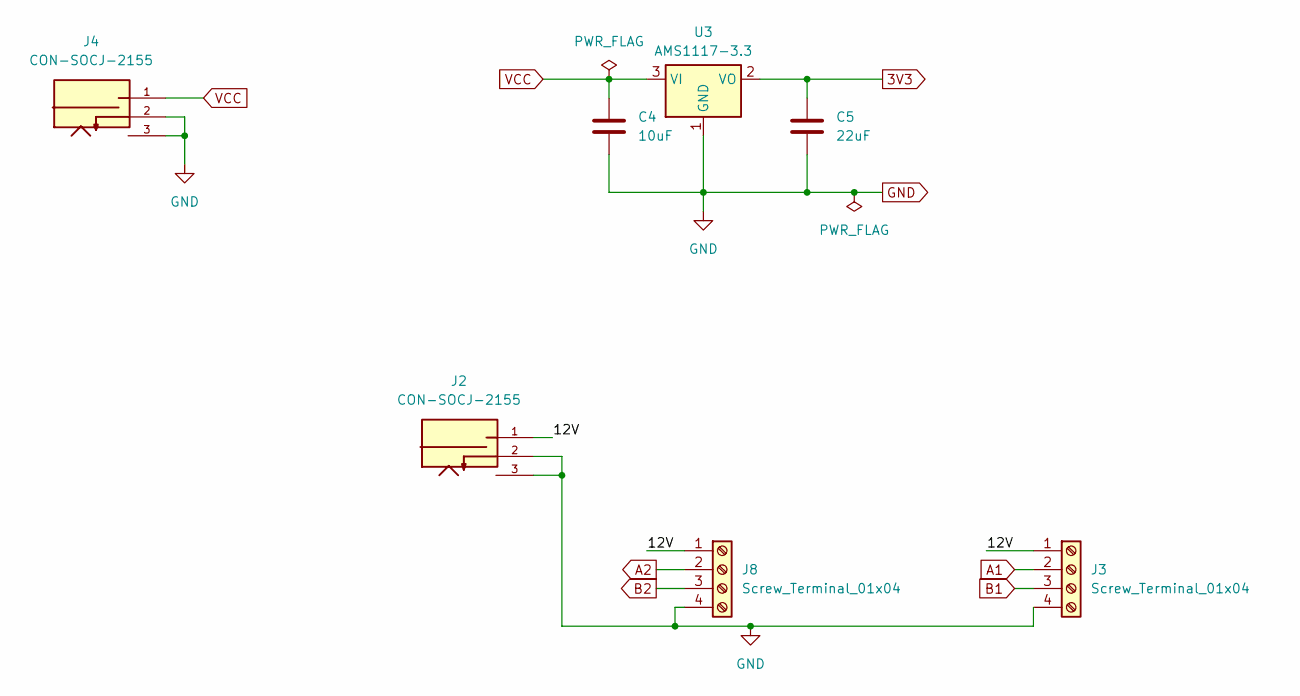
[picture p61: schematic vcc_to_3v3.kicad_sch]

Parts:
C4: 10uF; C_0805_2012Metric_Pad1.18x1.45mm_HandSolder
C5: 22uF; C_0805_2012Metric_Pad1.18x1.45mm_HandSolder
J2, J4: CON-SOCJ-2155; GRAVITECH_CON-SOCJ-2155; PARTREV NA
J3, J8: Screw_Terminal_01x04; TerminalBlock_MaiXu_MX126-5.0-04P_1x04_P5.00mm
U3: AMS1117-3.3; SOT-223-3_TabPin2

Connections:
3V3: C5.2, U3.2 (VO); also elsewhere on the board
/alimentacion/12V: J2.1, J3.1, J8.1
A1: J3.2; also elsewhere on the board
A2: J8.2; also elsewhere on the board
B1: J3.3; also elsewhere on the board
B2: J8.3; also elsewhere on the board
GND: C4.1, C5.1, J2.2, J2.3, J3.4, J4.2, J4.3, J8.4, U3.1 (GND); also elsewhere on the board
VCC: C4.2, J4.1, U3.3 (VI); also elsewhere on the board

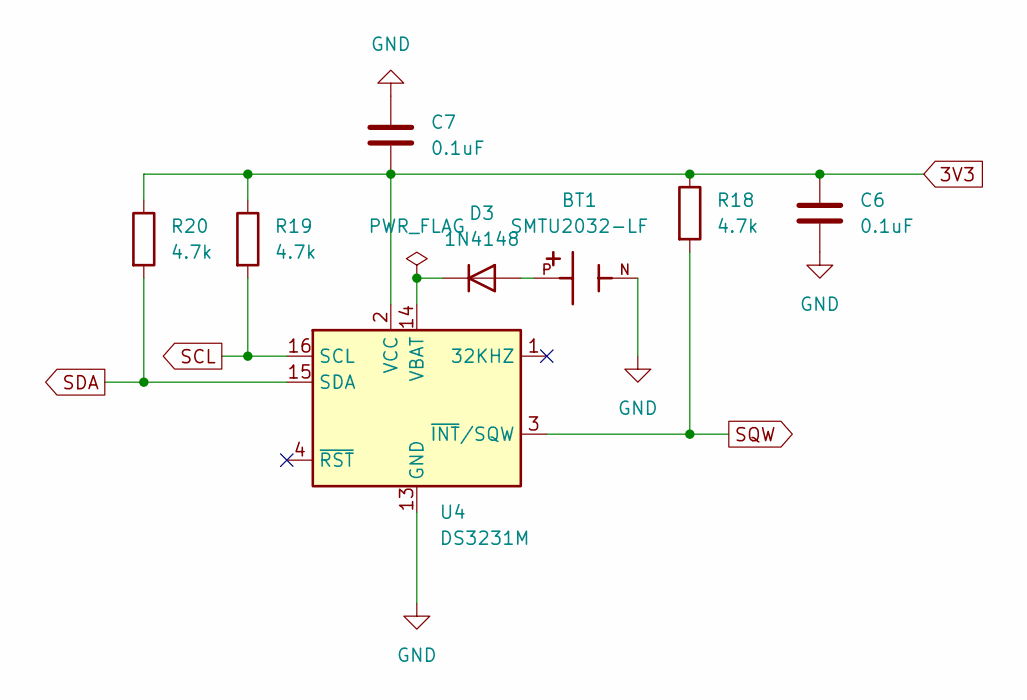
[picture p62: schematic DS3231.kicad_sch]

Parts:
BT1: SMTU2032-LF; BAT_SMTU2032-LF; PARTREV 3
C6, C7: 0.1uF; C_0805_2012Metric_Pad1.18x1.45mm_HandSolder
D3: 1N4148; D_SOD-123
R18, R19, R20: 4.7k; R_0805_2012Metric_Pad1.20x1.40mm_HandSolder
U4: DS3231M; SOIC-16W_7.5x10.3mm_P1.27mm

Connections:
3V3: C6.2, C7.1, R18.1, R19.1, R20.1, U4.2 (VCC); also elsewhere on the board
GND: BT1.N, C6.1, C7.2, U4.5 (GND), U4.6 (GND), U4.7 (GND), U4.8 (GND), U4.9 (GND), U4.10 (GND), U4.11 (GND), U4.12 (GND), U4.13 (GND); also elsewhere on the board
unnamed: BT1.P, D3.2 (A)
unnamed: D3.1 (K), U4.14 (VBAT)
SCL: R19.2, U4.16 (SCL); also elsewhere on the board
SDA: R20.2, U4.15 (SDA); also elsewhere on the board
SQW: R18.2, U4.3 (~INT/SQW); also elsewhere on the board

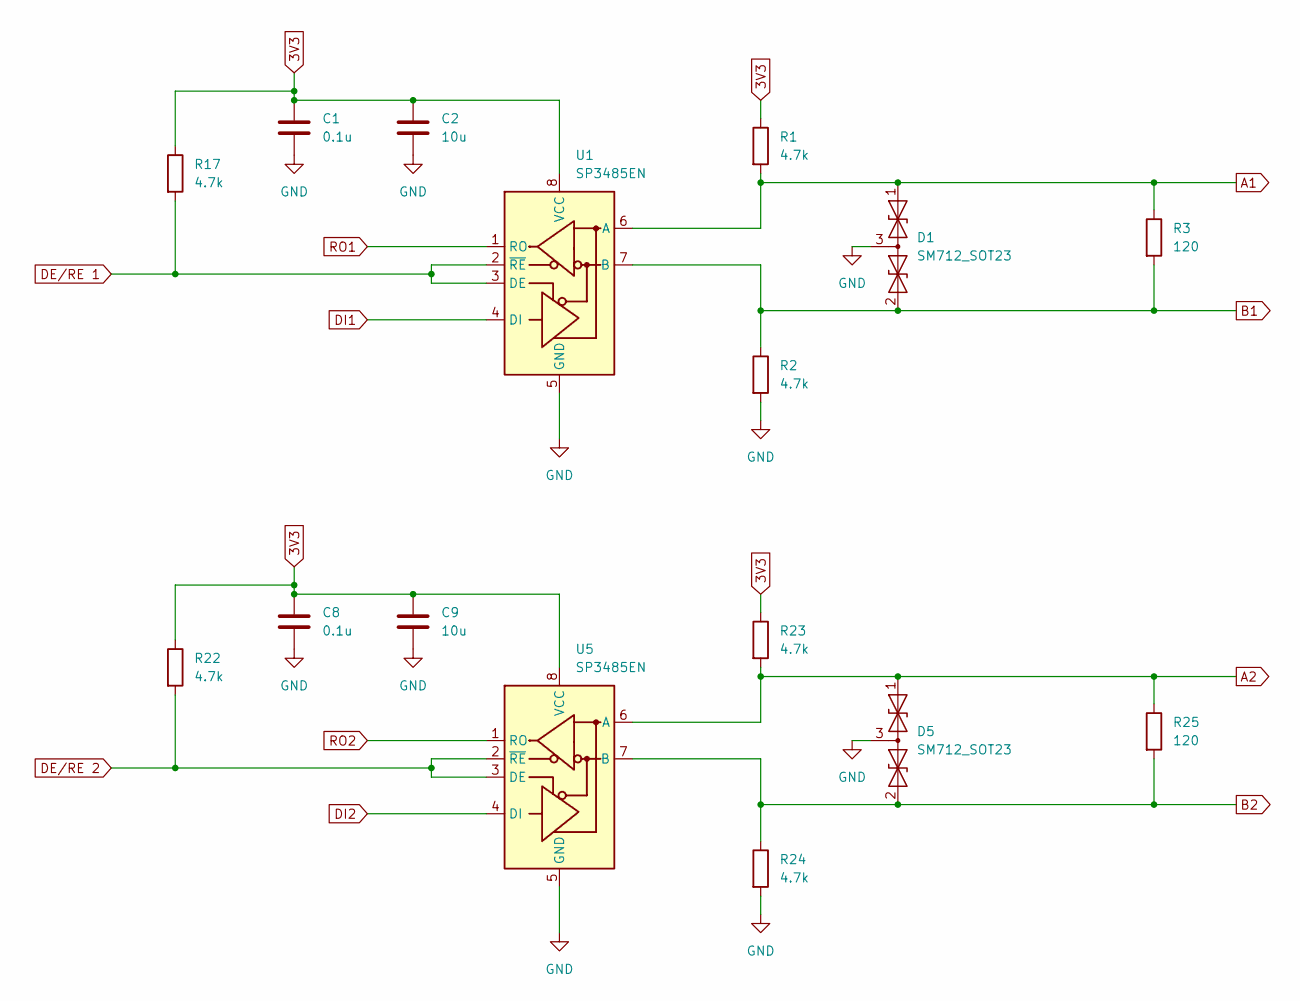
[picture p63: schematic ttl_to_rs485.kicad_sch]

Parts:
C1, C8: 0.1u; C_0805_2012Metric_Pad1.18x1.45mm_HandSolder
C2, C9: 10u; C_0805_2012Metric_Pad1.18x1.45mm_HandSolder
D1, D5: SM712_SOT23; SOT-23
R1, R2, R17, R22, R23, R24: 4.7k; R_0805_2012Metric_Pad1.20x1.40mm_HandSolder
R3, R25: 120; R_0805_2012Metric_Pad1.20x1.40mm_HandSolder
U1, U5: SP3485EN; SOIC-8_3.9x4.9mm_P1.27mm

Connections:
3V3: C1.1, C2.1, C8.1, C9.1, R1.1, R17.1, R22.1, R23.1, U1.8 (VCC), U5.8 (VCC); also elsewhere on the board
A1: D1.1 (A1), R1.2, R3.1, U1.6 (A); also elsewhere on the board
A2: D5.1 (A1), R23.2, R25.1, U5.6 (A); also elsewhere on the board
B1: D1.2 (A2), R2.1, R3.2, U1.7 (B); also elsewhere on the board
B2: D5.2 (A2), R24.1, R25.2, U5.7 (B); also elsewhere on the board
DE/RE 1: R17.2, U1.2 (~RE), U1.3 (DE); also elsewhere on the board
DE/RE 2: R22.2, U5.2 (~RE), U5.3 (DE); also elsewhere on the board
DI1: U1.4 (DI); also elsewhere on the board
DI2: U5.4 (DI); also elsewhere on the board
GND: C1.2, C2.2, C8.2, C9.2, D1.3 (common), D5.3 (common), R2.2, R24.2, U1.5 (GND), U5.5 (GND); also elsewhere on the board
RO1: U1.1 (RO); also elsewhere on the board
RO2: U5.1 (RO); also elsewhere on the board

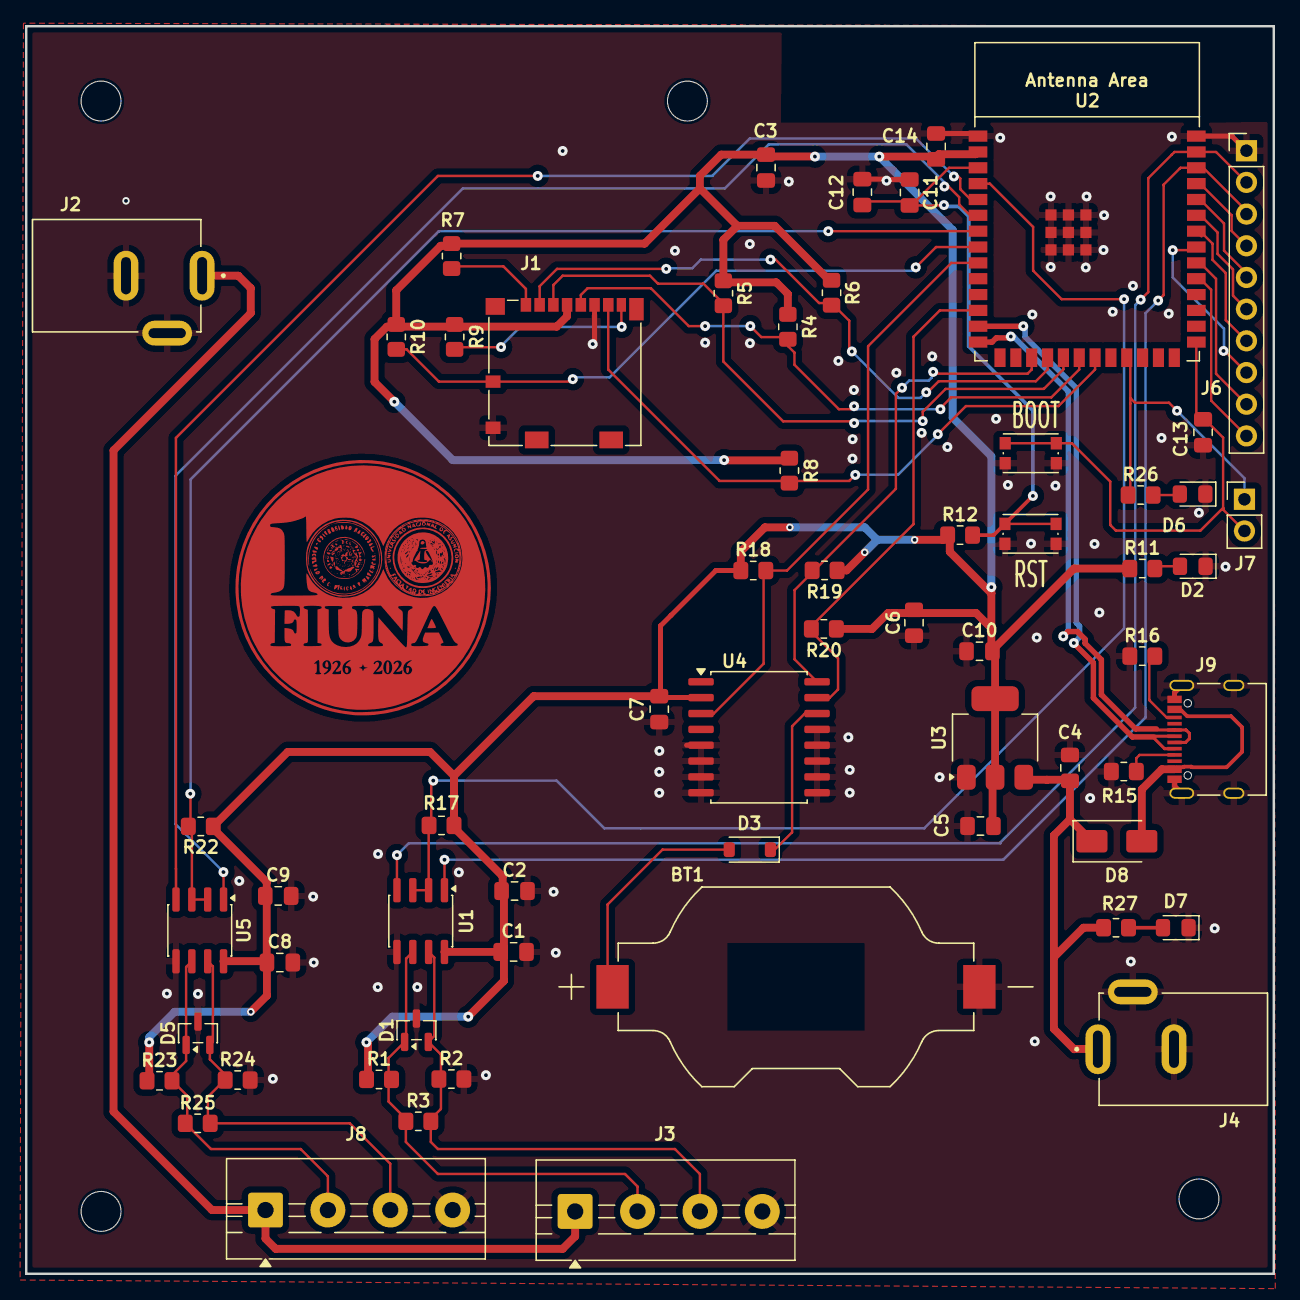
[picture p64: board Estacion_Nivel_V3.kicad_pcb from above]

Board: 2 copper layers, 100.0 x 100.0 mm, 61 parts (0 on the bottom side), 44 nets.

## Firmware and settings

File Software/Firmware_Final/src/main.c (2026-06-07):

#include <stdio.h>
#include <stdint.h>
#include <stdbool.h>
#include "esp_log.h"
#include "freertos/FreeRTOS.h"
#include "freertos/task.h"
#include "freertos/semphr.h"
#include "reloj.h"
#include "led_blink.h"
#include "sdcard.h"
#include "sensor_rs485.h"
#include "modem_dtu.h"

static const char *TAG = "MAIN";
static SemaphoreHandle_t dtu_mutex;


// ======================================================
// ENVIO DTU PARA CICLO PRINCIPAL
// Espera mas tiempo porque tiene prioridad.
// ======================================================

static bool dtu_send_level_main(uint32_t timestamp, float nivel)
{
    bool ok = false;

    if (xSemaphoreTake(dtu_mutex, pdMS_TO_TICKS(30000)) == pdTRUE)
    {
        ok = dtu_send_level(timestamp, nivel);
        xSemaphoreGive(dtu_mutex);
    }
    else
    {
        ESP_LOGW(TAG, "DTU ocupado. No se pudo enviar dato actual");
    }

    return ok;
}

// ======================================================
// ENVIO DTU PARA PENDIENTES
// Espera poco. Si el DTU esta ocupado, no molesta al ciclo principal.
// ======================================================

static bool dtu_send_level_bg(uint32_t timestamp, float nivel)
{
    bool ok = false;

    if (xSemaphoreTake(dtu_mutex, pdMS_TO_TICKS(1000)) == pdTRUE)
    {
        ok = dtu_send_level(timestamp, nivel);
        xSemaphoreGive(dtu_mutex);
    }
    else
    {
        ESP_LOGW(TAG, "DTU ocupado. Pendiente queda en cola");
    }

    return ok;
}

// ======================================================
// TASK DE PENDIENTES EN SEGUNDO PLANO
// ======================================================
#define MARGEN_BG_SLOT_S 35
static void task_pendientes(void *pv)
{
    while (1)
    {
        rtc_datetime_t dt;

        if (reloj_now(&dt))
        {
            uint32_t espera_s = reloj_segundos_hasta_proximo_slot_5min(&dt);

            if (espera_s > MARGEN_BG_SLOT_S)
            {
                uint32_t ts;
                float nivel;

                if (sdcard_has_pending() &&
                    sdcard_read_first_pending(&ts, &nivel))
                {
                    ESP_LOGI(TAG,
                             "BG reenviando pendiente: d=%lu,%.3f",
                             (unsigned long)ts,
                             nivel);

                    if (dtu_send_level_bg(ts, nivel))
                    {
                        sdcard_remove_first_pending();
                        ESP_LOGI(TAG, "BG pendiente enviado y eliminado");
                    }
                    else
                    {
                        ESP_LOGW(TAG, "BG fallo reenvio. Cola conservada");
                    }
                }
            }
            else
            {
                ESP_LOGI(TAG,
                         "BG no envia: faltan %lu s para el proximo slot",
                         (unsigned long)espera_s);
            }
        }

        vTaskDelay(pdMS_TO_TICKS(5000));
    }
}

// ======================================================
// APP MAIN
// ======================================================

void app_main(void)
{   


    
    ESP_LOGI(TAG, "Iniciando sistema solo nivel...");

    reloj_init();
    sdcard_init();
    sensor_rs485_init();
    dtu_init();
    led_init();
    dtu_mutex = xSemaphoreCreateMutex();

    xTaskCreate(
             task_pendientes,
             "task_pendientes",
             4096,
             NULL,
             4,
            NULL
              );

    while (1)
    {
        rtc_datetime_t dt;

        if (!reloj_now(&dt))
        {
            ESP_LOGE(TAG, "No se pudo leer RTC");
            vTaskDelay(pdMS_TO_TICKS(5000));
            continue;
        }

        uint32_t espera_s = reloj_segundos_hasta_proximo_slot_5min(&dt);

        if (espera_s > 0)
        {
            ESP_LOGI(TAG,
                     "Esperando %lu s hasta proximo slot",
                     (unsigned long)espera_s);

            vTaskDelay(pdMS_TO_TICKS(espera_s * 1000));
            continue;
        }
   
        float nivel_m = 0.0f;
        uint32_t timestamp = reloj_datetime_to_epoch(&dt) + (3 * 3600);

        char fecha[32];
        reloj_format(&dt, fecha, sizeof(fecha));

        ESP_LOGI(TAG, "Procesando slot RTC: %s", fecha);

        bool lectura_ok = false;

        for (int intento = 1; intento <= 3; intento++)
        {
            ESP_LOGI(TAG, "Intento lectura sensor %d/3", intento);

            if (sensor_rs485_read_level(&nivel_m))
            {
                led_blink_sensor_ok();
                lectura_ok = true;
                break;
            }

            ESP_LOGW(TAG, "Fallo lectura sensor, reintentando...");
            vTaskDelay(pdMS_TO_TICKS(1000));
        }

        if (!lectura_ok)
        {
            ESP_LOGE(TAG, "No se pudo leer nivel luego de 3 intentos");
            nivel_m = -1.0f;
        }

        // Guardar SIEMPRE en datalog.csv
        sdcard_append_level(timestamp, nivel_m);

        // Enviar SIEMPRE el dato actual primero
        if (!dtu_send_level_main(timestamp, nivel_m))
        {
            ESP_LOGW(TAG, "Fallo envio actual. Guardando pendiente");
            sdcard_append_pending(timestamp, nivel_m);
        }

        ESP_LOGI(TAG,
                 "Ciclo terminado: d=%lu,%.3f",
                 (unsigned long)timestamp,
                 nivel_m);

        vTaskDelay(pdMS_TO_TICKS(1000));
    }
}

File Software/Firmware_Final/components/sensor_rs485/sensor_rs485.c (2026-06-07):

#include "sensor_rs485.h"

#include <stdio.h>
#include "freertos/FreeRTOS.h"
#include "freertos/task.h"
#include "driver/uart.h"
#include "driver/gpio.h"
#include "esp_log.h"
#include "esp_rom_sys.h"

// ======================================================
// PINES SENSOR RS485 NIVEL
// ======================================================

#define SENSOR_UART_PORT UART_NUM_1
#define SENSOR_TX_PIN    GPIO_NUM_1
#define SENSOR_RX_PIN    GPIO_NUM_2
#define SENSOR_DE_RE_PIN GPIO_NUM_4

#define SENSOR_BAUD_RATE 9600
#define SENSOR_BUF_SIZE  256

static const char *TAG = "SENSOR_RS485";

// Comando Modbus: ID 1, función 03, registro 0x0000, cantidad 1
static const uint8_t CMD_READ_LEVEL[] = {
    0x01, 0x03, 0x00, 0x00, 0x00, 0x01, 0x84, 0x0A
};

bool sensor_rs485_init(void)
{
    uart_config_t uart_config = {
        .baud_rate = SENSOR_BAUD_RATE,
        .data_bits = UART_DATA_8_BITS,
        .parity    = UART_PARITY_DISABLE,
        .stop_bits = UART_STOP_BITS_1,
        .flow_ctrl = UART_HW_FLOWCTRL_DISABLE,
        .source_clk = UART_SCLK_DEFAULT,
    };

    uart_driver_install(SENSOR_UART_PORT, SENSOR_BUF_SIZE * 2, 0, 0, NULL, 0);

    uart_param_config(SENSOR_UART_PORT, &uart_config);

    uart_set_pin(
        SENSOR_UART_PORT,
        SENSOR_TX_PIN,
        SENSOR_RX_PIN,
        UART_PIN_NO_CHANGE,
        UART_PIN_NO_CHANGE
    );

    gpio_reset_pin(SENSOR_DE_RE_PIN);

    gpio_set_direction(
        SENSOR_DE_RE_PIN,
        GPIO_MODE_OUTPUT
    );

    gpio_set_level(SENSOR_DE_RE_PIN, 0);

    ESP_LOGI(TAG, "Sensor RS485 inicializado");

    // ==============================
    // Lectura de descarte
    // ==============================

    float dummy;

    sensor_rs485_read_level(&dummy);

    vTaskDelay(pdMS_TO_TICKS(500));

    return true;
}

bool sensor_rs485_read_level(float *level_m)
{
    if (level_m == NULL) return false;

    uint8_t buffer[32];

    uart_flush(SENSOR_UART_PORT);
    uart_flush_input(SENSOR_UART_PORT);
    vTaskDelay(pdMS_TO_TICKS(50));

    gpio_set_level(SENSOR_DE_RE_PIN, 1);
    esp_rom_delay_us(300);

    uart_write_bytes(
        SENSOR_UART_PORT,
        (const char *)CMD_READ_LEVEL,
        sizeof(CMD_READ_LEVEL)
    );

    uart_wait_tx_done(SENSOR_UART_PORT, pdMS_TO_TICKS(15));

    gpio_set_level(SENSOR_DE_RE_PIN, 0);
    esp_rom_delay_us(300);

    int len = uart_read_bytes(
        SENSOR_UART_PORT,
        buffer,
        sizeof(buffer),
        pdMS_TO_TICKS(800)
    );

    if (len < 5) {
        ESP_LOGW(TAG, "Sin respuesta válida del sensor");
        return false;
    }

    if (buffer[0] != 0x01 || buffer[1] != 0x03) {
        ESP_LOGW(TAG, "Respuesta inesperada");
        ESP_LOG_BUFFER_HEX(TAG, buffer, len);
        return false;
    }

    uint16_t raw = ((uint16_t)buffer[3] << 8) | buffer[4];

    *level_m = raw / 1000.0f;

    ESP_LOGI(TAG, "Nivel leído: %.3f m", *level_m);

    return true;
}
